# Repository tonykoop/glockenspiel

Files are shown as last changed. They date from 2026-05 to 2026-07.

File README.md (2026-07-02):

# Glockenspiel

**Status:** L2 V5 build-packet candidate; not a build-ready L3 packet (no bar
has been cut, struck, mounted, or measured yet).

V5 build-packet candidate over the root-mode v4.3 public-review packet for a 25-bar chromatic
glockenspiel / metallophone, C5 to C7, with a smaller C-major pentatonic
art-fair variant. The design uses 6061-T6 aluminum flat bars on a CNC-routed
walnut frame with cord-and-grommet free-free suspension.

Part of the [tonykoop/instrument-maker](https://github.com/tonykoop/instrument-maker)
catalogue. Sister repos: [xylophone](https://github.com/tonykoop/xylophone),
[tubular-bells](https://github.com/tonykoop/tubular-bells),
[cajon](https://github.com/tonykoop/cajon), and
[rainstick](https://github.com/tonykoop/rainstick).

## Status

This repo is a V5 build-packet candidate and L2 design/sourcing handoff, not a
build-ready L3 packet.
The bar schedule, frame plan, CAD/CNC handoffs, sourcing tables, validation
workflow, capstone deck, print packet, and static site are present for human
review. No bar has been cut, struck, mounted, or measured yet; all pitch values
are predictions until `validation.csv` contains pilot data.

The first physical pass should cut only three pilot bars: C5, A5, and C7. Cut
them long, measure them on soft node supports, compute effective K for the
actual stock lot, then update the family table before cutting the full set.

## Design Overview

- **Family:** 25 chromatic bars from C5 to C7 plus a 10-bar C-major pentatonic
  variant for short workshop or art-fair builds.
- **Governing model:** free-free metal beam in the first flexural mode,
  `f ~= K * t / L^2`, with node holes at 22.4 percent and 77.6 percent of bar
  length.
- **Primary material:** 6061-T6 aluminum, 0.250 in thick by 1.000 in wide.
  Brass, steel, stainless, and phosphor bronze alternatives are documented in
  `design.md`.
- **Frame:** black-walnut piano-keyboard layout with naturals forward, sharps
  raised behind, and stainless support rods as travel restraints.
- **Mounting:** paracord or low-stretch nylon through drilled node holes,
  supported on rubber grommets. Grommet durometer remains a pilot-build test.
- **Tuning:** cut long, measure, recalibrate K if needed, then trim ends
  symmetrically to pitch. Do not apply flute, Helmholtz, or cantilever
  empirical corrections to this free-free metal-beam model.

## Packet Map

| File / folder | What it is |
|---|---|
| `glockenspiel-design-table.xlsx` | Parametric workbook source for the active family. |
| `design.md` | Governing model, material matrix, bar schedule, frame layout, validation plan, and assumptions. |
| `family-spec.csv` | 25-bar chromatic schedule plus 10-bar pentatonic variant. |
| `bom.csv`, `sourcing.csv`, `cut-list.csv` | Build bill of materials, supplier-ready specs, and cut operations. |
| `validation.csv` | Pilot and full-family measurement workflow for flat, drilled, mounted, and framed phases. |
| `validation-loop.csv`, `authority-ledger.csv` | Claim-to-evidence gates for bar dimensions, node support, metallurgy, tuning, and frame release. |
| `visual-output-register.csv` | Validator-facing record that keeps SVG/PDF/site outputs downstream of design-table/CAD authority. |
| `assembly-manual.md` | Step-by-step fabrication and assembly notes. |
| `supplier-rfq.md` | RFQ draft for bar stock, frame stock, grommets, cord, rods, and mallets. |
| `drawing-brief.md`, `visual-bom-brief.md` | Drawing and visual BOM requirements. |
| `wolfram-starter.wl` | Parametric notebook starter for bar length, node, and validation plots. |
| `risks.md` | Red-team review of tuning, mounting, sourcing, safety, and release risks. |
| `jig-decision.md`, `resources.md` | v4.3 manufacturing-decision adjuncts and public-safe references. |
| `cad/mcp-session-log.md` | V5 provenance log for fabrication-authority artifacts (design table, family-spec, CAD masters). |
| `evolution/` | Evolution-pipeline Stage 0 intake: master manifest, design-intent, and revision register (Gate A not yet run). |
| `cad/` | OpenSCAD starter, SolidWorks master-layout plan, and design-table inputs. |
| `cnc/` | CNC operation graph and setup sheet for the walnut frame and fixtures. |
| `drawings/` | First-cut SVG sheets for bars, frame, mounting, family overview, and visual BOM. |
| `capstone-deck.md` / `.pptx` | Recruiter-facing slide deck. |
| `print-packet.md` / `.html` / `.pdf` | Shop-printable packet. |
| `site/` | Static build-log site draft. |
| `explorer.html` | Root V5 packet explorer for review status and authority boundaries. |

## V5 Candidate Review Evidence

- `jq . capstone-manifest.json` checks the repo-relative manifest.
- `test -f explorer.html` checks the Round 31 explorer deliverable.
- `python3 ${CODEX_HOME:-$HOME/.codex}/skills/instrument-maker/scripts/validate_visual_authority.py visual-output-register.csv`
  checks visual/CAD/design-table authority boundaries.
- `python3 ${CODEX_HOME:-$HOME/.codex}/skills/instrument-maker/scripts/validate_acoustic_law.py family-spec.csv`
  is expected to skip acoustic-law enforcement because this is an idiophone,
  not a wind or free-reed family.
- `git diff --check` should pass before PR.
- Existing generated binaries (`capstone-deck.pptx` and `print-packet.pdf`)
  are included as review artifacts, but they are not evidence of measured
  tuning or build readiness.

Deferred gates:

- empirical bar K calibration from C5/A5/C7 pilot cuts
- grommet-durometer sustain comparison
- final framed tuning within the cents band in `validation.csv`
- SolidWorks-native release drawing review
- live supplier price, stock, and lead-time verification
- generated SVG/PDF/site/explorer artifacts staying downstream of design-table,
  CAD, or measured authority

## License

[CC BY 4.0](LICENSE) - see LICENSE for details.

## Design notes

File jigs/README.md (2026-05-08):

# Jigs

This folder collects the build outputs of the pilot fixtures decided in `../jig-decision.md`. The decisions live there; physical jig artifacts (drawings, CNC files, photos) land here as they are built.

## Pilot Jig Set

| Jig ID | Purpose | Decision in jig-decision.md | Output here once built |
| --- | --- | --- | --- |
| JD-010 | Stock receiving / verification station | Marking and inspection only | inspection-checklist.pdf (TBD) |
| JD-020 | Stop-block sled for length and node marking | Repeatable bar marking | sled.svg, sled-build-notes.md (TBD) |
| JD-030 | Chop-saw stop block | Square cuts to length | (built and adjusted in shop; no committed file) |
| JD-040 | Drill-press V-block jig for node holes | Aligned, perpendicular drilling | vblock-jig.svg, vblock-jig-build-notes.md (TBD) |
| JD-050 | Foam node-support cradle for strike test | Acoustic measurement datum | foam-cradle-photo.jpg (TBD) |
| JD-060 | Mounting prototype rig (three walnut blocks) | Durometer pilot | mounting-rig.svg, durometer-pilot-results.csv (TBD) |
| JD-070 | Full-size frame layout template | Ergonomic reach validation | frame-template.pdf (TBD) |

## Pilot Gate

Build only JD-010 through JD-050 for the C5/A5/C7 pilot. JD-060 follows after pilot bars are trimmed. JD-070 follows after the durometer is selected. JD-070 must be ergonomically verified before any walnut is cut.

See `../jig-decision.md` for full pass/fail criteria and the rejected fixture options.

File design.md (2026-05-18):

# Glockenspiel Design Packet

## Project Intent

Build a 25-bar chromatic C5-C7 glockenspiel from the existing workbook design table, with a parallel 10-bar C-major-pentatonic art-fair variant that shares the same aluminum stock, frame jig, and validation discipline. The first build target is a CNC-routed walnut frame carrying 6061-T6 aluminum bars, suspended at the free-free nodes by rubber-grommeted cord through drilled node holes, with stainless support pins and no resonators.

The useful boundary for this packet is "build-ready documentation, not finished CAD or measured tuning data." Native SolidWorks files do not exist yet; the `cad/` folder defines the global-variable and design-table contract Tony can use to build the real model. All published bar lengths are first-pass cut-long targets — actual K varies with heat-treat and stock lot, so every bar should be cut at predicted length plus 0.25 in trim allowance and tuned down to pitch.

Round 31 adds an explicit V5 authority layer: `authority-ledger.csv`,
`validation-loop.csv`, and `visual-output-register.csv`. Those files do not
promote the packet to build-ready status; they make clear which claims are
design-table-derived, which are supplier/material assumptions, and which are
blocked on measured pilot evidence.

## Design Intake

| Field | Value |
| --- | --- |
| Instrument | Glockenspiel / Metallophone |
| Instrument family | Free-free beam idiophone (metal), no arch, no resonator |
| Active build range | C5-C7 chromatic, 25 bars (primary); C-major pentatonic, 10 bars (art-fair variant) |
| Source workbook | `glockenspiel-design-table.xlsx`, sheet `Glockenspiel`, range `A1:L174` |
| Primary material | 6061-T6 Aluminum, workbook K constant `204431` |
| Bar stock | `0.25 in` thick x `1.00 in` wide flat bar |
| Frame | CNC-routed Black Walnut, piano-keyboard layout (naturals front, sharps back) |
| Mounting | Cord through node holes at 22.4% and 77.6% of bar length, rubber grommets, 1/8 in stainless support rod |
| Done-bar reference | `tonykoop/marimba` for free-free node math and validation discipline; tongue-drum README for documentation shape |

## Governing Model

### Bar Pitch (Free-Free Beam, Metal)

Glockenspiel bars are treated as free-free beams in their first flexural mode:

```text
lambda_1 = 4.730
f_1 = (lambda_1^2 / (2*pi*L^2)) * sqrt(E*I/(rho*A))
```

The workbook uses the practical shop form:

```text
f ~= K * t / L^2
L ~= sqrt(K * t / f)
```

where:

- `f` is target frequency in Hz.
- `K` is the metal-specific free-free bar constant in imperial units.
- `t` is bar thickness in inches.
- `L` is bar length in inches.

For the active packet:

```text
material = 6061-T6 Aluminum
K = 204431
t = 0.250 in
w = 1.000 in
```

The K formula derived from the lambda_1 = 4.730 mode shape is:

```text
K_metal = (lambda_1^2 / (2 * pi)) * sqrt(E / (12 * rho)) / 0.0254
```

with `E` in Pa and `rho` in kg/m^3. This is the same formula family used by the marimba for wooden bars; only the material constants change.

Width does NOT affect frequency for a free-free beam in this mode. Width controls volume, sustain envelope, stiffness distribution, and the visual dimension of the bar — not pitch. The workbook's bar-width column is a sourcing convenience, not a tuning lever.

### No Arch, No Resonator

Per workbook row 140 and `references/acoustic-models.md`:

- **No arch undercut.** Glockenspiel bars are short and high-pitched; the dry, bright tone is desired. Arching would lower fundamentals and add manufacturing complexity without improving the instrument's musical role. Marimba/xylophone arch logic does not transfer.
- **No resonator tubes.** Small bars produce an immediate, bell-like attack. Resonator coupling at C5-C7 frequencies would require very short tubes (a few inches at C5, less than 1.5 in at C7) that are mechanically awkward and acoustically marginal.

### Empirical-Correction Discipline

NAF K2 corrections, vessel-flute Helmholtz corrections, and cantilever wood K-constant tables do **not** apply to free-free metal beams. See the "Empirical-correction guard rules" section of `references/acoustic-models.md`. The only honest correction loop here is:

1. Cut each pilot bar (C5, A5, C7) cut-long by 0.25 in.
2. Mount on soft node supports and measure flat-bar Hz.
3. Compute effective K from `K_eff = f * L^2 / t`.
4. If pilot K_eff differs from workbook K by more than 5%, update the K constant in `family-spec.csv` (and the workbook B21 cell) before cutting the remaining bars.
5. Trim to pitch in 0.05 in increments.

This is what makes the workflow honest: predicted lengths are the starting point, measured Hz is the ground truth, and each shop-purchased lot of aluminum re-calibrates K.

### Nodes And Mounting

Free-free node positions are fixed by the mode shape:

```text
node_1 = 0.2242 * L
node_2 = 0.7758 * L
```

Mounting strategy:

- Drill 0.1875 in (3/16 in) holes through the bar at the node positions, perpendicular to the long face.
- Thread 550 paracord (or low-stretch nylon) through the four node holes (two per bar, one cord per row).
- Rest each bar on rubber grommets seated in the walnut frame; the cord captures the bar without compressing the grommets.
- 1/8 in stainless steel rod runs the length of each row through the frame as a backup and travel restraint.

Critical: the rubber grommet durometer dominates sustain. Soft (~Shore 30A) grommets give long sustain; hard (~Shore 70A) grommets damp quickly. Pilot the C5/A5/C7 bars on three durometers before standardizing.

## Material Decision Matrix

The workbook's K library carries five candidate metals. Aluminum is the workbook default and packet primary. Surface the alternatives explicitly so the user can rerun the family-spec for any of them.

| Material | E (GPa) | rho (kg/m^3) | K | Tone Character | Cut Method | Notes |
| --- | ---: | ---: | ---: | --- | --- | --- |
| 6061-T6 Aluminum | 68.9 | 2700 | 204431 | Bright, bell-like, long sustain | Band saw, chop saw | Lightest, easiest to cut, lowest cost. Packet default. |
| Brass C260 | 110 | 8530 | 145325 | Warm, mellow, classic glock tone | Band saw, hacksaw | Heavier, traditional orchestra-bell tone, higher material cost. |
| Steel 1018 | 200 | 7850 | 204267 | Harsh, metallic, very loud | Chop saw, angle grinder | Loud and bright; can be perceived as harsh. K is similar to aluminum because E/rho ratio is similar. |
| 304 Stainless Steel | 193 | 8000 | 198770 | Clean, modern, corrosion-resistant | Chop saw, angle grinder | Outdoor / weather-resistant variant. |
| Phosphor Bronze | 110 | 8860 | 142593 | Rich, warm, excellent sustain | Band saw | Premium tone, highest material cost. |

To rebuild the family-spec for a different metal: replace the K column in `family-spec.csv` and recompute `predicted_length_in = sqrt(K * t / f)`. Width and node positions stay the same.

## Bar Schedule

The full 25-bar chromatic schedule is in `family-spec.csv`. Representative rows for 6061-T6 aluminum at t=0.250, w=1.000:

| Note | MIDI | Target Hz | Length in | Node 1 in | Node 2 in |
| --- | ---: | ---: | ---: | ---: | ---: |
| C5 | 72 | 523.251 | 9.883 | 2.216 | 7.667 |
| A5 | 81 | 880.000 | 7.621 | 1.709 | 5.912 |
| C6 | 84 | 1046.502 | 6.988 | 1.567 | 5.422 |
| A6 | 93 | 1760.000 | 5.389 | 1.208 | 4.181 |
| C7 | 96 | 2093.005 | 4.941 | 1.108 | 3.834 |

The 10-bar pentatonic art-fair variant (C5, D5, E5, G5, A5, C6, D6, E6, G6, A6) is also in `family-spec.csv` under `scale_label = C major pentatonic art-fair`. It shares the same K, t, w defaults and reuses the same frame jig with different drill positions.

## Frame Layout

Piano-keyboard layout. Naturals (C, D, E, F, G, A, B) live in the front row; sharps/flats live in the back row, raised about 0.5 in. From the workbook (cells B107-B110):

```text
total_bar_stock_chromatic = 191.02 in (~16 ft) for 25 bars cut long by 0.5 in each
longest_bar = 9.883 in (C5)
shortest_bar = 4.941 in (C7)
chromatic_frame_length = 25 * (w + 0.25) + 2 = 33.25 in
pentatonic_frame_length = 10 * (w + 0.25) + 2 = 14.50 in
```

Frame depth follows the longest bar plus 1 in margin on each end (about 12 in). Final frame ergonomics (height, mallet reach, accidental row offset, transport handles) are TBD until a full-size mock-up is taped on a bench.

## Striker Hardness

Striker hardness controls the timbre as much as the bar material does. Workbook row 145 lists three options:

| Striker Head | Tone | Use |
| --- | --- | --- |
| Brass | Sharpest attack, bright, percussive | Orchestral / soloist; loud rooms |
| Hard rubber | Balanced bright/warm | Studio / classroom; default for art-fair pentatonic |
| Lexan / Delrin | Bright but less metallic than brass | Solo work; chimes |

Include at least two pairs in the BOM; let the player choose by context.

## Hardware Alignment

| Operation | Tool / Fixture | Datum | Release Check |
| --- | --- | --- | --- |
| Bar receiving | Calipers, scale, scratch awl | Edge of stock | Verify thickness 0.25 +/- 0.005 in, width 1.00 +/- 0.010 in, no surface damage |
| Mark length and nodes | Stop-block sled, square, fine marker | Left end B, centerline C | Length within +/- 0.020 in of `predicted_length_in + 0.25` (cut long); nodes within +/- 0.020 in |
| Cut to length | Band saw or chop saw with stop block | Left end B | Squareness within 0.5 deg; deburr both ends |
| Drill node holes | Drill press with V-block fence and backer | Centerline C, node line | Hole diameter 0.1875 +/- 0.005 in; perpendicular within 1 deg; no edge tear-out |
| Deburr / file | Bench file, deburring tool, sandpaper | Top face A | Edges chamfered 0.005-0.010 in; node holes deburred |
| Strike test (flat) | Soft foam supports at nodes, tuner, mic | Acoustic node | Record measured Hz, cents error, sustain s in `validation.csv` |
| Trim to pitch | Belt sander or fine file at the ends | Acoustic-tuning datum | Remove material symmetrically from both ends; sneak up slowly (raising pitch is hard to reverse) |
| Mount | Walnut frame jig, paracord, grommets, 1/8 in stainless rod | Frame centerline | All bars seated; cord captures every bar; no metal-on-metal contact |
| Final tune (framed) | Frame on bench, tuner, mallets | Frame centerline | Every bar within +/- 5 cents at soft/medium dynamics |

`jig-decision.md` is the controlling fixture decision record. Pilot fixtures (cut sled, node-drill V-block jig, mounting test rig) are built only for C5/A5/C7 before the full 25-bar run.

## Open Assumptions

- Active packet uses C5-C7 (workbook default). Lower-pitched bass-glock variants (C4-C6) are out of scope for this build.
- 6061-T6 aluminum is the workbook-selected material. Actual stock lot K may differ by 5-10%. The validation pilot is the K-recalibration step, not a confirmation.
- Mounting cord material, grommet durometer, and stainless rod diameter are first-pass picks — pilot at three durometers before freezing.
- Walnut frame geometry, mallet selection, and accidental row offset are TBD until a full-size taped layout passes ergonomic review.
- Final finish on bars: leave raw or clear-coat. Clear coats add mass; expect a small flat-pitch shift (typically <5 cents). Tune after finish if a finish is applied.
- No measured bar data exists yet, so all frequencies are target predictions.

## Validation Plan

1. Cut three pilot bars first: C5, A5, C7. Cut each to `predicted_length_in + 0.25`.
2. Mass-and-strike test on foam supports before drilling node holes (`flat_bar` row in `validation.csv`). Compute K_eff = f * L^2 / t.
3. If pilot K_eff differs from workbook K = 204431 by more than 5%, update the K column in `family-spec.csv` and the workbook B21 cell before cutting the remaining bars.
4. Drill node holes; mount on cord+grommet rig (`mounted` row). Record measured Hz, cents error, and sustain (time to first 6 dB drop after a moderate strike).
5. Trim each pilot to within +/- 10 cents by removing material symmetrically from both ends. Cents error formula:

```text
cents = 1200 * log2(measured_hz / target_hz)
```

6. Mount in the walnut frame (`framed` row). Strike at soft, medium, and loud dynamics; check for buzz, rubber-on-stainless-rod rattle, and frame resonance.
7. Cut the remaining 22 chromatic bars (and 7 additional pentatonic bars if building both) using the calibrated K and the pilot trim discipline.
8. Final assembly check: every bar within +/- 5 cents at soft dynamics, no buzz, sustain consistent across the row to within 30%.

## Provenance

- Source workbook: `glockenspiel-design-table.xlsx`, generated before this v4.3 packet run. 94 formulas, 16 blue inputs, single sheet `Glockenspiel`.
- Skill workflow: `instrument-maker-v4` v4.3 root-mode.
- Reference family: `cantilever-idiophone` / `free-free-bar-idiophone`. Done-bar sibling: `tonykoop/marimba`.
- Cultural context: glockenspiel is a modern Western orchestral idiophone (German "bells play") derived from 18th-19th century military-band bell sets and Berlioz-era orchestral bells. No cultural-appropriation review required for the instrument category.

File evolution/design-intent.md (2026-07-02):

# Design Intent — glockenspiel rev A

- Master CAD: `cad/glockenspiel-master.scad` (sha256: 6bb210bba8452f248684d01d71052a385e7ed5c14e3fd130ca833ccd071a694d), driven by `glockenspiel-design-table.xlsx` (sha256: 0a42e519640701522017ba7fabde0a9fcf048d87f90b3904651a0452c12441e3)
- Function: 25-bar chromatic (C5-C7) free-free metal-beam idiophone with a 10-bar C-major pentatonic art-fair variant. 6061-T6 aluminum flat bars (0.25 in x 1.00 in) mounted node-to-node with cord/grommet suspension on a CNC-routed walnut piano-keyboard frame; struck bars, no arch undercut, no resonator (design.md Project Intent).
- Environment: struck idiophone, indoor use; bar pitch depends on stock lot's effective K constant, which is not yet pilot-calibrated (risks.md Bar pitch misses workbook prediction).
- Target qty: 1 (prototype, pilot-first: cut only C5/A5/C7 before the full 25-bar set). Deadline: TBD. Budget/unit ceiling: TBD.

## Critical dimensions (carry tolerances)

| Feature | Nominal | Tolerance | Why critical | Source |
| --- | --- | --- | --- | --- |
| Bar length (per note) | e.g. GLK-C5 9.883 in | cut long +0.25 in, trim to pitch | pitch accuracy | family-spec.csv predicted_length_in (design_table_backed, K not yet pilot-calibrated) |
| K constant (6061-T6 Aluminum) | 204431 | +/-5% pilot calibration gate | pitch model accuracy | design.md Governing Model; risks.md Bar pitch risk |
| Bar thickness / width | 0.250 in / 1.000 in | stock tolerance | pitch model input (`f ~= K*t/L^2`) | design.md Design Intake, family-spec.csv |
| Node hole positions | 22.4% / 77.6% of L | sustain/pitch-shift gate (<=5 cents) | mount without damping fundamental | design.md Mounting; risks.md Mounting damps fundamental |
| Grommet durometer | TBD (Shore 30A/50A/70A pilot candidates) | sustain >=3s (C5), >=1.5s (A5), >=0.8s (C7) | sustain, pitch stability | risks.md Mounting damps fundamental or kills sustain |

## Incidental (free for DFM)

- Frame cosmetic styling (walnut grain selection, finish); striker material choice (documented trade-off, not a structural gate per risks.md Striker hardness).

## Must-nots (DFM may never violate)

- Do not cut the full 25-bar set before the C5/A5/C7 pilot bars produce a measured K_eff within 5% of the workbook K (design.md, risks.md Bar pitch risk).
- Node holes must stay at the free-free model's 22.4%/77.6% positions — any support contact away from the node line is a sustain-killing defect (risks.md Mounting damps fundamental).
- Do not apply flute, Helmholtz, or cantilever empirical corrections to this free-free metal-beam model (README Design Overview).
- Drilling must use a backer board and deburr both faces to avoid cracked bars (risks.md Drilling node holes splits or burrs the aluminum).

## Material intent

- Preferred: 6061-T6 aluminum bar stock; black walnut frame; stainless support rod; rubber grommets (durometer TBD pending pilot test) — see bom.csv/sourcing.csv.
- Acceptable subs: brass, steel, stainless, phosphor bronze bar alternatives documented in design.md material matrix.
- Forbidden: none recorded.

## Stage status

Stage 0 intake complete 2026-07-01. Gate A (Alpha shop compile) NOT yet run — no concessions logged, nothing presented as shippable.

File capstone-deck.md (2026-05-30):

# Glockenspiel — Tuned Metal-Bar Idiophone Build Packet
- Musical instrument documentation capstone
- Build packet: glockenspiel
- Generated: 2026-05-08

---

# Project Intent
- Build a 25-bar chromatic C5-C7 glockenspiel from the existing workbook design table, with a parallel 10-bar C-major-pentatonic art-fair variant sharing the same aluminum stock and frame jig.
- 6061-T6 aluminum bars (0.25 in × 1.00 in flat stock) on a CNC-routed Black Walnut frame.
- Free-free beam acoustics, no arch undercut, no resonator tubes.
- Cord-through-node-holes mounting with rubber grommets and 1/8 in stainless support rods.
- All published lengths are first-pass cut-long targets; effective K is recalibrated from a C5/A5/C7 pilot.

_Speaker notes:_ Read design.md before committing to dimensions or sourcing decisions. The K-calibration pilot is non-optional.

---

# Physics Model
- ### Free-Free Beam (Metal)

```
lambda_1 = 4.730
f_1 = (lambda_1^2 / (2*pi*L^2)) * sqrt(E*I/(rho*A))
```

```
f ~= K * t / L^2
L ~= sqrt(K * t / f)
```

```
material = 6061-T6 Aluminum
K = 204431 (imperial: t and L in inches, f in Hz)
t = 0.250 in
w = 1.000 in
```

```
K_metal = (4.730^2 / (2*pi)) * sqrt(E / (12*rho)) / 0.0254
node_1 = 0.2242 * L
node_2 = 0.7758 * L
```

_Speaker notes:_ Width does NOT affect frequency. Per `references/acoustic-models.md`, NAF K2 corrections, vessel Helmholtz corrections, and cantilever wood K-tables do NOT apply. The honest correction loop is per-lot K calibration from pilot measurements.

---

# Material Decision Matrix
- 6061-T6 Aluminum (default): K=204431, bright bell-like, long sustain, lowest cost.
- Brass C260: K=145325, warm classic glock tone, premium cost.
- Steel 1018: K=204267 (similar to Al), harsh and very loud.
- 304 Stainless: K=198770, clean modern tone, weather-resistant.
- Phosphor Bronze: K=142593, richest sustain, highest cost.
- To switch metals: replace K in `family-spec.csv` and recompute `predicted_length_in = sqrt(K*t/f)`.

_Speaker notes:_ Aluminum and Steel have nearly identical K because the E/rho ratio is similar; the practical difference is mass and timbre, not length.

---

# Bar Schedule (chromatic + pentatonic)
- 25 chromatic bars C5-C7 (full schedule in `family-spec.csv`).
- 10 pentatonic bars (C5,D5,E5,G5,A5,C6,D6,E6,G6,A6) — art-fair "no wrong notes" variant.

| Note | MIDI | Target Hz | Length in | Node 1 in | Node 2 in |
| --- | ---: | ---: | ---: | ---: | ---: |
| C5 | 72 | 523.251 | 9.883 | 2.216 | 7.667 |
| A5 | 81 | 880.000 | 7.621 | 1.709 | 5.912 |
| C6 | 84 | 1046.502 | 6.988 | 1.567 | 5.422 |
| A6 | 93 | 1760.000 | 5.389 | 1.208 | 4.181 |
| C7 | 96 | 2093.005 | 4.941 | 1.108 | 3.834 |

_Speaker notes:_ Lengths assume K = 204431. Always cut at predicted + 0.25 in trim allowance. K_eff is calibrated from pilot bars before the full run.

---

# Mounting And Frame
- Piano-keyboard layout: naturals (15) front row, sharps/flats (10) back row raised 0.5 in.
- Each bar drilled with 3/16 in node holes; cord captures the bar at both nodes.
- Rubber grommets seat in CNC-routed walnut pockets; durometer (Shore 30A/50A/70A) chosen via pilot.
- 1/8 in stainless rod runs full row length as backup restraint (must NOT contact bar).
- Frame envelope: 33.25 in (chromatic) or 14.50 in (pentatonic) wide × ~12 in deep.

_Speaker notes:_ Mounting damping is the structural risk that dominates sustain. See `risks.md`.

---

# Hardware Alignment
- Bar marking & cutting: bench-top (chop saw + stop-block sled).
- Node hole drilling: drill press + V-block jig + hardwood backer.
- Bar tuning: belt sander or fine bench file, symmetric trim.
- Frame routing: CNC router (the only true CNC operation in this build).
- Mounting: cord + grommet + stainless rod, all bench-top.
- Validation: chromatic tuner (>= 2 kHz), microphone for sustain logging.

_Speaker notes:_ The frame is the only CNC step. Everything else is bench-top with simple jigs from `jig-decision.md`.

---

# How To Use This Packet
- Start with design.md for intent and assumptions.
- Use bom.csv, sourcing.csv, and cut-list.csv before buying or cutting.
- Use drawing-brief.md, drawings/, cad/, and cnc/ before machining.
- Use jig-decision.md as the shop stop/go sheet.
- Use validation.csv as the K-calibration and tuning log.
- Print the packet for shopping, shop work, and validation.

---

# File Map
- design.md: Project intent, governing model, material decision matrix, mounting strategy, validation plan.
- family-spec.csv: 25 chromatic + 10 pentatonic bar dimensions.
- bom.csv: Bar set + frame + hardware + mallets + tooling + measurement gear.
- sourcing.csv: Supplier candidates with all prices marked "not verified".
- cut-list.csv: Bar stock, walnut frame stock, jig material.
- validation.csv: prebuild rows for all 35 bars + per-stage rows (flat_bar/post_trim/mounted/framed) for C5/A5/C7 pilots.
- assembly-manual.md: Pilot-first build philosophy and full bench workflow.
- supplier-rfq.md: RFQ template covering aluminum + alternates + walnut + hardware + tooling.
- drawing-brief.md: Five drawing classes with tolerances.
- visual-bom-brief.md: Image-forward BOM plate spec.
- risks.md: Acoustic / structural / ergonomic / supply / fit-finish risk register.
- photo-shotlist.md: Build-log photo plan.
- resources.md: Provenance, family context, public-safety inventory.
- jig-decision.md: Pilot fixture decisions and release gates.
- drawings/: Per-pilot bar SVGs, family-overview, frame-layout, mounting-detail, visual-bom-plate.
- cad/: OpenSCAD master + SolidWorks contract (CSV + plan).
- cnc/: cnc-plan.json, operations.csv, setup-sheet.md (frame-routing focus).
- jigs/: Pilot fixture artifacts as built.
- wolfram/: glockenspiel-wolfram-model.wl with kMetal/lBar/Manipulate/validation plot.
- site/: Build-log static site.

---

# Family Spec

| Note | MIDI | Hz | L in | Node 1 | Node 2 |
| --- | ---: | ---: | ---: | ---: | ---: |
| C5 | 72 | 523.251 | 9.883 | 2.216 | 7.667 |
| C#5 | 73 | 554.365 | 9.602 | 2.153 | 7.449 |
| D5 | 74 | 587.330 | 9.328 | 2.091 | 7.237 |
| E5 | 76 | 659.255 | 8.805 | 1.974 | 6.831 |
| G5 | 79 | 783.991 | 8.074 | 1.810 | 6.264 |
| A5 | 81 | 880.000 | 7.621 | 1.709 | 5.912 |
| C6 | 84 | 1046.502 | 6.988 | 1.567 | 5.422 |
| E6 | 88 | 1318.510 | 6.226 | 1.396 | 4.830 |
| A6 | 93 | 1760.000 | 5.389 | 1.208 | 4.181 |
| C7 | 96 | 2093.005 | 4.941 | 1.108 | 3.834 |

_Speaker notes:_ Full 25-bar schedule plus 10-bar pentatonic block in family-spec.csv. All values first-pass; pilot K calibration corrects them.

---

# Build Workflow
- Receive aluminum stock and verify dimensions.
- Mark bar lengths and node positions per family-spec.csv.
- Cut bars to length (cut long by 0.25 in).
- Drill node holes on drill press with V-block jig.
- Strike-test pilot bars (C5/A5/C7) on foam supports; calibrate K_eff.
- Trim to pitch with symmetric end removal.
- CNC-route walnut frame rails and grommet pockets.
- Run mounting prototype rig with three durometer grommets.
- Assemble frame and mount all bars.
- Final validation: every bar within +/- 5 cents at soft dynamic.

---

# Sourcing And BOM
- Primary metal: 6061-T6 Aluminum 1/4" × 1" flat bar (~18 ft for chromatic + pentatonic + scrap).
- Frame: Black Walnut 4/4 dressed to 3/4" thick (about 6 board feet).
- Hardware: paracord, three durometer grommets, 1/8" stainless rod, rubber feet, fasteners.
- Mallets: hard rubber (default) + brass (orchestral upgrade) + optional lexan/Delrin.
- Tooling: 1/4" downcut + 1/8" upcut router bits, 3/16" drill bit, 80T non-ferrous chop-saw blade.
- Measurement: chromatic tuner with 2 kHz+ range (Peterson StroboClip HD).
- All sourcing.csv prices marked "not verified" — verify before purchase.

---

# Shop Packet
- cut-list.csv for stock planning.
- assembly-manual.md for away-from-keyboard work.
- validation.csv for measured Hz, cents error, sustain, timbre.
- Pilot gate: don't cut all 25 bars until C5/A5/C7 pass `flat_bar`, `post_trim`, `mounted`, `framed`.

---

# Drawings, CAD, CNC
- drawing-brief.md defines required views and tolerances.
- drawings/ has three pilot bar SVGs + family-overview + frame-layout + mounting-detail + visual-bom-plate.
- cad/ has OpenSCAD master + SolidWorks contract (CSV + plan).
- cnc/ has the frame-routing operation graph (no bar CNC).
- jigs/ collects pilot fixture artifacts.









---

# Validation Plan
- Pilot: cut C5, A5, C7 cut-long; mass-and-strike test; compute K_eff = f * L^2 / t.
- If pilot K_eff differs from workbook K by more than 5%, update family-spec.csv and workbook B21 before cutting remaining bars.
- Trim each bar to within +/- 10 cents (pilots) or +/- 5 cents (production) by symmetric end removal.
- Mount on prototype rig with three durometer grommets; pick the one that preserves >= 75% of flat-bar sustain.
- Mount all bars on walnut frame; run final framed validation row.
- Cents error: cents = 1200 * log2(measured_hz / target_hz).

---

# Open Risks / Decisions
- Aluminum mill-lot K variance can shift pitch 5-10%; pilot calibrates per lot.
- Grommet durometer dominates sustain; pilot Shore 30A/50A/70A before standardizing.
- Striker hardness (brass / hard rubber / lexan) shifts timbre dramatically; ship at least two pairs.
- Frame ergonomics (bar reach, accidental row offset, transport) need full-size taped layout.
- Clear-coat finish on aluminum can shift pitch 3-10 cents flat; tune after finish or leave raw.
- Workbook K constants (B16-B20) are first-pass; recalibrate per lot from pilot data.

---

# Next Actions
- Cut C5/A5/C7 pilot bars and measure K_eff.
- Pilot the three durometer grommets; pick one and record decision.
- CNC-route the walnut frame after K and durometer are confirmed.
- Cut the remaining 22 chromatic bars (or 7 pentatonic) using calibrated K.
- Assemble, validate, photograph, and update validation.csv.
- Replace TBDs with measured/source-backed values.
- Verify live supplier prices and availability before buying.

---

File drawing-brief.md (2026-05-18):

# Drawing Brief

## Drawing Set

The current packet requires five build-critical drawing classes:

1. **Per-bar dimensioned SVGs** for the three pilot bars (`drawings/GLK-C5-body.svg`, `drawings/GLK-A5-body.svg`, `drawings/GLK-C7-body.svg`). These show the long flat bar, node-hole positions, length dimension, thickness, and a title block. Additional per-bar SVGs can be generated from `family-spec.csv` if the full chromatic set is required.
2. **Family overview** (`drawings/family-overview.svg`) — scaled side-by-side outline of all 25 chromatic bars from C5 (longest) to C7 (shortest), labeled with note + Hz + length, to show the visual tuning gradient.
3. **Frame layout** (`drawings/frame-layout.svg`) — top-down piano-keyboard layout with naturals in the front row, sharps/flats in the back row raised 0.5 in. Shows bar spacing, accidental row offset, frame envelope, and player-side datum.
4. **Mounting detail** (`drawings/mounting-detail.svg`) — section view through one bar at a node showing: bar profile, 3/16 in node hole, paracord, rubber grommet, walnut frame pocket, and 1/8 in stainless support rod position. Critical for explaining why the bar is acoustically isolated from the frame.
5. **Visual BOM plate** (`drawings/visual-bom-plate.svg`) — exploded callout of bar set, frame rails, hardware, and tooling with numbered references to `bom.csv`.

## Drawing Standards

- Units: inches.
- Primary datum for each bar: left end (B) and centerline (C). Top face (A) is implicit.
- Node holes shown at `0.2242 * L` and `0.7758 * L` from the left end.
- Bar dimensions to call out: length, width, thickness, node positions, hole diameter (3/16 in).
- Frame dimensions: rail length, rail thickness, accidental row offset, grommet pocket diameter and depth, support rod hole diameter.
- Tolerances:
  - Bar length cut: `+0.250 in / -0.000 in` before tuning (cut long).
  - Final length: tune-to-pitch, not dimension-only.
  - Thickness: `+/- 0.005 in` (verified at receiving).
  - Node hole placement: `+/- 0.020 in`.
  - Frame pocket: `+/- 0.010 in`.
- CNC notes: bit diameter, stepover, Z-zero surface, tabs, workholding, and release checks per `cnc/setup-sheet.md`.
- Jig notes: which fixture carries datum A/B/C and which validation row releases the operation.

## Open Drawing Questions

- Whether to generate per-bar SVGs for all 25 chromatic notes or only the three pilots.
- Final accidental row offset (currently 0.5 in raised; ergonomic test may reduce).
- Final grommet pocket depth (depends on selected grommet supplier).
- Whether the optional Broinwood-style inlay on rail sides gets a dedicated detail drawing.
- Whether to draw the brass/steel/stainless/phosphor-bronze alternate-metal variants.

## Source Files

- `family-spec.csv` (canonical bar dimensions)
- `design.md` (governing model, mounting strategy)
- `glockenspiel-design-table.xlsx` (parametric workbook)
- `cad/glockenspiel-master.scad` (3D starter)
- `cad/SolidWorks-MasterLayout-Plan.md` (SolidWorks contract)
- `cnc/setup-sheet.md` (operation order, datums)
- `jig-decision.md` (fixture release gates)
- `visual-output-register.csv` (visual authority chain)
- `authority-ledger.csv` (bar/node/metallurgy/tuning evidence gates)

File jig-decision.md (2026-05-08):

# Glockenspiel Jig Decision Record

Generated: 2026-05-08

## Purpose

This file is the manufacturing decision layer for the glockenspiel packet. The design table gives bar dimensions; the CNC setup sheet gives operations on the walnut frame. This record decides which jigs earn their way into the first build, what each jig controls, and which validation row proves the decision worked.

The active recommendation is a staged jig system, not one universal fixture. The pilot build should make only the jigs needed to cut, drill, and mount C5, A5, and C7. The remaining 22 chromatic bars wait until those three pilot bars validate K-constant, node-hole geometry, and mounting damping.

## Source Inputs

| Source | Used for |
| --- | --- |
| `family-spec.csv` | Bar length, width, thickness, node positions per note. |
| `design.md` | Free-free metal beam model, mounting strategy, K-calibration discipline. |
| `cnc/setup-sheet.md` | Operation sequence, datum scheme, tool list, pilot gate. |
| `drawings/GLK-C5-body.svg`, `GLK-A5-body.svg`, `GLK-C7-body.svg` | Per-pilot dimensioned drawings. |
| `drawings/mounting-detail.svg` | Node-hole + grommet + cord + stainless-rod section. |
| `drawings/frame-layout.svg` | Piano-keyboard layout, naturals-front / sharps-back rows. |
| `validation.csv` | Measurement rows that decide whether to scale from pilot to full set. |

## Datum Rules

| Datum | Meaning | Must survive |
| --- | --- | --- |
| A | Top face of the bar | Cut to length, drill, deburr, strike test, mounting. |
| B | Left end of the bar | Length mark, node mark 1, drill hole 1. |
| C | Bar centerline | Node hole drilling, mounting, frame layout. |

If a jig loses A/B/C, the bar is no longer traceable to `family-spec.csv`; stop and remark before cutting.

## Pilot Decision

| Pilot bar | Why it is in the pilot | Pass gate before full set |
| --- | --- | --- |
| C5 | Longest bar (9.883 in), lowest pitch (523 Hz). Validates the workbook K constant against the actual stock. | Cut-long blank Hz produces K_eff within 5% of workbook K. Measured Hz after trim within +/- 10 cents of target. Sustain >= 3 s. |
| A5 | A5 = 880 Hz reference (one octave above orchestral A4). Mid-scale K check. | Measured Hz within +/- 5 cents of 880 Hz after trim. Mounting does not damp below 1.5 s sustain. |
| C7 | Shortest bar (4.941 in), highest pitch (2093 Hz). Validates dimensional sensitivity (a 0.025 in length change shifts pitch ~1%). | Trim discipline can land C7 within +/- 10 cents in 0.05 in length increments. Striker hardness is musical, not harsh. |

Full production is blocked until these rows in `validation.csv` have measured values: `flat_bar`, `post_trim`, `mounted`, `framed` for C5, A5, and C7.

## Decision Matrix

| Decision ID | Operation | Chosen jig | Why this choice | Go/no-go test |
| --- | --- | --- | --- | --- |
| JD-010 | Receive and verify aluminum stock | Calipers, scratch-awl marking station | Stock dimension and surface quality must be confirmed before cut planning. | Thickness 0.250 +/- 0.005 in, width 1.000 +/- 0.010 in, no deep scratches in playing area. |
| JD-020 | Mark bar length and node positions | Stop-block sled with scribe and centerline gauge | Repeatability matters more than speed; a misplaced node hole damps the bar. | Length within +/- 0.020 in of `predicted_length_in + 0.25`; node 1/2 within +/- 0.020 in of `0.2242·L` and `0.7758·L`. |
| JD-030 | Cut to length | Chop saw with carbide non-ferrous blade and stop block, OR band saw with miter gauge | Chop saw is faster and squarer; band saw is safer for short pilot bars. Pick one and document. | Cut squareness <= 0.5 deg from perpendicular; deburred to no-snag. |
| JD-040 | Drill node holes | Drill press with V-block jig referenced to centerline, hardwood backer, depth stop | Holes off-axis or off-node will damp the bar; the V-block + backer is the standard pattern. | Holes 0.1875 +/- 0.005 in, perpendicular within 1 deg, no edge tear-out, deburred both faces. |
| JD-050 | Strike-test on pilot supports | Foam-block node-support cradle, dynamic mic, tuner | A consistent acoustic datum is required to compare flat vs mounted vs framed. | Same support spacing every test; measured Hz repeatable within 2 cents across three strikes. |
| JD-060 | Mounting prototype rig | Three short walnut blocks (drilled for grommets, slotted for cord, drilled for stainless rod), test cord | Sustain depends on grommet durometer and cord tension; need to test before frame routing. | Pilot bars retain >= 75% of flat-bar sustain when mounted. |
| JD-070 | Walnut frame layout template | Full-size paper or MDF template marked with chromatic bar positions, sharps/naturals rows, hand zones | Player reach must be validated before cutting walnut. | Player reaches all bars without shoulder strain; mallet trajectory clear of frame. |

## Rejected Fixture Options

| Rejected option | Reason |
| --- | --- |
| Single 25-bar CNC nest for all node-hole drilling | Too much aluminum in one fixture before pilot K is confirmed; one wrong K kills the lot. |
| Permanent press-fit grommets in finished walnut frame | Locks in durometer choice before pilot sustain test; rework requires destroying the frame. |
| Final furniture-grade walnut frame on first build | The frame should validate ergonomics, mallet reach, and grommet durometer before final joinery. |
| Resonator tubes under each bar | Out of scope per workbook §3 row 140; small bars at C5-C7 do not benefit from quarter-wave coupling at usable tube lengths. |
| Arch undercut (marimba-style) | Out of scope per workbook §3; metal bars want a dry, bright tone, not lowered fundamental. |

## Jig Build Order

1. Build only JD-010 through JD-050 for the pilot set.
2. Cut and measure C5, A5, C7 through `flat_bar` and `post_trim` validation rows.
3. Confirm K_eff and trim discipline before drilling node holes on remaining bars.
4. Build JD-060 (mounting prototype) with three durometer candidates; measure sustain.
5. Build JD-070 (frame template) and validate reach.
6. Cut the remaining 22 chromatic bars (and 7 additional pentatonic bars if both scales are being built) using the calibrated K and trim discipline.
7. Route the walnut frame; mount all bars; run final `framed` validation row.

## Validation Rows To Preserve

| Row pattern | Purpose | Release threshold |
| --- | --- | --- |
| `flat_bar` | Cut-long blank Hz; K-calibration. | K_eff within 5% of workbook K, or workbook K updated. |
| `post_trim` | After trim-to-length and deburr; supports at nodes. | Within +/- 10 cents of target Hz for pilot bars. |
| `mounted` | After cord + grommet + stainless rod mounting on test rig. | Sustain >= 75% of flat-bar sustain; pitch shift <= 5 cents. |
| `framed` | After installation in final walnut frame. | Within +/- 5 cents at soft dynamics; no buzz at any dynamic. |

## Open Decisions

- Final grommet durometer (Shore 30A vs 50A vs 70A) remains TBD until pilot sustain measurements.
- Striker hardness selection (brass vs hard rubber vs lexan/Delrin) — at minimum two pairs ship with the instrument; let the player pick.
- Whether the first build uses a temporary MDF validation frame or jumps directly to walnut.
- Whether the chromatic and pentatonic builds share one frame jig with two drilling templates, or use independent jigs.
- Whether to run a parallel brass / phosphor-bronze pilot (one C5 bar in each metal) to validate the K library beyond aluminum.

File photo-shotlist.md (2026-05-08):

# Photo Shotlist

This shotlist follows the repo-level photo pipeline expectations from `instrument-maker/docs/photo-pipeline.md`: capture real process images first, use generated or supplier images only as labeled placeholders, and keep build-log image names stable enough for `site/index.html`.

## Intake And Materials

- `images/01-workbook-table.png`: screenshot of `glockenspiel-design-table.xlsx` showing the Glockenspiel sheet with K library and bar calculator.
- `images/02-aluminum-stock.jpg`: rough 6061-T6 flat bar with ruler and mill-cert label visible.
- `images/03-walnut-frame-stock.jpg`: walnut boards selected for the frame, with a grain-direction arrow.
- `images/04-hardware-options.jpg`: three durometer rubber grommets, paracord, 1/8 in stainless rod laid out for the durometer pilot.
- `images/05-mallets-options.jpg`: hard rubber, brass, and lexan/Delrin mallet pairs side-by-side.

## Bar Fabrication

- `images/10-bar-marking.jpg`: stop-block sled with C5 blank marked for length and node positions.
- `images/11-bar-cutting.jpg`: chop saw or band saw cutting C5 to length.
- `images/12-bar-deburr.jpg`: deburred bar end close-up.
- `images/13-node-drilling.jpg`: drill press with V-block jig and hardwood backer drilling node hole.
- `images/14-node-hole-detail.jpg`: clean 3/16 in hole through the bar.

## Tuning And Mounting

- `images/20-flat-bar-strike.jpg`: pilot bar on foam supports at nodes with tuner reading Hz.
- `images/21-trim-to-pitch.jpg`: belt sander or fine file removing material symmetrically from both ends.
- `images/22-mounting-rig.jpg`: three-block prototype rig with three durometer grommets ready for sustain comparison.
- `images/23-cord-thread.jpg`: paracord threaded through node holes of one row.

## Frame And Final Assembly

- `images/30-frame-routing.jpg`: walnut rail on CNC router with grommet pockets cut.
- `images/31-frame-layout-test.jpg`: full-size paper template on bench for ergonomic check.
- `images/32-mounted-row.jpg`: full natural row mounted in walnut rail.
- `images/33-finished-front.jpg`: full instrument front view.
- `images/34-finished-side.jpg`: side view showing accidental row offset.
- `images/35-detail-grommet.jpg`: close-up of one bar in its grommet, showing isolation from frame.

## Validation

- `images/40-pilot-c5-tuning.jpg`: C5 framed and measured.
- `images/41-pilot-a5-tuning.jpg`: A5 framed and measured.
- `images/42-pilot-c7-tuning.jpg`: C7 framed and measured.
- `images/43-validation-log.jpg`: tuner, mic, and `validation.csv` workflow on bench.
- `images/44-buzz-test.jpg`: buzz check at three dynamics on the assembled instrument.

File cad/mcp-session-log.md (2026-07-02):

<!-- SPDX-License-Identifier: CC-BY-4.0 -->
# MCP / External-Tool Session Log

V5 provenance record for artifacts generated or modified by external tools.
Required before claiming any artifact came from OpenSCAD, Blender,
Illustrator, Photoshop, Fusion, SketchUp, or similar tooling.

This file did not exist prior to the 2026-07-01 V5 refresh, even though
fabrication-authority artifacts (`glockenspiel-design-table.xlsx`,
`family-spec.csv`, `cad/glockenspiel-master.scad`,
`cad/SolidWorks-MasterLayout-Plan.md`) already existed in the repo from
earlier rounds. This log backfills provenance for those pre-existing
artifacts and records the 2026-07-01 refresh pass.

| session_id | tool | input_authority | outputs | role | authority_result | review_status | notes |
|---|---|---|---|---|---|---|---|
| pre-2026-07-01-backfill | unknown (pre-V5-refresh round) | design.md governing model (free-free beam, `f ~= K*t/L^2`) | glockenspiel-design-table.xlsx, family-spec.csv, cad/glockenspiel-master.scad, cad/SolidWorks-MasterLayout-Plan.md | cad_authoring | pending_measurement | self_checked | Backfilled provenance row for artifacts authored before this log existed. Bar schedule and OpenSCAD starter reviewed against design.md; no bar has been cut or measured. |
| fable-v5-refresh-2026-07-01 | claude-code (Fable 5) + OpenSCAD CLI | glockenspiel-design-table.xlsx, family-spec.csv, design.md | cad/glockenspiel-master.scad | cad_authoring | pending_measurement | self_checked | Kept existing parametric master unchanged (no rewrite per V5 idiophones addendum — existing `cad/*-master.scad` satisfies the parametric CAD source requirement). OpenSCAD render check: pass (openscad -o STL, exit 0). |
| fable-v5-refresh-2026-07-01 | claude-code (Fable 5) | glockenspiel-design-table.xlsx | glockenspiel-design-table.xlsx, family-spec.csv, bom.csv, sourcing.csv, cut-list.csv, validation.csv | packet_refresh | fabrication | self_checked | V5 refresh pass: added this provenance log; reviewed tabular packet data against design-table baseline; no dimension changes made. Row added to satisfy V5 fabrication-artifact logging requirement. |
| fable-v5-refresh-2026-07-01 | claude-code (Fable 5) | design.md | wolfram/glockenspiel-wolfram-model.wl, glockenspiel-starter.wl | analysis_source | derived_preview | unreviewed | Pre-existing Wolfram source verified present and registered; not executed; source-only evidence at L2. |

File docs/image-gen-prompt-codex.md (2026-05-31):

# Image-Gen Prompts

Concept image only; not fabrication authority. Do not include cut-ready dimensions, bar lengths, node-hole positions, frame CNC geometry, tuning tables, or toolpaths.

## Hero Prompt

Photorealistic 3/4 product photograph of a finished 25-bar chromatic glockenspiel: bright 6061-style aluminum flat bars arranged C5-C7 in a piano-keyboard layout, naturals in the front row and raised sharps behind, each bar suspended by cord through node holes over rubber grommets on a CNC-routed black walnut frame, stainless support rods tucked neatly along the rows, two pairs of mallets beside the instrument, satin walnut and brushed aluminum textures, clean studio background, soft directional lighting, ~50mm lens, high detail.

## In-Context Prompt

Photorealistic workshop test scene of the glockenspiel on a bench, natural light over the walnut frame, a player striking a pilot bar with a hard rubber mallet while C5, A5, and C7 pilot bars and a small tuner sit nearby, paracord and grommet mounting visible, spare mallets and deburring tools blurred in the background, careful prototype-validation mood, realistic hands, shallow depth of field, concept visualization only.

## Detail Prompt

Photorealistic macro close-up of the signature free-free bar mounting: a brushed aluminum bar with clean deburred node holes, low-stretch cord passing through, rubber grommets isolating the bar from the black walnut frame, stainless restraint rod visible below but not touching the bar, soft raking light across aluminum grain and walnut pores, high detail, no measurement marks.

## Negative / Avoid

No text, logos, watermarks, toy rainbow bars, xylophone wooden bars, resonator tubes, dimension callouts, unreadable fake note labels, impossible cord routing, extra fingers, or metal-on-metal contact at the supports.

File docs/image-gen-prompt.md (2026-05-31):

# Image-Gen Prompts

Concept image only; not fabrication authority. Do not include cut-ready dimensions, hole locations, or toolpaths.

## Hero Prompt

A finished concert glockenspiel photographed as a real physical object on a clean neutral light-gray studio sweep, 3/4 product-photography angle, soft directional studio key light with a gentle fill, ~50mm lens, photorealistic, high detail. The instrument is a two-row piano-keyboard layout built on a warm CNC-routed black-walnut frame with a satin oil finish and visible straight grain: a front row of natural bars and a slightly raised back row of accidental bars, like the white and black keys of a piano. The sound bars are bright, mill-finished 6061-T6 aluminum flat bars, one inch wide and a quarter inch thick, with a subtle metallic sheen and clean deburred ends — graduating smoothly in length from the longest low bar at the left to the shortest high bar at the right, giving a clear visual tuning gradient. Each flat bar is plain and un-arched (no undercut, no resonator tubes beneath), suspended by paracord threaded through small holes near each end and resting on small rubber grommets seated in the walnut rails, so the metal never touches the wood; a thin stainless-steel support rod runs the length of each row as a travel restraint. A pair of mallets with hard-rubber and brass heads rests to one side for scale. Realistic tabletop scale cues, no text, no labels.

## In-Context Prompt

The same walnut-and-aluminum glockenspiel staged on a maker's workbench in a bright woodworking shop, lit by soft natural window light from the side, shallow depth of field with the longest low bars in crisp focus and the shop fading to a warm blur behind. A hand holds one mallet just above the natural row mid-strike, the bright aluminum bars catching the light against the dark walnut frame. Environmental storytelling: a chromatic tuner and a coil of paracord rest on the bench nearby, walnut offcuts and a few loose rubber grommets scattered to one side. Concept visualization only, photorealistic, warm and inviting, no text.

## Detail Prompt

Macro close-up of a single bright aluminum bar suspended at one of its end holes, raking low-angle light skimming across the mill-finished metal to reveal fine brushed texture and the clean chamfered edge. The frame shows: the small drilled hole through the flat aluminum bar, the paracord passing through it, the soft rubber grommet cradling the bar, and the dark walnut frame pocket below with the thin stainless support rod alongside — clearly showing how the bar floats free of the wood for sustain. High detail, shallow depth of field, no measurements, no callout lines.

## Negative / Avoid

No text, logos, watermarks, or fake maker marks; no dimension callouts or measurement lines; no arched/undercut bars or resonator tubes under the bars; no impossible mounting; anatomically plausible hands if a player is shown.

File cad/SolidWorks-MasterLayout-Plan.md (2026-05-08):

# SolidWorks MasterLayout Plan — Glockenspiel

## Goal

Capture the build-table-and-equation contract for a future native SolidWorks model of the C5-C7 chromatic glockenspiel. No native SW files are committed yet; this document plus `cad/sw-global-variables.csv` and `cad/design-table-inputs.csv` are the contract Tony uses to build the SW model.

## Pillars

Per `references/solidworks-integration.md`, the SW model rests on three pillars:

1. **Global equations** — driven from `cad/sw-global-variables.csv`. Variables that are constant across all bars (K constant, thickness, node ratios, hole diameter) live as global equations.
2. **Design table** — driven from `cad/design-table-inputs.csv`. One row per configuration (one configuration per chromatic note), with member_id, length, width, node positions, and target Hz.
3. **Master sketch** — `Master_Bar` part with a top-down sketch driven by the design-table dimensions, plus a `Frame_MasterLayout` sketch defining rail centerlines, bar spacing, and player-side datum.

## Parts

| Part | Purpose | Driven by |
| --- | --- | --- |
| `Master_Bar.SLDPRT` | One configuration per chromatic note (25 configs); generates per-bar STEP/SVG via design-table iteration. | `design-table-inputs.csv` |
| `Master_Frame_Rail.SLDPRT` | Front and back rails as configurations; differs in depth and grommet-pocket count. | Global variables + bar count parameter |
| `Master_Frame_Endcap.SLDPRT` | End cap with stainless-rod hole and rail joinery. | Global variables |
| `Glockenspiel_Assembly.SLDASM` | Top-level assembly referencing 25 bars + 2 rails + 2 end caps + cord/grommet/rod hardware. | Master parts and design table |

## Mate / Reference Discipline

- Every bar configuration is mated to its node positions on the front or back rail's centerline sketch.
- Naturals (15 configs) → front rail; sharps/flats (10 configs) → back rail offset 0.5 in.
- Cord, grommets, and stainless rod are simplified geometry (single `cord_path` sketch) — not modeled per-bar to keep the assembly light.

## Equations

```text
"D@thickness"@Master_Bar = 0.25
"D@width"@Master_Bar = 1.0
"D@K_constant"@Master_Bar = 204431
"D@bar_spacing"@Frame_MasterLayout = 1.25
"D@accidental_offset"@Frame_MasterLayout = 0.5
```

The bar `length_in` and `node_1_in`/`node_2_in` are NOT global equations; they are design-table-driven per configuration.

## Macro Hooks

- `Extract_Dimensions.swp` (per `references/solidworks-integration.md`) can dump dimension values to `cad/sw-extracted-dimensions.csv` for round-trip validation against `family-spec.csv` via `scripts/ingest_dimension_csv.py`.
- `scripts/generate_sw_design_table.py` can emit a fresh `cad/sw-design-table.xlsx` from `family-spec.csv` whenever the K constant or scale changes.

## Open Questions

- Whether to model the cord and grommets as simplified geometry or skip them entirely in the SW assembly.
- Whether to commit STEP exports from the design-table iteration (one STEP per configuration) or produce them on demand.
- Whether the alternate-metal variants (Brass, Steel, SS, Phosphor Bronze) get distinct top-level assemblies or share the chromatic master with a different K global value.

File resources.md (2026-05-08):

# Resources & Provenance

## Workbook Lineage

- Source workbook: `glockenspiel-design-table.xlsx` (committed to this repo).
  - Single sheet `Glockenspiel`, range `A1:L174`.
  - 94 formula cells, 16 blue input cells.
  - Five-metal K library (rows 14-20): 6061-T6 Aluminum, Brass C260, Steel 1018, 304 Stainless, Phosphor Bronze.
  - Two scale blocks: 25-bar chromatic C5-C7 (rows 23-49) and 10-bar C-major pentatonic (rows 92-110).
  - Wolfram notebook spec (rows 129-159) and Wolfram exploration ideas (rows 161-174).

## Instrument Family Context

- Cultural origin: glockenspiel is a modern Western orchestral and military-band idiophone. The German name means "bells play"; the form derives from sets of small bells used in 18th-19th century military bands and was standardized as a bar instrument by Berlioz-era orchestras (1819+).
- Synonyms: orchestra bells, bell lyre (marching), orchestral bells (some scores).
- Distinguished from xylophone (wood bars, no arch) and marimba (wood bars, arch + resonators) by being metal bars without arch or resonator.

## Reference Repos

- `tonykoop/marimba` — closest sibling: free-free beam idiophone, same node math, same imperial K formulation, same validation discipline. The glockenspiel diverges by using metal instead of wood, omitting arch and resonator, and replacing wood K-table with metal K-table.
- `tonykoop/tongue-drum` — README convention and documentation standard reference.
- `tonykoop/instrument-maker` — catalog this repo is part of.

## Skill / Documentation Lineage

- Skill: `instrument-maker-v4` v4.3 root-mode.
- Reference docs consulted: `references/acoustic-models.md` (Free-Free Beams + empirical-correction guard rules), `references/new-instruments-v4.md` (Glockenspiel section), `references/repo-relationships.yaml` (cantilever-idiophone family).

## Empirical-Correction Guard Rules (Honest Inventory)

The following corrections do NOT apply to this packet:

- **NAF K2 corrections** (open-pipe flute bore-diameter table) — open-pipe flute model only.
- **Vessel Helmholtz corrections** — applies to ocarina/udu/gemshorn, not free-free beams.
- **Cantilever wood K-table** — applies to fixed-free wood beams (tongue drums), not free-free metal bars.
- **Marimba arch undercut math** — out of scope for metal bars (no arch).
- **Quarter-wave resonator math** — out of scope for this packet (no resonators).

The only correction loop that DOES apply: per-lot K calibration from pilot measurements, recorded in `validation.csv` and propagated to `family-spec.csv` and the workbook B21 cell.

## Public-Safety Inventory

- No private repo links.
- No local absolute paths in user-facing artifacts.
- No supplier prices frozen as facts (`current_price_status = not verified` throughout).
- No unlicensed images (no images currently committed; placeholders documented in `photo-shotlist.md`).
- No cultural-appropriation flags for the instrument category (modern Western orchestral instrument).
- License: CC BY 4.0 per existing `LICENSE` file.

## Open Provenance Questions

- Whether the K constants in the workbook material library should be regenerated from a single E/rho source (e.g., MatWeb) for traceability vs the current literature-pulled values.
- Whether to commit a small `data/k-library-source.csv` documenting where each K came from.
- Whether to add a "what would change for an outdoor sound-garden glockenspiel" appendix once the indoor build is validated.

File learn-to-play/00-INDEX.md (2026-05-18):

# Glockenspiel — Starter Songbook

The glockenspiel is a soprano metallophone with steel bars struck with hard mallets.
Its bright, bell-like tone projects easily and decays quickly — ideal for clear, stepwise melodies.

## Instrument range
- Beginner range used here: **C5–C7** (c' to c'' in ABC notation)
- Full instrument range: typically C5–C8 depending on model

## ABC notation note
All tunes are written at concert (sounding) pitch. Notes in the `c'` octave sound at C5.
A glockenspiel pitched "two octaves above written" in orchestral parts would require
transposing notation — this songbook writes what you **actually hear**.

## Difficulty key
- ★☆☆ — Beginner: conjunct motion, one octave range
- ★★☆ — Intermediate: skips of a third or fifth, two octaves
- ★★★ — Advanced: leaps, ornaments, fast passage work

## Tunes in this songbook
1. `tunes/twinkle/` ★☆☆ — Twinkle Twinkle Little Star (C major)
2. `tunes/ode-to-joy/` ★☆☆ — Ode to Joy theme (D major)
3. `tunes/frere-jacques/` ★★☆ — Frère Jacques / Brother John (C major)
4. `tunes/amazing-grace/` ★★☆ — Amazing Grace (G major, 3/4)
5. `tunes/scarborough-fair/` ★★★ — Scarborough Fair (D dorian)

## Mallet guidance
- Use hard rubber or plastic mallets for bright tone.
- Strike each bar at its center, not the node holes at the ends.
- Let the mallet rebound — don't press down after striking.

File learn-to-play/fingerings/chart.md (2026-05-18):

# Glockenspiel Bar Layout Reference

Standard C-major layout (chromatic bars in upper row, diatonic in lower row):

```
   ┌───┐ ┌───┐   ┌───┐ ┌───┐ ┌───┐
   │C# │ │D# │   │F# │ │G# │ │A# │   ← Upper row (sharps/flats)
   └───┘ └───┘   └───┘ └───┘ └───┘
 ┌───┐ ┌───┐ ┌───┐ ┌───┐ ┌───┐ ┌───┐ ┌───┐
 │ C │ │ D │ │ E │ │ F │ │ G │ │ A │ │ B │   ← Lower row (naturals)
 └───┘ └───┘ └───┘ └───┘ └───┘ └───┘ └───┘
   C5   D5   E5   F5   G5   A5   B5

Tunes in this songbook use:  C5  D5  E5  F5  G5  A5  (+ C#5, F#5 for some tunes)
```

## Mallet technique
- Strike the center of each bar for maximum resonance.
- Use a slight wrist flick — don't press down after impact.
- Alternate mallets: R for odd beats, L for even beats (adjust as needed).
- Dampen with a finger on the bar edge only when a short note is needed.

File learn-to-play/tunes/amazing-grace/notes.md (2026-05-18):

# Notes: Amazing Grace

**Provenance:** Lyrics by John Newton, published in "Olney Hymns" (1779), PD.
Tune "New Britain" is a traditional American folk melody, origin unknown, PD.
This arrangement is freshly written from the lead-sheet melody — no modern arranger rights.

**Range check:** G5–D6. Upper note (D6) requires confident mallet control.

**Practice tips:**
1. The pickup note (g') starts just before bar 1. Think of it as the "upbeat."
2. The signature dotted rhythm (g'3/2 b'/) = dotted quarter + eighth. Practice: long-short, long-short.
3. At ♩= 80, the 3/4 feel is slow and stately — don't rush.

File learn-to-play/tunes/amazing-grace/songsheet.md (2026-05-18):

# Amazing Grace — Songsheet

**Key:** G major  **Tempo:** ♩= 80  **Meter:** 3/4  **Difficulty:** ★★☆
**Range:** D5–D6  **Source:** John Newton, "Olney Hymns" 1779; tune trad. PD

## Music
```
X:4 T:Amazing Grace M:3/4 L:1/4 Q:1/4=80 K:G
g'2 | g'3/2 b'/ g' e' | e'2 d' | d'3/2 g'/ b'2 | g'3 |
b'3/2 d''/ b' g' | a'2 b' | g'3/2 e'/ g' d' | g'3 |
(verse 2 same as verse 1)
```

## Notes
- 3/4 waltz feel — count "1-2-3" steadily, placing the pickup note just before "1".
- The melody stays in the G5–D6 range — very comfortable on glockenspiel.
- The grace note pairs (3/2 + /) can be simplified to plain quarter notes for beginners.

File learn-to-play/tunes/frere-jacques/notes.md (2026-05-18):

# Notes: Frère Jacques

**Provenance:** Traditional French children's song / round, 17th century. Public domain worldwide.
Sometimes attributed to Guillaume-Gabriel Nivers or Jean-Philippe Rameau, but origin is uncertain.

**Range check:** G5–A5. Comfortably within glockenspiel range.

**Practice tips:**
1. The first phrase (C D E C) is the seed of the whole piece — all other bars derive from it.
2. For the eighth-note run, practice: G A G F E C slowly (♩= 60) until smooth.
3. As a round, the glockenspiel's sustain helps create the overlapping harmonic texture.

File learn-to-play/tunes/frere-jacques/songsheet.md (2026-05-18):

# Frère Jacques — Songsheet

**Key:** C major  **Tempo:** ♩= 108  **Meter:** 4/4  **Difficulty:** ★★☆
**Range:** G5–A5  **Source:** Traditional French (17th c.), public domain

## Music
```
X:3 T:Frère Jacques M:4/4 L:1/4 Q:1/4=108 K:C
|: c' d' e' c' | c' d' e' c' | e' f' g'2 | e' f' g'2 :|
|: g'/ a'/ g'/ f'/ e' c' | g'/ a'/ g'/ f'/ e' c' | c' G' c'2 | c' G' c'2 :|
```

## Round form
This is a 4-voice round. After player 1 completes bar 1, player 2 starts from the beginning.
On glockenspiel, play alone or in a round with other instruments.

## Notes
- Bars 1–2 repeat exactly — once you learn bar 1, bar 2 is free.
- The eighth-note run (g'/ a'/ g'/ f'/) requires quick mallet work. Practice slowly.
- The drop to G' (G5) at the end gives the tune its rounding resolution.

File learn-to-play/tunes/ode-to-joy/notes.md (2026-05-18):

# Notes: Ode to Joy

**Provenance:** 4th movement theme from Beethoven's Symphony No. 9 in D minor, Op. 125 (1824).
Beethoven died 1827; work entered public domain long ago. This is the unaccompanied melody only.

**Range check (glockenspiel):** C#5–G5. Fits comfortably on any glockenspiel.

**Practice tips:**
1. The melody repeats almost exactly — learn bars 1–4 and you know 75% of the piece.
2. The "bridge" section (bars 9–12) has the most movement — practice it slowly first.
3. The dotted quarter + eighth rhythm (e'3 d') feels natural if you count "1-and-2-AND-3".

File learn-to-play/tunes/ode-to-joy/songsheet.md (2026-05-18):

# Ode to Joy — Songsheet

**Key:** D major  **Tempo:** ♩= 96  **Meter:** 4/4  **Difficulty:** ★☆☆
**Range:** C#5–G5  **Source:** Beethoven, Symphony No. 9 (1824), public domain

## Music
```
X:2 T:Ode to Joy M:4/4 L:1/8 Q:1/4=96 K:D
|: e'2 e'2 f'2 g'2 | g'2 f'2 e'2 d'2 | c'2 c'2 d'2 e'2 | e'3 d' d'4 :|
|: e'2 e'2 f'2 g'2 | g'2 f'2 e'2 d'2 | c'2 c'2 d'2 e'2 | d'3 c' c'4 :|
|: d'2 d'2 e'2 c'2 | d'2 e'2 f'2 e'2 | c'2 d'2 e'2 f'2 | e'2 d'2 c'2 g'2 :|
|: e'2 e'2 f'2 g'2 | g'2 f'2 e'2 d'2 | c'2 c'2 d'2 e'2 | d'3 c' c'4 :|
```
*In K:D, f=F# and c=C# automatically.*

## Notes
- This is the melody exactly as Beethoven wrote it in D major.
- The glockenspiel's bright timbre pairs naturally with this triumphant theme.
- Practice the first 4-bar phrase alone until it's confident, then add the rest.

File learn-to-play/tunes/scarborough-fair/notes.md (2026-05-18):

# Notes: Scarborough Fair

**Provenance:** Traditional English ballad, origin unclear but documented from at least the 17th century.
Multiple versions in Cecil Sharp's English Folk Songs (1907, PD). This arrangement is freshly written
from the traditional lead-sheet melody — no Simon & Garfunkel arrangement rights (their arrangement
from 1966 is copyrighted, but the underlying traditional melody is PD).

**Range check:** C5–D6. The D6 is the highest note — it occurs early in each verse.

**Practice tips:**
1. The D dorian mode means no key signature — play all notes natural.
2. The octave leap (a' to d'') at the start is characteristic — don't rush it.
3. At ♩= 76, count a gentle 1-2-3 waltz pulse; never speed up.

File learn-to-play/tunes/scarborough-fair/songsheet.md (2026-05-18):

# Scarborough Fair — Songsheet

**Key:** D dorian (D natural minor with raised 6th)  **Tempo:** ♩= 76
**Meter:** 3/4  **Difficulty:** ★★★  **Range:** C5–D6
**Source:** Traditional English ballad, public domain

## Music
```
X:5 T:Scarborough Fair M:3/4 L:1/4 Q:1/4=76 K:Dmin
a' | d'' a' f' | d'3/2 e'/ f' | e'2 c' | d'3 |
f' g' a' | c''2 a' | g'2 f' | a'3 |
(repeat for each verse)
```

## Modal note
Scarborough Fair is in **D dorian** — similar to D natural minor, but with B-natural
instead of B-flat. This gives it the distinctively "ancient" folk sound.
On glockenspiel, play all B notes natural (not flat).

## Notes
- Slower than the other tunes — the modal color needs space to breathe.
- The pickup note (a') begins just before bar 1, leading into the leap up to d''.
- Practice the leap d'–d'' (an octave) carefully — it's the signature gesture.

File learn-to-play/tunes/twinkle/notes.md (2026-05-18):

# Notes: Twinkle Twinkle Little Star

**Provenance:** Melody is the traditional French tune "Ah vous dirai-je, maman" (18th century, PD).
The "Twinkle" lyrics were written by Jane Taylor, published 1806, PD in the US.
Mozart's Variations K.265/300e (1781) popularized the tune — also PD.

**Range check (glockenspiel):** C5–A5. Well within any glockenspiel's range.

**Practice tips:**
1. Master the first 4 bars alone — that's the full "Twinkle" verse.
2. The middle section (bars 5–8) is the "bridge" — same notes, different order.
3. Bars 9–12 repeat bars 1–4. The whole song is just two ideas.

**Mallet technique:** Use alternating strokes (R-L-R-L). Don't play two consecutive
notes with the same hand unless the notes are far apart.

**Audio rendering:** WAV skipped — install fluidsynth and rerun `scripts/render_audio.py`.
**LilyPond:** See `lilypond.ly`. Render with `lilypond lilypond.ly`.

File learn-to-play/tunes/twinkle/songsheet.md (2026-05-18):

# Twinkle Twinkle Little Star — Songsheet

**Key:** C major  **Tempo:** ♩= 100  **Meter:** 4/4  **Difficulty:** ★☆☆
**Range:** C5–A5  **Source:** Traditional French melody, public domain

## Music (ABC notation — paste into abcjs.net to hear it)
```
X:1
T:Twinkle Twinkle Little Star
M:4/4 L:1/8 Q:1/4=100 K:C
|: c'2 c'2 g'2 g'2 | a'2 a'2 g'4 | f'2 f'2 e'2 e'2 | d'2 d'2 c'4 :|
|: g'2 g'2 f'2 f'2 | e'2 e'2 d'4 | g'2 g'2 f'2 f'2 | e'2 e'2 d'4 :|
```

## Bar-by-bar breakdown
| Bar | Notes | Lyric |
|-----|---|---|
| 1 | C C G G | "Twin-kle twin-kle" |
| 2 | A A G (half) | "lit-tle star" |
| 3 | F F E E | "how I won-der" |
| 4 | D D C (half) | "what you are" |
| 5–6 | G G F F / E E D (half) | "Up a-bove the / world so high" |
| 7–8 | G G F F / E E D (half) | "Like a dia-mond / in the sky" |
| 9–12 | (repeat bars 1–4) | "Twin-kle twin-kle..." |

## Notes
- All notes are in the C5–A5 range — no wide leaps.
- This melody teaches the relationship between C, D, E, F, G, A (no B needed).
- Practice at ♩= 80 first; increase to 100 once fluent.

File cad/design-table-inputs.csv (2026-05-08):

Configuration | member_id | note | midi | freq_hz | length_in | width_in | thickness_in | node_1_in | node_2_in | node_hole_dia_in | material | k_constant
GLK-C5 | GLK-C5 | C5 | 72 | 523.251 | 9.883 | 1.000 | 0.250 | 2.216 | 7.667 | 0.1875 | 6061-T6 Aluminum | 204431
GLK-Csharp5 | GLK-Csharp5 | C#5 | 73 | 554.365 | 9.602 | 1.000 | 0.250 | 2.153 | 7.449 | 0.1875 | 6061-T6 Aluminum | 204431
GLK-D5 | GLK-D5 | D5 | 74 | 587.330 | 9.328 | 1.000 | 0.250 | 2.091 | 7.237 | 0.1875 | 6061-T6 Aluminum | 204431
GLK-Dsharp5 | GLK-Dsharp5 | D#5 | 75 | 622.254 | 9.063 | 1.000 | 0.250 | 2.032 | 7.031 | 0.1875 | 6061-T6 Aluminum | 204431
GLK-E5 | GLK-E5 | E5 | 76 | 659.255 | 8.805 | 1.000 | 0.250 | 1.974 | 6.831 | 0.1875 | 6061-T6 Aluminum | 204431
GLK-F5 | GLK-F5 | F5 | 77 | 698.456 | 8.554 | 1.000 | 0.250 | 1.918 | 6.636 | 0.1875 | 6061-T6 Aluminum | 204431
GLK-Fsharp5 | GLK-Fsharp5 | F#5 | 78 | 739.989 | 8.311 | 1.000 | 0.250 | 1.863 | 6.447 | 0.1875 | 6061-T6 Aluminum | 204431
GLK-G5 | GLK-G5 | G5 | 79 | 783.991 | 8.074 | 1.000 | 0.250 | 1.810 | 6.264 | 0.1875 | 6061-T6 Aluminum | 204431
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

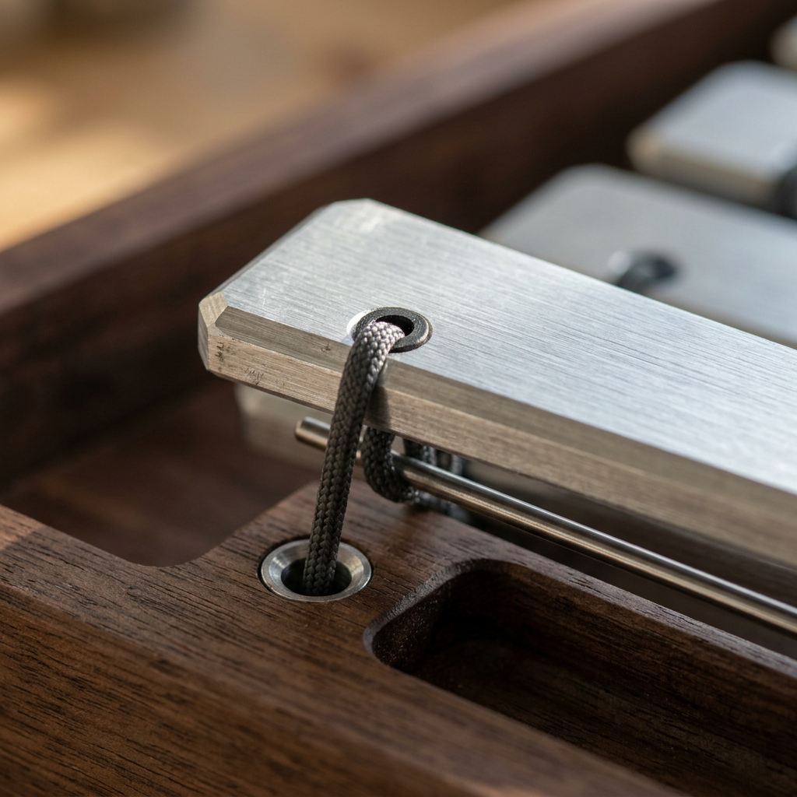
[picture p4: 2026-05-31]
images/macro/bar-grommet-mount.png

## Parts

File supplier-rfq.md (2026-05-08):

# Supplier RFQ - Glockenspiel C5-C7 Build

## Scope

Request quotes for one 25-bar C5-C7 chromatic glockenspiel prototype build, with optional materials for a 10-bar pentatonic art-fair variant. Prices, stock, and lead times are intentionally not assumed in this repo; verify current facts before purchasing.

## Bar Stock - Aluminum (Primary)

Please quote 6061-T6 aluminum flat bar suitable for tuned percussion bars.

Required:

- Dimensions: `0.250 in x 1.000 in` flat bar.
- Length: minimum 18 ft total per build (chromatic + pentatonic + pilot scrap).
- Temper: `T6` strongly preferred for consistent K constant.
- Surface: free of deep scratches in playing area.

Please return:

- Mill / mill lot identifier (so the K-calibration record stays traceable across rebuilds).
- Available temper variants and their K-constant impact, if known.
- Cutting service availability (longest single bar needed is 11 in cut from 12-ft stock).
- Mill cert availability for E and rho (used to recompute K_metal independently).

## Bar Stock - Alternate Metals (Optional)

Please quote alternate flat-bar options at the same `0.250 in x 1.000 in` cross-section, in lengths sufficient for one 25-bar build per metal:

| Metal | Spec | Use Case |
| --- | --- | --- |
| Brass C260 | Yellow brass C260 flat bar | Premium warm tone variant |
| Steel 1018 | Cold-rolled 1018 flat bar | Loud / sharp tone variant |
| 304 Stainless | 304 stainless steel flat bar | Outdoor / weather-resistant variant |
| Phosphor Bronze | C510 or C544 phosphor bronze flat bar | Best-sustain premium variant |

Each metal alters the K constant materially; the user will regenerate `family-spec.csv` from the workbook before cutting.

## Frame Hardwood

Please quote Black Walnut frame stock suitable for CNC-routed glockenspiel frames.

Required:

- Black Walnut, 4/4 dressed to `0.750 in` thick.
- Clear straight-grain stock; no checks in finished area.
- Minimum dimensions: enough for two rails (about `36 in x 3 in` finished) plus end caps and an optional accidental row.
- Quantity: enough for one frame plus 1 spare rail.

Acceptable substitutes (functionally equivalent for tuning purposes; aesthetics differ):

- Hard maple
- Cherry

## Hardware

Please quote:

- 550 paracord or low-stretch braided nylon cord, 4 mm diameter.
- Rubber grommets, `0.1875 in` ID, available in Shore 30A / 50A / 70A durometers (sample of three durometers required for pilot).
- 1/8 in 304 stainless steel rod in 36 in lengths (qty 2 minimum per build).
- Self-adhesive 1/2 in rubber feet (qty 4 per frame).
- Frame fastener kit: wood screws, threaded inserts, washers; prefer removable.

## Mallets

Please quote at least two pairs from the following:

- Hard rubber head (default), 1.0 in head dia, 8-10 in handle.
- Brass head (orchestral upgrade), 0.75 in head dia, 8-10 in handle.
- Lexan or Delrin head (alternate), 0.75-1.0 in head dia, 8-10 in handle.

## CNC and Bar Tooling

Please quote:

- 1/4 in carbide downcut spiral router bit, hardwood-capable.
- 1/8 in carbide upcut spiral router bit, hardwood-capable.
- 1/8 in V-bit (60 deg) for optional inlay.
- 3/16 in HSS or carbide drill bit for aluminum (brad-point or jobber).
- 80T or 100T carbide chop-saw blade for non-ferrous metals.

Include shank diameter, cut length, recommended feed/speed range, and replacement availability.

## Measurement

Please quote:

- Chromatic tuner or strobe with reliable readout up to 2.5 kHz (must read C7 = 2093 Hz). Peterson StroboClip HD or equivalent.

## Response Format

Please return:

```text
item
supplier part number
material/spec
actual dimensions / temper / lot id
quantity available
unit price
lead time
shipping estimate
notes/substitution risks
```

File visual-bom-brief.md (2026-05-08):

# Visual BOM Brief

## Goal

Create a visual BOM plate that lets another maker understand the glockenspiel build at a glance: bar set, walnut frame, mounting hardware, mallets, CNC and bar tooling, and measurement gear.

## Required Views

1. Hero view of the assembled C5-C7 chromatic glockenspiel on a finished walnut frame, mallets to one side.
2. Exploded view showing bars above the front and back walnut rails, with cord, grommets, and stainless support rods called out.
3. Detail inset for one bar: 3/16 in node holes, top/bottom faces, dimensional callouts (L, w, t).
4. Detail inset for the mounting cross-section: bar, grommet, cord, walnut pocket, stainless support rod.
5. Detail inset for one mallet pair (hard rubber default + brass upgrade).
6. Material swatches: 6061-T6 aluminum bar stock, Black Walnut frame stock, paracord, rubber grommets, stainless support rod, MDF/plywood jig stock.

## BOM Rows To Show

| Item | Visual Needed | Source |
| --- | --- | --- |
| Tuned aluminum bars | Actual shop photo once cut; concept placeholder acceptable before build | `family-spec.csv` |
| Alternate metals (Brass, Steel, SS, Phosphor Bronze) | Supplier image; small swatch row | `sourcing.csv` |
| Walnut frame stock | CAD render or shop photo | `cad/` |
| Paracord (mounting cord) | Supplier image or shop photo | `bom.csv` |
| Rubber grommets (3 durometers) | Supplier image with durometer label | `bom.csv` |
| 1/8 in stainless support rod | Supplier image or shop photo | `bom.csv` |
| Hard rubber + brass mallets | Shop photo | `bom.csv` |
| CNC bits (1/4 downcut, 1/8 upcut, 1/8 V-bit) | Supplier image | `bom.csv` |
| 3/16 in drill bit for aluminum | Supplier image | `bom.csv` |
| Chromatic tuner | Supplier image or shop photo | `validation.csv` workflow |

## Labeling Rules

- Label generated images as concept placeholders.
- Do not use generated images for exact dimensions.
- Every dimension callout must match `family-spec.csv` or be marked `TBD`.
- Keep supplier prices out of the visual until current quotes are verified.
- The five-metal K-comparison is a useful side panel (E vs rho scatter sized by K) — see workbook §6 row 165.

## First Plate Layout

Top: title (Glockenspiel C5-C7), date, range (C5-C7 chromatic + C-pentatonic art-fair), primary material (6061-T6 aluminum).

Middle left: exploded assembly with numbered callouts.

Middle right: BOM table grouped by bar set, frame, hardware, mallets, tooling, measurement.

Side panel: metal K-constant scatter (E vs rho axes, points sized by K). Shows aluminum/steel cluster vs brass/phosphor-bronze cluster.

Bottom: assumptions (workbook K is first-pass; pilot K-calibration required; durometer pilot required) and missing purchase-verification items.

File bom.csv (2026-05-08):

item | subassembly | part_name | qty | unit | material_or_spec | make_buy | status | estimated_cost | notes
1 | Bar set | C5-C7 chromatic tuned bars | 25 | ea | 6061-T6 Aluminum 0.25 x 1.00 in flat bar | make | workbook-derived | $25-40 | Individual dimensions in family-spec.csv. Cut long by 0.25 in and trim to pitch.
2 | Bar set (alt) | Pentatonic art-fair tuned bars | 10 | ea | 6061-T6 Aluminum 0.25 x 1.00 in flat bar | make | workbook-derived | included | Same stock as chromatic. C major pentatonic block in family-spec.csv.
3 | Bar material (alt) | Brass C260 0.25 x 1.00 flat bar | as needed | ft | Brass C260 K=145325 | buy | alternate | $$$ | Premium tone variant. Regenerate family-spec.csv with K=145325 if used.
4 | Bar material (alt) | Steel 1018 0.25 x 1.00 flat bar | as needed | ft | Steel 1018 K=204267 | buy | alternate | $ | K nearly identical to aluminum but heavier and brighter; same predicted lengths.
5 | Bar material (alt) | 304 Stainless flat bar | as needed | ft | 304 SS K=198770 | buy | alternate | $$ | Outdoor / weather-resistant variant.
6 | Bar material (alt) | Phosphor Bronze flat bar | as needed | ft | Phosphor Bronze K=142593 | buy | alternate | $$$$ | Best sustain; highest cost.
7 | Frame | Black Walnut frame stock | ~6 | bf | 3/4 in thick clear straight-grain walnut | make | workbook-derived | $30-60 | CNC-routed front + back rails plus end caps. Hard maple acceptable substitute.
8 | Frame | Frame fastener kit | 1 | set | Wood screws, threaded inserts, washers | buy | TBD | $5-10 | Prefer removable fasteners for tuning access.
9 | Hardware | 550 Paracord (mounting cord) | ~12 | ft | Low-stretch braided nylon cord 4 mm | buy | TBD | $5-10 | Sized to pass through 3/16 in node holes without buzz.
10 | Hardware | Rubber grommets | ~50 | ea | 3/16 in ID rubber grommets in two-three durometer candidates | buy | TBD | $5-15 | Pilot Shore 30A / 50A / 70A on C5/A5/C7 before standardizing.
11 | Hardware | Stainless steel support rod | 2 | ea | 1/8 in 304 stainless steel rod cut to frame length | buy | TBD | $5-10 | Front and back row backup restraints; not load-bearing.
12 | Hardware | Self-adhesive rubber feet | 4 | ea | 1/2 in rubber feet | buy | TBD | $3-5 | Prevent frame sliding on table.
13 | Mallets | Hard rubber mallets | 1 | pair | Hard rubber head 1 in dia / 8-10 in handle | buy | TBD | $10-20 | Default striker; balanced bright/warm tone.
14 | Mallets | Brass mallets | 1 | pair | Brass head 0.75 in dia / 8-10 in handle | buy | TBD | $15-25 | Bright orchestral attack; ship as upgrade option.
15 | Mallets (alt) | Lexan / Delrin mallets | 1 | pair | Lexan or Delrin head | buy | TBD | $15-20 | Less metallic than brass; alternative for solo work.
16 | CNC tooling | 1/4 in downcut spiral router bit | 1 | ea | Hardwood-capable carbide downcut | buy | TBD | $15-25 | Walnut frame profile and grommet pockets.
17 | CNC tooling | 1/8 in upcut spiral router bit | 1 | ea | Hardwood-capable carbide upcut | buy | TBD | $15-25 | Small reliefs and inlay grooves.
18 | CNC tooling | 1/8 in V-bit (60 deg) | 1 | ea | V-carving bit for inlay/engraving | buy | TBD | $15-25 | Optional: Broinwood-style frame inlay.
19 | Bar tooling | 3/16 in HSS or carbide drill bit | 1 | ea | Brad-point or jobber-length bit | buy | TBD | $5-10 | Node-hole drilling.
20 | Bar tooling | Non-ferrous carbide chop-saw blade | 1 | ea | 80T or 100T carbide blade for aluminum | buy | TBD | $30-60 | Cut bars to length without burr-up.
21 | Finish | Tung oil or shellac for frame | 1 | can | Frame finish only; bars left raw or clear-coated separately | buy | TBD | $10-20 | Avoid heavy finishes that load the playing surface.
22 | Finish | Optional clear coat for bars | 1 | can | Thin spray lacquer if desired | buy | TBD | $5-15 | Test pitch shift on offcut before committing.
23 | Measurement | Chromatic tuner / strobe | 1 | ea | Peterson StroboClip HD or app capable of 2 kHz+ | buy/owned | TBD | $30-100 | Must reliably read C7 = 2093 Hz.
24 | Measurement | Microphone for sustain logging | 1 | ea | Dynamic or condenser mic; phone app acceptable for first build | buy/owned | TBD | $0-100 | Capture sustain to first 6 dB drop.
25 | Measurement | Calipers + scale + strike support foam | 1 | set | Digital calipers, kitchen scale, foam blocks | buy/owned | TBD | $0-30 | For K_eff calibration and node-support strike tests.

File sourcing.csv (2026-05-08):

item | stable_spec | supplier_candidates | current_price_status | lead_time_status | verification_needed | notes
6061-T6 Aluminum flat bar | 0.25 x 1.00 in flat bar; T6 temper preferred for consistent K; minimum 18 ft per build with pilot scrap | Online Metals; McMaster-Carr; Metal Supermarkets; local metal supplier | not verified | not verified | Verify temper and mill lot; request mill cert for K-calibration record | Buy enough for 25 chromatic + 10 pentatonic + at least 3 pilot/scrap bars from one mill lot.
Brass C260 flat bar (alt) | 0.25 x 1.00 in C260 yellow brass flat bar | Online Metals; McMaster-Carr; Metal Supermarkets | not verified | not verified | Verify alloy and temper | Premium tone alt; regenerate family-spec.csv with K=145325 before cutting.
Steel 1018 flat bar (alt) | 0.25 x 1.00 in 1018 cold-rolled steel flat bar | Online Metals; McMaster-Carr; local metal supplier | not verified | not verified | Verify cold-rolled vs hot-rolled | Loud and bright; same family-spec lengths as aluminum (K nearly identical).
304 Stainless flat bar (alt) | 0.25 x 1.00 in 304 SS flat bar | Online Metals; McMaster-Carr | not verified | not verified | Verify finish (#4 vs polished) | Outdoor variant; regenerate family-spec.csv with K=198770.
Phosphor Bronze flat bar (alt) | 0.25 x 1.00 in phosphor bronze flat bar | Online Metals; specialty metal supplier | not verified | not verified | Verify alloy (510 vs 544) | Premium tone; highest cost; regenerate family-spec.csv with K=142593.
Walnut frame lumber | Clear straight-grain Black Walnut 4/4 dressed to 3/4 in thick; sufficient for two rails (~36 in long) plus end caps and accidental row | Local hardwood dealer; Woodcraft; Rockler | not verified | not verified | Verify board flatness and absence of checks | Hard maple or cherry acceptable substitutes; frame wood does not affect bar tuning.
Paracord (mounting) | 550 paracord or low-stretch braided nylon cord; 4 mm diameter to fit through 3/16 in node holes | Outdoor / climbing supplier; Amazon; local hardware | not verified | not verified | Verify diameter and stretch under tension | Must not buzz against bar holes.
Rubber grommets | 3/16 in ID rubber grommets in Shore 30A / 50A / 70A durometers | McMaster-Carr; marimba parts supplier; Amazon | not verified | not verified | Verify durometer accuracy and sample three options | Two grommets per bar minimum; durometer is the dominant sustain control.
Stainless steel support rod | 1/8 in 304 stainless steel rod in 36 in lengths | McMaster-Carr; OnlineMetals; local hardware | not verified | not verified | Verify diameter +/- 0.005 in | Two rods per instrument (front + back row).
Self-adhesive rubber feet | 1/2 in rubber feet with 3M adhesive backing | McMaster-Carr; hardware store | not verified | not verified | Verify adhesion strength | Four per frame.
Hard rubber mallets | Pair of hard-rubber-headed mallets with 8-10 in wood handles | Music supplier; Amazon; Steve Weiss Music | not verified | not verified | Verify head durometer | Default striker for the assembled instrument.
Brass mallets | Pair of brass-headed mallets with 8-10 in wood handles | Music supplier; Steve Weiss Music | not verified | not verified | Verify head finish (polished vs natural) | Optional bright-attack upgrade.
Lexan / Delrin mallets | Pair of synthetic-headed mallets | Music supplier; specialty supplier | not verified | not verified | Verify head material | Optional alternative striker; less metallic than brass.
CNC router bits | 1/4 in downcut + 1/8 in upcut + 1/8 in V-bit (carbide) | Amana; Whiteside; Onsrud; local CNC supplier | not verified | not verified | Verify shank diameter for collet | Walnut frame profile and inlay.
Aluminum drill bit | 3/16 in HSS or carbide bit; brad-point or jobber-length | McMaster-Carr; local hardware | not verified | not verified | Verify bit type | Node-hole drilling.
Non-ferrous saw blade | 80T or 100T carbide blade for aluminum chop saw | Local tooling supplier; Amazon | not verified | not verified | Verify arbor size | Avoid burr-up on bar ends.
Frame finish | Tung oil or shellac for walnut frame | Wood finishing supplier; hardware store | not verified | not verified | Verify finish compatibility with walnut | Avoid heavy lacquer on the playing surface.
Chromatic tuner | Strobe or chromatic tuner with 2 kHz+ range; Peterson StroboClip HD recommended | Music store; Sweetwater; Amazon | not verified | not verified | Verify upper frequency range | Must read C7 = 2093 Hz reliably.

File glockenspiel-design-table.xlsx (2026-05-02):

Glockenspiel / Metallophone — Free-Free Beam Bar Calculator
Rectangular metal bars on CNC-routed frame · f = K × t / L² · Nodes at 22.4% from each end · Same physics as Marimba (§1D)
DESIGN INPUTS
Bar Material | 6061-T6 Aluminum | Bright, bell-like, lightest, easiest to cut
Bar Thickness (in) | 0.250 | 1/4 inch standard; thicker = higher pitch for same length
Bar Width (in) | 1.000 | Width affects volume/sustain but NOT pitch
Range | C5 - C7 | 2 octaves chromatic (25 bars)
Concert Pitch (Hz) | 440
Frame Material | Black Walnut | CNC-routed, for display and acoustic isolation
Bar Mounting | Cord through node holes | Drill at 22.4% from each end; rubber grommets
Layout | Piano keyboard | Naturals front row, sharps/flats back row (raised)
MATERIAL LIBRARY — Metal Bar K Constants (Free-Free Beam)
Material | E (GPa) | ρ (kg/m³) | K (free-free) | Tone Character | Cut Method | Cost
6061-T6 Aluminum | 68.9 | 2700 | 204431 | Bright, bell-like, long sustain | Band saw, chop saw | $
Brass (C260) | 110 | 8530 | 145325 | Warm, mellow, classic glock tone | Band saw, hacksaw | $$$
Steel (1018) | 200 | 7850 | 204267 | Harsh, metallic, very loud | Chop saw, angle grinder | $
304 Stainless Steel | 193 | 8000 | 198770 | Clean, modern, corrosion-resistant | Chop saw, angle grinder | $$
Phosphor Bronze | 110 | 8860 | 142593 | Rich, warm, excellent sustain | Band saw | $$$$
Selected K →
BAR CALCULATOR — 25 Chromatic Bars (C5–C7)
# | Note | MIDI | Freq (Hz) | Bar Length (in) | Node Hole (in) | Row | Position | Bar Width (in)
1 | C5 | 72 |  |  |  | Front | Natural
2 | C#5 | 73 |  |  |  | Back | Sharp
3 | D5 | 74 | Freq (Hz) | Bar Length (in) | Node Hole (in) | Front | Natural | Bar Width (in)
4 | D#5 | 75 |  |  |  | Back | Sharp
5 | E5 | 76 |  |  |  | Front | Natural
6 | F5 | 77 | Freq (Hz) | Bar Length (in) | Node Hole (in) | Front | Natural | Bar Width (in)
7 | F#5 | 78 |  |  |  | Back | Sharp
8 | G5 | 79 |  |  |  | Front | Natural
9 | G#5 | 80 | Freq (Hz) | Bar Length (in) | Node Hole (in) | Back | Sharp | Bar Width (in)
10 | A5 | 81 |  |  |  | Front | Natural
11 | A#5 | 82 |  |  |  | Back | Sharp
12 | B5 | 83 | Freq (Hz) | Bar Length (in) | Node Hole (in) | Front | Natural | Bar Width (in)
13 | C6 | 84 |  |  |  | Front | Natural
14 | C#6 | 85 |  |  |  | Back | Sharp
15 | D6 | 86 | Freq (Hz) | Bar Length (in) | Node Hole (in) | Front | Natural | Bar Width (in)
16 | D#6 | 87 |  |  |  | Back | Sharp
17 | E6 | 88 |  |  |  | Front | Natural
18 | F6 | 89 | Freq (Hz) | Bar Length (in) | Node Hole (in) | Front | Natural | Bar Width (in)
19 | F#6 | 90 |  |  |  | Back | Sharp
20 | G6 | 91 |  |  |  | Front | Natural
21 | G#6 | 92 | Freq (Hz) | Bar Length (in) | Node Hole (in) | Back | Sharp | Bar Width (in)
22 | A6 | 93 |  |  |  | Front | Natural
23 | A#6 | 94 |  |  |  | Back | Sharp
24 | B6 | 95 | Freq (Hz) | Bar Length (in) | Node Hole (in) | Front | Natural | Bar Width (in)
25 | C7 | 96 |  |  |  | Front | Natural
BILL OF MATERIALS
# | Item | Qty | Spec / Dimensions | Supplier / Notes | Est. Cost
1 | Aluminum bar stock | ~8 ft | 6061-T6, 1/4 x 1 inch flat bar | Online Metals, McMaster-Carr, local metal supplier | $25-40
2 | Frame wood (walnut/maple) | ~6 bf | 3/4 thick, for CNC-routed frame + pin rails | Hardwood dealer | $30-60
3 | Mounting cord (nylon/paracord) | ~10 ft | 550 paracord or braided nylon cord | Thread through node holes | $5-10
4 | Rubber grommets | 50 | 3/16 ID to isolate bars from pins | Prevent metal-on-metal buzz | $5-10
5 | Steel support pins/rods | 2 | 1/8 in stainless rod, length of frame | Bars rest on pins through node holes | $5-10
6 | Mallets (pair) | 1 | Brass or hard rubber head, 8-10 in handle | Purchase or CNC-turn handles | $10-25
7 | Chromatic tuner / strobe | 1 | Peterson StroboClip or app | Must handle high frequencies (2 kHz+) | $30-100
8 | Wood finish (oil/lacquer) | 1 | Tung oil, shellac, or spray lacquer | For frame; bars can be left raw or clear-coated | $10-20
9 | Rubber feet | 4 | Self-adhesive, 1/2 in | Prevent frame from sliding | $3-5
 | ESTIMATED TOTAL |  |  |  | $123-280
BUILD METHOD
# | Phase | Operation | Tools | Key Parameters
1 | Bar Prep | Cut 25 bars from stock, +1/4 in overlong | Chop saw with non-ferrous blade | Use stop block for repeatability; cut longest first
2 | Bar Prep | Deburr all cut ends; file smooth | Metal file, sandpaper (220 grit) | Clean edges reduce unwanted overtones
3 | Drill | Drill node holes at 22.4% from each end | Drill press, 3/16 in bit | Use calculator column F for exact distance; clamp bar securely
4 | Rough Tune | Check each bar with tuner; file end to raise pitch | Chromatic tuner, metal file | Cut long intentionally; can only shorten (raise pitch), never lengthen
5 | Fine Tune | File in tiny increments until within +/-2 cents of target | Fine file, strobe tuner | Rest bar on fingers at node points while tuning
6 | Frame | CNC-route frame from walnut: 2 rails + 2 side pieces | ShopBot CNC, 1/4 in downcut | Route pin channels, bar rest notches, optional CNC inlay on sides
7 | Frame | Drill pin holes through frame sides at each end | Drill press | Two rows: front (naturals), back raised 3/4 in (sharps)
8 | Frame | Sand and finish frame | Drum sander, finish of choice | Apply finish BEFORE mounting bars
9 | Assembly | Thread support pins through frame; add grommets | Stainless rod, rubber grommets | Grommets isolate bars acoustically from frame
10 | Assembly | Mount bars on pins through node holes | Hand assembly | Low C5 at left, high C7 at right; sharps behind naturals
11 | Final | Final tuning check with bars mounted | Strobe tuner | Mounting can shift pitch slightly; verify all 25 bars
12 | Final | Add rubber feet; make mallets if desired | Lathe (optional), rubber feet | Brass-headed mallets for bright tone; rubber for softer
DESIGN NOTES
1. Same free-free beam physics as your Marimba sheet, but metal K constants (~200k) are ~8x higher than wood (~25k). Metal bars are shorter and brighter.
2. Width does NOT affect pitch (just like wood tongue drums). Width controls volume and sustain. Wider = louder, more sustain.
3. Node holes at 22.42% from each end are CRITICAL. Drilling elsewhere will kill sustain. This is where vibration amplitude is zero.
4. Always cut bars LONGER than calculated. You can file down to raise pitch, but you cannot add material back. Target +1/4 in overlong.
5. Aluminum is ideal for first build: cheap, easy to cut, bright tone. Brass gives a warmer, more traditional glockenspiel sound but costs 5-10x more.
6. CNC opportunity: Route decorative inlay into the wooden frame side panels. Broinwood-style walnut+maple contrast. The flat rectangular frame is perfect for it.
7. Art fair potential: A pentatonic subset (C-D-E-G-A, 10 bars over 2 octaves) is simpler to build and play. Everyone can make music on pentatonic — no wrong notes.
8. For a metallophone (deeper, marimba-like), use thicker bars (3/8-1/2 in) and add resonator tubes underneath (quarter-wave: L = 13552/(4*freq) inches).
9. Comparison to Marimba: Aluminum glock = 25 bars in ~8 ft of stock. Padauk marimba = 49 bars requiring individual arch undercuts. Glock is 10x easier.
10. The frame can also serve as a xylophone stand for your existing wood Marimba/Xylophone bars — design the pin spacing to be compatible.
ART FAIR PENTATONIC — 10-Bar "No Wrong Notes" Glockenspiel
C Major Pentatonic: C-D-E-G-A over 2 octaves. Every combination sounds good — perfect for kids, art fairs, and sound gardens.
# | Note | MIDI | Freq (Hz) | Bar Length (in) | Node Hole (in) | Bar Width (in) | Row | Stock Needed
1 | C5 | 72 |  |  |  |  | Front
2 | D5 | 74 |  |  |  |  | Front
3 | E5 | 76 |  |  |  |  | Front
4 | G5 | 79 |  |  |  |  | Front |  | Bar Width (in) | Row | Stock Needed
5 | A5 | 81 |  |  |  |  | Front |  |  | Front
6 | C6 | 84 |  |  |  |  | Front
7 | D6 | 86 |  |  |  |  | Front
8 | E6 | 88 |  |  |  |  | Front
9 | G6 | 91 |  |  |  |  | Front
10 | A6 | 93 |  |  |  |  | Front
 |  |  | 7 | D6 | 86
PENTATONIC SUMMARY |  |  | 8 | E6 | 88
Total bars | 10 |  | 9 | G6 | 91
Total stock needed (in) |  |  | 10 | A6 | 93
Longest bar (C5)
Shortest bar (A6)
Frame length needed |  | ← bars + 1/4" gap between + 1" margin each end
ART FAIR PRODUCT NOTES
1. NO WRONG NOTES — every pair of bars in C pentatonic sounds consonant. Kids, adults, and non-musicians all make beautiful music instantly.
2. PRICING: A 10-bar pentatonic with CNC walnut frame + rubber mallet pair sells for $85-$150 at art/craft fairs. Material cost ~$40-60.
3. FRAME ARTWORK: Use Broinwood-style CNC inlay on the frame sides. Walnut frame + maple inlay logo/pattern. Laser-engrave your maker's mark.
4. SCALE VARIANTS: Offer C Major Pentatonic (bright), D Minor Pentatonic (warm/bluesy), and A Minor Pentatonic (mellow). Same 10-bar count, different note selection.
5. MALLETS: Include a pair of rubber-tipped mallets. Wooden dowel + rubber ball end. CNC-turn the handles for a premium feel. Costs <$5/pair.
6. DISPLAY: Build a tiered display stand that holds 3-4 glockenspiels at playing height. Customers play them = instant attraction = sales.
7. UPSELL: Pentatonic → Full Chromatic. Customer buys the 10-bar at the fair, orders the 25-bar from your website. The bars are the same stock.
8. SOUND GARDEN: A large outdoor version with thicker aluminum bars (3/8") on a weatherproof CNC cedar frame. Permanent installation at schools/parks.
9. ALTERNATIVE PENTATONIC SCALES:
C Major Pent: C-D-E-G-A (bright, happy) — MIDI: 72,74,76,79,81 / 84,86,88,91,93
D Minor Pent: D-F-G-A-C (warm, bluesy) — MIDI: 74,77,79,81,84 / 86,89,91,93,96
A Minor Pent: A-C-D-E-G (mellow, meditative) — MIDI: 69,72,74,76,79 / 81,84,86,88,91
G Major Pent: G-A-B-D-E (folk, Celtic feel) — MIDI: 79,81,83,86,88 / 91,93,95,98,100
10. To switch scales: just change the MIDI numbers in C94:C103. All lengths, node holes, and stock estimates update automatically.
WOLFRAM CLOUD NOTEBOOK SPEC — GLOCKENSPIEL
Free-free metal bars, no arch, hard mallets — bright, bell-like, 2 octaves higher than xylophone.
§1 — Origin & Etymology
Origin: derived from sets of small bells (Glocken=bells in German); modern bar form from 18th–19th c. military bands. Steel bars replaced bell sets for portability.
Glockenspiel' German 'bell play'. UK/orchestral term: 'bells' (in some scores); marching: 'bell lyre' or 'orchestra bells'.
Wolfram items: TimelinePlot[{18th c. bell sets, 1819 Berlioz uses orchestra bells, modern}].
§2 — Physics
Free-free beam, NO arch (like xylophone but metal). Steel/aluminum bars.
Mode 1: f = K·t/L², K_steel ~6× K_wood → bars much shorter than xylophone for same pitch.
Resonators rare on glockenspiel (small bars, dry tone is desired).
Wolfram functions: NDEigensystem free-free metal beam; Periodogram for partial verification.
§3 — Geometry & Materials
Sheet has 5 metal K constants: steel, aluminum, brass, possibly bronze. Bars 4–12" long × 0.5–1" wide × 0.2–0.4" thick.
25 bars chromatic C5–C7 (this sheet's spec). Walnut frame (CNC). Hard rubber/lexan/brass mallets.
Wolfram items: Manipulate metal + dims → frequency; visualize bar layout in walnut frame.
§4 — Animations
Mode-1 free-free Animate; mallet impact + decay envelope.
Material comparison: steel vs aluminum vs brass for same dims → different f.
§5 — Executable Cells
kMetal[E_,ρ_]:=(4.730^2/(2 π)) Sqrt[E/(12 ρ)] / 0.0254
kSteel = kMetal[200 10^9, 7850]
kAlum = kMetal[70 10^9, 2700]
lBar[f_,t_,K_]:=Sqrt[K t / f]
§6 — Wolfram Functions
NDEigensystem, Manipulate, Periodogram, CloudDeploy, FormFunction, APIFunction.
WOLFRAM EXPLORATIONS — GLOCKENSPIEL
Roadmap-inspired notebook ideas mapped to this instrument.
Material comparison
→ Material Science Scatter Plot (roadmap: filed as #37)
Steel vs aluminum vs brass vs bronze on E vs ρ axes; sized by K. Identify the bar material that gives best brightness-to-weight ratio for a marching glockenspiel.
Engineering
→ Tolerance Stack-Up (roadmap)
CNC-cut bar length tolerance ±σ → cents error per note. With ~10% K_metal variability, ±5-cents requires what mfg tolerance?
Wood Grain effect doesn't apply to metal — swap for grain structure / heat-treat consistency analysis.
Sound
Synthesize chromatic C5–C7 with hard-mallet attack; pentatonic art-fair playground variant.

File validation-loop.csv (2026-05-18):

check_id | packet_artifact | readiness_before | prediction_source | target | tolerance | method | measured_result | status | next_action | evidence | source_status
VL-001 | family-spec.csv | L1_packet | free-free beam formula with K=204431 | C5 A5 C7 predicted length and node rows | measurement_required | Cut long strike on soft node supports and compute K_eff | TBD | measurement_required | Cut only pilot bars first then update K if deviation exceeds 5 percent | validation.csv | formula_derived
VL-002 | drawings/mounting-detail.svg | L1_packet | node ratio 0.2242 and 0.7758 plus grommet support plan | Sustain without buzz or rod contact | measurement_required | Compare Shore 30A 50A 70A grommets using the pilot mounting rig | TBD | measurement_required | Record sustain seconds and damping notes before full mount | jig-decision.md | not_measured
VL-003 | cad/sw-global-variables.csv | L1_packet | 6061-T6 literature/workbook constants | Actual stock lot supports packet K within acceptable deviation | 5 percent K_eff threshold | Inspect supplier certificate and compare measured K_eff | TBD | measurement_required | Update material constants if actual lot differs materially | sourcing.csv | supplier_unverified
VL-004 | validation.csv | L1_packet | tuner and cents-error workflow | Final framed bars within plus/minus 5 cents at soft dynamics | plus/minus 5 cents | Record measured_hz cents_error sustain_s timbre and environment | TBD | measurement_required | Populate flat post-trim mounted and framed rows for pilot bars | validation.csv | no_measured_data
VL-005 | cnc/setup-sheet.md | L1_packet | frame layout and CNC setup sheet | Frame pockets and rod holes fit support hardware without bar contact | review_required | Full-size taped layout plus scrap rail pocket test | TBD | blocked | Do mockup before cutting walnut frame | cnc/setup-sheet.md | review_only
VL-006 | visual-output-register.csv | L1_packet | visual register authority chain | Generated/review visuals remain downstream of design-table/CAD authority | validator_pass | Run validate_visual_authority.py | TBD | open | Rerun after adding DXF CAD image or print outputs | visual-output-register.csv | registered

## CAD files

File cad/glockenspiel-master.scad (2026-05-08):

// Glockenspiel OpenSCAD starter.
// Build-critical dimensions live in family-spec.csv and CAD CSV files.
// This starter is for visual/spacing review and CAM mock-ups, not final tuning.
//
// No arch undercut, no resonator tubes (per design.md). Bars are flat metal stock.

$fn = 48;

function inch(x) = x * 25.4;

// Default parameters (6061-T6 Aluminum, workbook defaults)
default_thickness_in = 0.25;
default_width_in = 1.0;
default_node_hole_in = 0.1875;

module bar(length_in, width_in, thickness_in, node_1_in, node_2_in, node_hole_in = default_node_hole_in) {
    length = inch(length_in);
    width = inch(width_in);
    thickness = inch(thickness_in);
    n1 = inch(node_1_in);
    n2 = inch(node_2_in);
    node_hole = inch(node_hole_in);

    difference() {
        cube([length, width, thickness], center=false);

        // Node hole 1
        translate([n1, width / 2, -1])
            cylinder(h = thickness + 2, d = node_hole, center=false);

        // Node hole 2
        translate([n2, width / 2, -1])
            cylinder(h = thickness + 2, d = node_hole, center=false);
    }
}

module frame_rail(length_in, depth_in, thickness_in, num_bars) {
    // Walnut rail with grommet pockets and stainless rod hole
    length = inch(length_in);
    depth = inch(depth_in);
    thickness = inch(thickness_in);
    rod_dia = inch(0.140); // 1/8" rod plus clearance

    difference() {
        cube([length, depth, thickness], center=false);

        // Stainless rod through-hole, ~1/3 from rail bottom
        translate([-1, depth / 2, thickness / 3])
            rotate([0, 90, 0])
                cylinder(h = length + 2, d = rod_dia, center=false);

        // Grommet pockets (one per bar) on rail top
        for (i = [0 : num_bars - 1]) {
            x = inch(1.0) + i * inch(1.25);
            translate([x, depth / 2, thickness - inch(0.15)])
                cylinder(h = inch(0.30), d = inch(0.45), center=false);
        }
    }
}

// Representative configurations: pilot bars C5, A5, C7
// Use cad/design-table-inputs.csv for the full chromatic configuration set.
translate([0, 0, 0])
    bar(9.883, 1.000, 0.250, 2.216, 7.667); // GLK-C5

translate([0, inch(2.0), 0])
    bar(7.621, 1.000, 0.250, 1.709, 5.912); // GLK-A5

translate([0, inch(4.0), 0])
    bar(4.941, 1.000, 0.250, 1.108, 3.834); // GLK-C7

// Front rail (naturals row, 15 bars)
translate([0, inch(8.0), 0])
    frame_rail(33.25, 2.5, 0.75, 15);

// Back rail (sharps/flats, 10 bars, raised on spacer)
translate([0, inch(11.5), inch(0.5)])
    frame_rail(33.25, 2.0, 0.75, 10);

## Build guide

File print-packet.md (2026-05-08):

# Glockenspiel — Tuned Metal-Bar Idiophone Build Packet Print Packet

Generated: 2026-05-08

Packet folder: `/mnt/c/Users/Tony/Documents/GitHub/glockenspiel`

## File Map

| File | Purpose |
| --- | --- |
| `design.md` | Project intent, governing model, material decision matrix, mounting strategy, validation plan. |
| `bom.csv` | Bar set + frame + hardware + mallets + tooling + measurement gear. |
| `sourcing.csv` | Supplier candidates with all prices marked not verified. |
| `cut-list.csv` | Bar stock, walnut frame stock, and jig material cuts. |
| `drawing-brief.md` | Drawing classes, tolerances, and source files. |
| `assembly-manual.md` | Pilot-first build philosophy and full bench workflow. |
| `validation.csv` | Target/measured values per bar; pilot stages for C5/A5/C7. |
| `supplier-rfq.md` | RFQ template covering aluminum + alternates + walnut + hardware. |
| `visual-bom-brief.md` | Image-forward visual BOM plate spec. |
| `jig-decision.md` | Pilot fixture decisions and release gates. |
| `risks.md` | Acoustic / structural / ergonomic / supply / fit-finish risks. |
| `photo-shotlist.md` | Build-log photo plan. |
| `resources.md` | Provenance, family context, public-safety inventory. |
| `README.md` | Project artifact. |
| `family-spec.csv` | 25 chromatic + 10 pentatonic bar dimensions. |

## design.md

Project intent, governing model, material decision matrix, mounting strategy, validation plan.

# Glockenspiel Design Packet

## Project Intent

Build a 25-bar chromatic C5-C7 glockenspiel from the existing workbook design table, with a parallel 10-bar C-major-pentatonic art-fair variant that shares the same aluminum stock, frame jig, and validation discipline. The first build target is a CNC-routed walnut frame carrying 6061-T6 aluminum bars, suspended at the free-free nodes by rubber-grommeted cord through drilled node holes, with stainless support pins and no resonators.

The useful boundary for this packet is "build-ready documentation, not finished CAD or measured tuning data." Native SolidWorks files do not exist yet; the `cad/` folder defines the global-variable and design-table contract Tony can use to build the real model. All published bar lengths are first-pass cut-long targets — actual K varies with heat-treat and stock lot, so every bar should be cut at predicted length plus 0.25 in trim allowance and tuned down to pitch.

## Design Intake

| Field | Value |
| --- | --- |
| Instrument | Glockenspiel / Metallophone |
| Instrument family | Free-free beam idiophone (metal), no arch, no resonator |
| Active build range | C5-C7 chromatic, 25 bars (primary); C-major pentatonic, 10 bars (art-fair variant) |
| Source workbook | `glockenspiel-design-table.xlsx`, sheet `Glockenspiel`, range `A1:L174` |
| Primary material | 6061-T6 Aluminum, workbook K constant `204431` |
| Bar stock | `0.25 in` thick x `1.00 in` wide flat bar |
| Frame | CNC-routed Black Walnut, piano-keyboard layout (naturals front, sharps back) |
| Mounting | Cord through node holes at 22.4% and 77.6% of bar length, rubber grommets, 1/8 in stainless support rod |
| Done-bar reference | `tonykoop/marimba` for free-free node math and validation discipline; tongue-drum README for documentation shape |

## Governing Model

### Bar Pitch (Free-Free Beam, Metal)

Glockenspiel bars are treated as free-free beams in their first flexural mode:

```text
lambda_1 = 4.730
f_1 = (lambda_1^2 / (2*pi*L^2)) * sqrt(E*I/(rho*A))
```

The workbook uses the practical shop form:

```text
f ~= K * t / L^2
L ~= sqrt(K * t / f)
```

where:

- `f` is target frequency in Hz.
- `K` is the metal-specific free-free bar constant in imperial units.
- `t` is bar thickness in inches.
- `L` is bar length in inches.

For the active packet:

```text
material = 6061-T6 Aluminum
K = 204431
t = 0.250 in
w = 1.000 in
```

The K formula derived from the lambda_1 = 4.730 mode shape is:

```text
K_metal = (lambda_1^2 / (2 * pi)) * sqrt(E / (12 * rho)) / 0.0254
```

with `E` in Pa and `rho` in kg/m^3. This is the same formula family used by the marimba for wooden bars; only the material constants change.

Width does NOT affect frequency for a free-free beam in this mode. Width controls volume, sustain envelope, stiffness distribution, and the visual dimension of the bar — not pitch. The workbook's bar-width column is a sourcing convenience, not a tuning lever.

### No Arch, No Resonator

Per workbook row 140 and `references/acoustic-models.md`:

- **No arch undercut.** Glockenspiel bars are short and high-pitched; the dry, bright tone is desired. Arching would lower fundamentals and add manufacturing complexity without improving the instrument's musical role. Marimba/xylophone arch logic does not transfer.
- **No resonator tubes.** Small bars produce an immediate, bell-like attack. Resonator coupling at C5-C7 frequencies would require very short tubes (a few inches at C5, less than 1.5 in at C7) that are mechanically awkward and acoustically marginal.

### Empirical-Correction Discipline

NAF K2 corrections, vessel-flute Helmholtz corrections, and cantilever wood K-constant tables do **not** apply to free-free metal beams. See the "Empirical-correction guard rules" section of `references/acoustic-models.md`. The only honest correction loop here is:

1. Cut each pilot bar (C5, A5, C7) cut-long by 0.25 in.
2. Mount on soft node supports and measure flat-bar Hz.
3. Compute effective K from `K_eff = f * L^2 / t`.
4. If pilot K_eff differs from workbook K by more than 5%, update the K constant in `family-spec.csv` (and the workbook B21 cell) before cutting the remaining bars.
5. Trim to pitch in 0.05 in increments.

This is what makes the workflow honest: predicted lengths are the starting point, measured Hz is the ground truth, and each shop-purchased lot of aluminum re-calibrates K.

### Nodes And Mounting

Free-free node positions are fixed by the mode shape:

```text
node_1 = 0.2242 * L
node_2 = 0.7758 * L
```

Mounting strategy:

- Drill 0.1875 in (3/16 in) holes through the bar at the node positions, perpendicular to the long face.
- Thread 550 paracord (or low-stretch nylon) through the four node holes (two per bar, one cord per row).
- Rest each bar on rubber grommets seated in the walnut frame; the cord captures the bar without compressing the grommets.
- 1/8 in stainless steel rod runs the length of each row through the frame as a backup and travel restraint.

Critical: the rubber grommet durometer dominates sustain. Soft (~Shore 30A) grommets give long sustain; hard (~Shore 70A) grommets damp quickly. Pilot the C5/A5/C7 bars on three durometers before standardizing.

## Material Decision Matrix

The workbook's K library carries five candidate metals. Aluminum is the workbook default and packet primary. Surface the alternatives explicitly so the user can rerun the family-spec for any of them.

| Material | E (GPa) | rho (kg/m^3) | K | Tone Character | Cut Method | Notes |
| --- | ---: | ---: | ---: | --- | --- | --- |
| 6061-T6 Aluminum | 68.9 | 2700 | 204431 | Bright, bell-like, long sustain | Band saw, chop saw | Lightest, easiest to cut, lowest cost. Packet default. |
| Brass C260 | 110 | 8530 | 145325 | Warm, mellow, classic glock tone | Band saw, hacksaw | Heavier, traditional orchestra-bell tone, higher material cost. |
| Steel 1018 | 200 | 7850 | 204267 | Harsh, metallic, very loud | Chop saw, angle grinder | Loud and bright; can be perceived as harsh. K is similar to aluminum because E/rho ratio is similar. |
| 304 Stainless Steel | 193 | 8000 | 198770 | Clean, modern, corrosion-resistant | Chop saw, angle grinder | Outdoor / weather-resistant variant. |
| Phosphor Bronze | 110 | 8860 | 142593 | Rich, warm, excellent sustain | Band saw | Premium tone, highest material cost. |

To rebuild the family-spec for a different metal: replace the K column in `family-spec.csv` and recompute `predicted_length_in = sqrt(K * t / f)`. Width and node positions stay the same.

## Bar Schedule

The full 25-bar chromatic schedule is in `family-spec.csv`. Representative rows for 6061-T6 aluminum at t=0.250, w=1.000:

| Note | MIDI | Target Hz | Length in | Node 1 in | Node 2 in |
| --- | ---: | ---: | ---: | ---: | ---: |
| C5 | 72 | 523.251 | 9.883 | 2.216 | 7.667 |
| A5 | 81 | 880.000 | 7.621 | 1.709 | 5.912 |
| C6 | 84 | 1046.502 | 6.988 | 1.567 | 5.422 |
| A6 | 93 | 1760.000 | 5.389 | 1.208 | 4.181 |
| C7 | 96 | 2093.005 | 4.941 | 1.108 | 3.834 |

The 10-bar pentatonic art-fair variant (C5, D5, E5, G5, A5, C6, D6, E6, G6, A6) is also in `family-spec.csv` under `scale_label = C major pentatonic art-fair`. It shares the same K, t, w defaults and reuses the same frame jig with different drill positions.

## Frame Layout

Piano-keyboard layout. Naturals (C, D, E, F, G, A, B) live in the front row; sharps/flats live in the back row, raised about 0.5 in. From the workbook (cells B107-B110):

```text
total_bar_stock_chromatic = 191.02 in (~16 ft) for 25 bars cut long by 0.5 in each
longest_bar = 9.883 in (C5)
shortest_bar = 4.941 in (C7)
chromatic_frame_length = 25 * (w + 0.25) + 2 = 33.25 in
pentatonic_frame_length = 10 * (w + 0.25) + 2 = 14.50 in
```

Frame depth follows the longest bar plus 1 in margin on each end (about 12 in). Final frame ergonomics (height, mallet reach, accidental row offset, transport handles) are TBD until a full-size mock-up is taped on a bench.

## Striker Hardness

Striker hardness controls the timbre as much as the bar material does. Workbook row 145 lists three options:

| Striker Head | Tone | Use |
| --- | --- | --- |
| Brass | Sharpest attack, bright, percussive | Orchestral / soloist; loud rooms |
| Hard rubber | Balanced bright/warm | Studio / classroom; default for art-fair pentatonic |
| Lexan / Delrin | Bright but less metallic than brass | Solo work; chimes |

Include at least two pairs in the BOM; let the player choose by context.

## Hardware Alignment

| Operation | Tool / Fixture | Datum | Release Check |
| --- | --- | --- | --- |
| Bar receiving | Calipers, scale, scratch awl | Edge of stock | Verify thickness 0.25 +/- 0.005 in, width 1.00 +/- 0.010 in, no surface damage |
| Mark length and nodes | Stop-block sled, square, fine marker | Left end B, centerline C | Length within +/- 0.020 in of `predicted_length_in + 0.25` (cut long); nodes within +/- 0.020 in |
| Cut to length | Band saw or chop saw with stop block | Left end B | Squareness within 0.5 deg; deburr both ends |
| Drill node holes | Drill press with V-block fence and backer | Centerline C, node line | Hole diameter 0.1875 +/- 0.005 in; perpendicular within 1 deg; no edge tear-out |
| Deburr / file | Bench file, deburring tool, sandpaper | Top face A | Edges chamfered 0.005-0.010 in; node holes deburred |
| Strike test (flat) | Soft foam supports at nodes, tuner, mic | Acoustic node | Record measured Hz, cents error, sustain s in `validation.csv` |
| Trim to pitch | Belt sander or fine file at the ends | Acoustic-tuning datum | Remove material symmetrically from both ends; sneak up slowly (raising pitch is hard to reverse) |
| Mount | Walnut frame jig, paracord, grommets, 1/8 in stainless rod | Frame centerline | All bars seated; cord captures every bar; no metal-on-metal contact |
| Final tune (framed) | Frame on bench, tuner, mallets | Frame centerline | Every bar within +/- 5 cents at soft/medium dynamics |

`jig-decision.md` is the controlling fixture decision record. Pilot fixtures (cut sled, node-drill V-block jig, mounting test rig) are built only for C5/A5/C7 before the full 25-bar run.

## Open Assumptions

- Active packet uses C5-C7 (workbook default). Lower-pitched bass-glock variants (C4-C6) are out of scope for this build.
- 6061-T6 aluminum is the workbook-selected material. Actual stock lot K may differ by 5-10%. The validation pilot is the K-recalibration step, not a confirmation.
- Mounting cord material, grommet durometer, and stainless rod diameter are first-pass picks — pilot at three durometers before freezing.
- Walnut frame geometry, mallet selection, and accidental row offset are TBD until a full-size taped layout passes ergonomic review.
- Final finish on bars: leave raw or clear-coat. Clear coats add mass; expect a small flat-pitch shift (typically <5 cents). Tune after finish if a finish is applied.
- No measured bar data exists yet, so all frequencies are target predictions.

## Validation Plan

1. Cut three pilot bars first: C5, A5, C7. Cut each to `predicted_length_in + 0.25`.
2. Mass-and-strike test on foam supports before drilling node holes (`flat_bar` row in `validation.csv`). Compute K_eff = f * L^2 / t.
3. If pilot K_eff differs from workbook K = 204431 by more than 5%, update the K column in `family-spec.csv` and the workbook B21 cell before cutting the remaining bars.
4. Drill node holes; mount on cord+grommet rig (`mounted` row). Record measured Hz, cents error, and sustain (time to first 6 dB drop after a moderate strike).
5. Trim each pilot to within +/- 10 cents by removing material symmetrically from both ends. Cents error formula:

```text
cents = 1200 * log2(measured_hz / target_hz)
```

6. Mount in the walnut frame (`framed` row). Strike at soft, medium, and loud dynamics; check for buzz, rubber-on-stainless-rod rattle, and frame resonance.
7. Cut the remaining 22 chromatic bars (and 7 additional pentatonic bars if building both) using the calibrated K and the pilot trim discipline.
8. Final assembly check: every bar within +/- 5 cents at soft dynamics, no buzz, sustain consistent across the row to within 30%.

## Provenance

- Source workbook: `glockenspiel-design-table.xlsx`, generated before this v4.3 packet run. 94 formulas, 16 blue inputs, single sheet `Glockenspiel`.
- Skill workflow: `instrument-maker-v4` v4.3 root-mode.
- Reference family: `cantilever-idiophone` / `free-free-bar-idiophone`. Done-bar sibling: `tonykoop/marimba`.
- Cultural context: glockenspiel is a modern Western orchestral idiophone (German "bells play") derived from 18th-19th century military-band bell sets and Berlioz-era orchestral bells. No cultural-appropriation review required for the instrument category.

## bom.csv

Bar set + frame + hardware + mallets + tooling + measurement gear.

| item | subassembly | part_name | qty | unit | material_or_spec | make_buy | status | estimated_cost | notes |
| --- | --- | --- | --- | --- | --- | --- | --- | --- | --- |
| 1 | Bar set | C5-C7 chromatic tuned bars | 25 | ea | 6061-T6 Aluminum 0.25 x 1.00 in flat bar | make | workbook-derived | $25-40 | Individual dimensions in family-spec.csv. Cut long by 0.25 in and trim to pitch. |
| 2 | Bar set (alt) | Pentatonic art-fair tuned bars | 10 | ea | 6061-T6 Aluminum 0.25 x 1.00 in flat bar | make | workbook-derived | included | Same stock as chromatic. C major pentatonic block in family-spec.csv. |
| 3 | Bar material (alt) | Brass C260 0.25 x 1.00 flat bar | as needed | ft | Brass C260 K=145325 | buy | alternate | $$$ | Premium tone variant. Regenerate family-spec.csv with K=145325 if used. |
| 4 | Bar material (alt) | Steel 1018 0.25 x 1.00 flat bar | as needed | ft | Steel 1018 K=204267 | buy | alternate | $ | K nearly identical to aluminum but heavier and brighter; same predicted lengths. |
| 5 | Bar material (alt) | 304 Stainless flat bar | as needed | ft | 304 SS K=198770 | buy | alternate | $$ | Outdoor / weather-resistant variant. |
| 6 | Bar material (alt) | Phosphor Bronze flat bar | as needed | ft | Phosphor Bronze K=142593 | buy | alternate | $$$$ | Best sustain; highest cost. |
| 7 | Frame | Black Walnut frame stock | ~6 | bf | 3/4 in thick clear straight-grain walnut | make | workbook-derived | $30-60 | CNC-routed front + back rails plus end caps. Hard maple acceptable substitute. |
| 8 | Frame | Frame fastener kit | 1 | set | Wood screws, threaded inserts, washers | buy | TBD | $5-10 | Prefer removable fasteners for tuning access. |
| 9 | Hardware | 550 Paracord (mounting cord) | ~12 | ft | Low-stretch braided nylon cord 4 mm | buy | TBD | $5-10 | Sized to pass through 3/16 in node holes without buzz. |
| 10 | Hardware | Rubber grommets | ~50 | ea | 3/16 in ID rubber grommets in two-three durometer candidates | buy | TBD | $5-15 | Pilot Shore 30A / 50A / 70A on C5/A5/C7 before standardizing. |
| 11 | Hardware | Stainless steel support rod | 2 | ea | 1/8 in 304 stainless steel rod cut to frame length | buy | TBD | $5-10 | Front and back row backup restraints; not load-bearing. |
| 12 | Hardware | Self-adhesive rubber feet | 4 | ea | 1/2 in rubber feet | buy | TBD | $3-5 | Prevent frame sliding on table. |
| 13 | Mallets | Hard rubber mallets | 1 | pair | Hard rubber head 1 in dia / 8-10 in handle | buy | TBD | $10-20 | Default striker; balanced bright/warm tone. |
| 14 | Mallets | Brass mallets | 1 | pair | Brass head 0.75 in dia / 8-10 in handle | buy | TBD | $15-25 | Bright orchestral attack; ship as upgrade option. |
| 15 | Mallets (alt) | Lexan / Delrin mallets | 1 | pair | Lexan or Delrin head | buy | TBD | $15-20 | Less metallic than brass; alternative for solo work. |
| 16 | CNC tooling | 1/4 in downcut spiral router bit | 1 | ea | Hardwood-capable carbide downcut | buy | TBD | $15-25 | Walnut frame profile and grommet pockets. |
| 17 | CNC tooling | 1/8 in upcut spiral router bit | 1 | ea | Hardwood-capable carbide upcut | buy | TBD | $15-25 | Small reliefs and inlay grooves. |
| 18 | CNC tooling | 1/8 in V-bit (60 deg) | 1 | ea | V-carving bit for inlay/engraving | buy | TBD | $15-25 | Optional: Broinwood-style frame inlay. |
| 19 | Bar tooling | 3/16 in HSS or carbide drill bit | 1 | ea | Brad-point or jobber-length bit | buy | TBD | $5-10 | Node-hole drilling. |
| 20 | Bar tooling | Non-ferrous carbide chop-saw blade | 1 | ea | 80T or 100T carbide blade for aluminum | buy | TBD | $30-60 | Cut bars to length without burr-up. |
| 21 | Finish | Tung oil or shellac for frame | 1 | can | Frame finish only; bars left raw or clear-coated separately | buy | TBD | $10-20 | Avoid heavy finishes that load the playing surface. |
| 22 | Finish | Optional clear coat for bars | 1 | can | Thin spray lacquer if desired | buy | TBD | $5-15 | Test pitch shift on offcut before committing. |
| 23 | Measurement | Chromatic tuner / strobe | 1 | ea | Peterson StroboClip HD or app capable of 2 kHz+ | buy/owned | TBD | $30-100 | Must reliably read C7 = 2093 Hz. |
| 24 | Measurement | Microphone for sustain logging | 1 | ea | Dynamic or condenser mic; phone app acceptable for first build | buy/owned | TBD | $0-100 | Capture sustain to first 6 dB drop. |
| 25 | Measurement | Calipers + scale + strike support foam | 1 | set | Digital calipers, kitchen scale, foam blocks | buy/owned | TBD | $0-30 | For K_eff calibration and node-support strike tests. |

## sourcing.csv

Supplier candidates with all prices marked not verified.

| item | stable_spec | supplier_candidates | current_price_status | lead_time_status | verification_needed | notes |
| --- | --- | --- | --- | --- | --- | --- |
| 6061-T6 Aluminum flat bar | 0.25 x 1.00 in flat bar; T6 temper preferred for consistent K; minimum 18 ft per build with pilot scrap | Online Metals; McMaster-Carr; Metal Supermarkets; local metal supplier | not verified | not verified | Verify temper and mill lot; request mill cert for K-calibration record | Buy enough for 25 chromatic + 10 pentatonic + at least 3 pilot/scrap bars from one mill lot. |
| Brass C260 flat bar (alt) | 0.25 x 1.00 in C260 yellow brass flat bar | Online Metals; McMaster-Carr; Metal Supermarkets | not verified | not verified | Verify alloy and temper | Premium tone alt; regenerate family-spec.csv with K=145325 before cutting. |
| Steel 1018 flat bar (alt) | 0.25 x 1.00 in 1018 cold-rolled steel flat bar | Online Metals; McMaster-Carr; local metal supplier | not verified | not verified | Verify cold-rolled vs hot-rolled | Loud and bright; same family-spec lengths as aluminum (K nearly identical). |
| 304 Stainless flat bar (alt) | 0.25 x 1.00 in 304 SS flat bar | Online Metals; McMaster-Carr | not verified | not verified | Verify finish (#4 vs polished) | Outdoor variant; regenerate family-spec.csv with K=198770. |
| Phosphor Bronze flat bar (alt) | 0.25 x 1.00 in phosphor bronze flat bar | Online Metals; specialty metal supplier | not verified | not verified | Verify alloy (510 vs 544) | Premium tone; highest cost; regenerate family-spec.csv with K=142593. |
| Walnut frame lumber | Clear straight-grain Black Walnut 4/4 dressed to 3/4 in thick; sufficient for two rails (~36 in long) plus end caps and accidental row | Local hardwood dealer; Woodcraft; Rockler | not verified | not verified | Verify board flatness and absence of checks | Hard maple or cherry acceptable substitutes; frame wood does not affect bar tuning. |
| Paracord (mounting) | 550 paracord or low-stretch braided nylon cord; 4 mm diameter to fit through 3/16 in node holes | Outdoor / climbing supplier; Amazon; local hardware | not verified | not verified | Verify diameter and stretch under tension | Must not buzz against bar holes. |
| Rubber grommets | 3/16 in ID rubber grommets in Shore 30A / 50A / 70A durometers | McMaster-Carr; marimba parts supplier; Amazon | not verified | not verified | Verify durometer accuracy and sample three options | Two grommets per bar minimum; durometer is the dominant sustain control. |
| Stainless steel support rod | 1/8 in 304 stainless steel rod in 36 in lengths | McMaster-Carr; OnlineMetals; local hardware | not verified | not verified | Verify diameter +/- 0.005 in | Two rods per instrument (front + back row). |
| Self-adhesive rubber feet | 1/2 in rubber feet with 3M adhesive backing | McMaster-Carr; hardware store | not verified | not verified | Verify adhesion strength | Four per frame. |
| Hard rubber mallets | Pair of hard-rubber-headed mallets with 8-10 in wood handles | Music supplier; Amazon; Steve Weiss Music | not verified | not verified | Verify head durometer | Default striker for the assembled instrument. |
| Brass mallets | Pair of brass-headed mallets with 8-10 in wood handles | Music supplier; Steve Weiss Music | not verified | not verified | Verify head finish (polished vs natural) | Optional bright-attack upgrade. |
| Lexan / Delrin mallets | Pair of synthetic-headed mallets | Music supplier; specialty supplier | not verified | not verified | Verify head material | Optional alternative striker; less metallic than brass. |
| CNC router bits | 1/4 in downcut + 1/8 in upcut + 1/8 in V-bit (carbide) | Amana; Whiteside; Onsrud; local CNC supplier | not verified | not verified | Verify shank diameter for collet | Walnut frame profile and inlay. |
| Aluminum drill bit | 3/16 in HSS or carbide bit; brad-point or jobber-length | McMaster-Carr; local hardware | not verified | not verified | Verify bit type | Node-hole drilling. |
| Non-ferrous saw blade | 80T or 100T carbide blade for aluminum chop saw | Local tooling supplier; Amazon | not verified | not verified | Verify arbor size | Avoid burr-up on bar ends. |
| Frame finish | Tung oil or shellac for walnut frame | Wood finishing supplier; hardware store | not verified | not verified | Verify finish compatibility with walnut | Avoid heavy lacquer on the playing surface. |
| Chromatic tuner | Strobe or chromatic tuner with 2 kHz+ range; Peterson StroboClip HD recommended | Music store; Sweetwater; Amazon | not verified | not verified | Verify upper frequency range | Must read C7 = 2093 Hz reliably. |

## cut-list.csv

Bar stock, walnut frame stock, and jig material cuts.

| cut_id | subassembly | qty | material | rough_dimension_in | finished_dimension_or_reference | operation | notes |
| --- | --- | --- | --- | --- | --- | --- | --- |
| CUT-BAR-CHROM-LOW | Chromatic bars C5-G5 | 8 | 6061-T6 Aluminum 0.25 x 1.00 | Cut 0.25 in oversize from family-spec.csv lengths | See GLK-C5 through GLK-G5 in family-spec.csv | Mark/cut/drill/deburr/trim | Longest bars are the stock-yield driver; cut long and trim to pitch. |
| CUT-BAR-CHROM-MID | Chromatic bars Gsharp5-G6 | 12 | 6061-T6 Aluminum 0.25 x 1.00 | Cut 0.25 in oversize from family-spec.csv lengths | See GLK-Gsharp5 through GLK-G6 in family-spec.csv | Mark/cut/drill/deburr/trim | Mid-range bars; standard trim discipline. |
| CUT-BAR-CHROM-HIGH | Chromatic bars Gsharp6-C7 | 5 | 6061-T6 Aluminum 0.25 x 1.00 | Cut 0.25 in oversize from family-spec.csv lengths | See GLK-Gsharp6 through GLK-C7 in family-spec.csv | Mark/cut/drill/deburr/trim | Short bars are pitch-sensitive; trim in 0.05 in increments. |
| CUT-BAR-PENT | Pentatonic art-fair bars (10) | 10 | 6061-T6 Aluminum 0.25 x 1.00 | Cut 0.25 in oversize from family-spec.csv lengths | See GLK-PENT-* in family-spec.csv | Mark/cut/drill/deburr/trim | Optional second instrument; same stock as chromatic. |
| CUT-FRAME-FRONT | Walnut front rail (naturals row) | 1 | Black Walnut 3/4 in thick | ~34 in x ~3 in x 3/4 in rough blank | 33.25 in finished length per design.md | CNC profile/pocket/drill | Holds 15 natural bars (chromatic) or 7 naturals (pentatonic). |
| CUT-FRAME-BACK | Walnut back rail (sharps/flats row) | 1 | Black Walnut 3/4 in thick | ~34 in x ~3 in x 3/4 in rough blank | 33.25 in finished length per design.md (raised 0.5 in) | CNC profile/pocket/drill | Holds 10 sharps/flats (chromatic) or 3 (pentatonic). |
| CUT-FRAME-ENDS | Walnut end caps | 2 | Black Walnut 3/4 in thick | ~5 in x ~3 in x 3/4 in rough blank | Width set by frame depth (~4 in) plus 1 in margin | Cut/drill/joint | End caps tie front and back rails; carry stainless rod holes. |
| CUT-FRAME-CROSS | Walnut cross members (optional) | 2 | Black Walnut 3/4 in thick or hardwood plywood | ~14 in x ~2 in x 3/4 in rough blank | Width set by frame ergonomics | Cut/drill | Optional cross members for stiffness; not required for first build. |
| CUT-JIG-MARK | Marking sled (jig) | 1 | MDF or scrap hardwood | Sized to longest bar plus 6 in | Per JD-020 in jig-decision.md | Cut/clamp/scribe | Stop-block sled for length and node marking. |
| CUT-JIG-DRILL | Node-hole V-block jig (jig) | 1 | MDF or hardwood | ~12 in x 4 in x 1.5 in | Per JD-040 in jig-decision.md | Cut/route/V-groove/drill | V-block fence with hardwood backer for drill press. |
| CUT-JIG-MOUNT | Mounting prototype rig (jig) | 1 | Walnut offcut or scrap hardwood | Three short blocks ~3 in x 1 in x 0.75 in | Per JD-060 in jig-decision.md | Cut/drill/grommet test | Three-block rig for grommet durometer pilot. |
| CUT-JIG-FRAME | Full-size paper or MDF frame template | 1 | Paper or thin MDF | Sized to chromatic frame footprint (~34 in x ~12 in) | Per JD-070 in jig-decision.md | Print or scribe | Validate ergonomics before cutting walnut. |

## drawing-brief.md

Drawing classes, tolerances, and source files.

# Drawing Brief

## Drawing Set

The current packet requires five build-critical drawing classes:

1. **Per-bar dimensioned SVGs** for the three pilot bars (`drawings/GLK-C5-body.svg`, `drawings/GLK-A5-body.svg`, `drawings/GLK-C7-body.svg`). These show the long flat bar, node-hole positions, length dimension, thickness, and a title block. Additional per-bar SVGs can be generated from `family-spec.csv` if the full chromatic set is required.
2. **Family overview** (`drawings/family-overview.svg`) — scaled side-by-side outline of all 25 chromatic bars from C5 (longest) to C7 (shortest), labeled with note + Hz + length, to show the visual tuning gradient.
3. **Frame layout** (`drawings/frame-layout.svg`) — top-down piano-keyboard layout with naturals in the front row, sharps/flats in the back row raised 0.5 in. Shows bar spacing, accidental row offset, frame envelope, and player-side datum.
4. **Mounting detail** (`drawings/mounting-detail.svg`) — section view through one bar at a node showing: bar profile, 3/16 in node hole, paracord, rubber grommet, walnut frame pocket, and 1/8 in stainless support rod position. Critical for explaining why the bar is acoustically isolated from the frame.
5. **Visual BOM plate** (`drawings/visual-bom-plate.svg`) — exploded callout of bar set, frame rails, hardware, and tooling with numbered references to `bom.csv`.

## Drawing Standards

- Units: inches.
- Primary datum for each bar: left end (B) and centerline (C). Top face (A) is implicit.
- Node holes shown at `0.2242 * L` and `0.7758 * L` from the left end.
- Bar dimensions to call out: length, width, thickness, node positions, hole diameter (3/16 in).
- Frame dimensions: rail length, rail thickness, accidental row offset, grommet pocket diameter and depth, support rod hole diameter.
- Tolerances:
  - Bar length cut: `+0.250 in / -0.000 in` before tuning (cut long).
  - Final length: tune-to-pitch, not dimension-only.
  - Thickness: `+/- 0.005 in` (verified at receiving).
  - Node hole placement: `+/- 0.020 in`.
  - Frame pocket: `+/- 0.010 in`.
- CNC notes: bit diameter, stepover, Z-zero surface, tabs, workholding, and release checks per `cnc/setup-sheet.md`.
- Jig notes: which fixture carries datum A/B/C and which validation row releases the operation.

## Open Drawing Questions

- Whether to generate per-bar SVGs for all 25 chromatic notes or only the three pilots.
- Final accidental row offset (currently 0.5 in raised; ergonomic test may reduce).
- Final grommet pocket depth (depends on selected grommet supplier).
- Whether the optional Broinwood-style inlay on rail sides gets a dedicated detail drawing.
- Whether to draw the brass/steel/stainless/phosphor-bronze alternate-metal variants.

## Source Files

- `family-spec.csv` (canonical bar dimensions)
- `design.md` (governing model, mounting strategy)
- `glockenspiel-design-table.xlsx` (parametric workbook)
- `cad/glockenspiel-master.scad` (3D starter)
- `cad/SolidWorks-MasterLayout-Plan.md` (SolidWorks contract)
- `cnc/setup-sheet.md` (operation order, datums)
- `jig-decision.md` (fixture release gates)

## assembly-manual.md

Pilot-first build philosophy and full bench workflow.

# Glockenspiel Assembly Manual

## Build Philosophy

Cut three pilot bars before committing the whole set: C5, A5, and C7. They bound the longest/lowest bar, the mid-scale 880 Hz reference, and the shortest/highest bar. Use their measured pitch and mounting response to decide whether the workbook K constant, selected aluminum stock, and node-hole geometry are ready for the full 25-bar run.

## Preflight

- [ ] Confirm active range: chromatic C5-C7 (25 bars) and / or pentatonic C-major art-fair variant (10 bars).
- [ ] Confirm selected metal (default 6061-T6 Aluminum, K=204431) and verify stock thickness (0.250 in) and width (1.000 in) with calipers.
- [ ] Confirm grommet durometer candidates (suggested: Shore 30A, 50A, 70A).
- [ ] Confirm 1/8 in stainless support rod is on hand and cut to frame length plus 0.5 in margin per end.
- [ ] Review `jig-decision.md` and build only the pilot jigs (JD-010 to JD-050).
- [ ] Print or open `drawings/GLK-C5-body.svg`, `GLK-A5-body.svg`, `GLK-C7-body.svg`, `mounting-detail.svg`, and `cnc/setup-sheet.md`.

## Jig Decision Gate

Use `jig-decision.md` as the shop stop/go sheet. Do not cut the full 25-bar set, drill the final walnut frame, or commit to a permanent grommet system until the pilot rows in `validation.csv` have measured values for `flat_bar`, `post_trim`, `mounted`, and `framed` for C5, A5, and C7.

## Bar Workflow

1. Receive aluminum flat bar. Verify thickness 0.250 +/- 0.005 in and width 1.000 +/- 0.010 in. Reject stock with deep scratches in the playing area or evident bow.
2. Mark each bar with member_id, target note, target Hz, and top face per `family-spec.csv`.
3. Mark each bar at length = `predicted_length_in + 0.25` (cut long, trim to pitch).
4. Mark node positions at `0.2242 * L` and `0.7758 * L` from the left end. Use a centerline gauge for the node-hole position across the bar width.
5. Cut to marked length using the chop saw with non-ferrous carbide blade or band saw with miter gauge. Deburr both ends.
6. Drill 0.1875 in (3/16 in) node holes through the bar at marked positions. Use a V-block fence on the drill press, hardwood backer, depth stop. Peck-drill, lubricate, deburr both faces.
7. Light file/sand on bar edges and corners. Do not round the top face contact zone unnecessarily.
8. Strike-test on foam supports placed at the node positions. Record measured Hz, sustain, timbre, tuner model, and shop temperature in `validation.csv` (`flat_bar` row).

## Tuning Direction

- To lower pitch: remove material from the underside center of the bar (small file or sander). Do this only as a last resort; metal bars are usually tuned by trimming length.
- To raise pitch: shorten the bar by trimming both ends symmetrically. Sneak up in 0.05 in increments — raising pitch is hard to reverse.
- Symmetrical trimming preserves the node-position ratio. Asymmetric trimming shifts the node line and damps mounting.
- Tune flat bars before drilling node holes if the K_eff is off by more than 5%; the calibrated K updates the predicted lengths for all remaining bars.

## Mounting Workflow

1. Cut paracord (or low-stretch braided nylon) to frame length plus 12 in margin.
2. Thread paracord through the front-row node holes (one cord through `node_1` of every front-row bar, a second cord through `node_2`).
3. Thread the back-row sharp/flat bars on a separate pair of cords.
4. Seat each bar on rubber grommets in the frame. Grommets seat in pre-drilled frame pockets; cord captures the bar without compressing the grommets.
5. Run the 1/8 in stainless support rod through the frame as a backup restraint (do not load-bearing the rod).
6. Tension cords just enough to keep bars from sliding; cords should not damp the bar at the nodes.
7. Strike-test each bar after mounting. Record `mounted` row in `validation.csv`.

## Frame Workflow

1. Validate ergonomics first: tape a full-size bar layout on the bench (see `drawings/frame-layout.svg`). The intended player reaches every bar without shoulder strain.
2. CNC-route the walnut frame: front rail (naturals), back rail (sharps/flats raised 0.5 in), end caps, grommet pockets, support rod holes, fastener holes.
3. Optionally laser- or CNC-engrave a Broinwood-style decorative inlay on the rail sides (workbook row 115).
4. Sand to 220 grit. Apply tung oil or shellac. Avoid heavy lacquer; not for tone reasons (the bars are isolated from the frame), but for finish-rub-off on the playing surface.
5. Add four self-adhesive 1/2 in rubber feet to the frame underside.
6. Mount all bars per the Mounting Workflow.
7. Strike-test the assembled instrument at soft, medium, and loud dynamics. Listen for buzz, rattle, or rod-on-bar contact. Record `framed` row in `validation.csv`.

## Final Checks

- [ ] All bars are labeled and match `family-spec.csv`.
- [ ] Cord captures every bar at both node holes; no cord rides between nodes.
- [ ] No metal-on-metal contact (bar-to-rod, bar-to-frame fastener).
- [ ] Every measured pitch has a `validation.csv` row, including pilot K-calibration.
- [ ] Every framed bar within +/- 5 cents at soft dynamics.
- [ ] No persistent buzz at any dynamic on any bar.
- [ ] At least two striker pairs included (suggested: hard rubber and brass).
- [ ] Sustain consistent across the row to within 30%.

## Maintenance

- Wipe aluminum bars with a microfiber cloth to remove fingerprints. Avoid abrasive polish; it changes mass.
- Inspect cords annually for fraying; replace before they fail.
- Replace rubber grommets every 5-10 years or when sustain drops noticeably.
- Re-tune any bar that drifts more than 10 cents (rare for aluminum unless the bar was bent or damaged).

## validation.csv

Target/measured values per bar; pilot stages for C5/A5/C7.

| member_id | target_note | target_hz | predicted_length_in | stage | measured_hz | cents_error | sustain_s | timbre | tuner | environment | notes |
| --- | --- | --- | --- | --- | --- | --- | --- | --- | --- | --- | --- |
| GLK-C5 | C5 | 523.251 | 9.883 | prebuild |  |  |  |  |  |  | Pilot low/longest bar; bounds K-constant + cut-long discipline. |
| GLK-Csharp5 | C#5 | 554.365 | 9.602 | prebuild |  |  |  |  |  |  |  |
| GLK-D5 | D5 | 587.330 | 9.328 | prebuild |  |  |  |  |  |  |  |
| GLK-Dsharp5 | D#5 | 622.254 | 9.063 | prebuild |  |  |  |  |  |  |  |
| GLK-E5 | E5 | 659.255 | 8.805 | prebuild |  |  |  |  |  |  |  |
| GLK-F5 | F5 | 698.456 | 8.554 | prebuild |  |  |  |  |  |  |  |
| GLK-Fsharp5 | F#5 | 739.989 | 8.311 | prebuild |  |  |  |  |  |  |  |
| GLK-G5 | G5 | 783.991 | 8.074 | prebuild |  |  |  |  |  |  |  |
| GLK-Gsharp5 | G#5 | 830.609 | 7.844 | prebuild |  |  |  |  |  |  |  |
| GLK-A5 | A5 | 880.000 | 7.621 | prebuild |  |  |  |  |  |  | A5 = 440·2 reference; mid-scale K check. |
| GLK-Asharp5 | A#5 | 932.328 | 7.404 | prebuild |  |  |  |  |  |  |  |
| GLK-B5 | B5 | 987.767 | 7.193 | prebuild |  |  |  |  |  |  |  |
| GLK-C6 | C6 | 1046.502 | 6.988 | prebuild |  |  |  |  |  |  |  |
| GLK-Csharp6 | C#6 | 1108.731 | 6.789 | prebuild |  |  |  |  |  |  |  |
| GLK-D6 | D6 | 1174.659 | 6.596 | prebuild |  |  |  |  |  |  |  |
| GLK-Dsharp6 | D#6 | 1244.508 | 6.408 | prebuild |  |  |  |  |  |  |  |
| GLK-E6 | E6 | 1318.510 | 6.226 | prebuild |  |  |  |  |  |  |  |
| GLK-F6 | F6 | 1396.913 | 6.049 | prebuild |  |  |  |  |  |  |  |
| GLK-Fsharp6 | F#6 | 1479.978 | 5.876 | prebuild |  |  |  |  |  |  |  |
| GLK-G6 | G6 | 1567.982 | 5.709 | prebuild |  |  |  |  |  |  |  |
| GLK-Gsharp6 | G#6 | 1661.219 | 5.547 | prebuild |  |  |  |  |  |  |  |
| GLK-A6 | A6 | 1760.000 | 5.389 | prebuild |  |  |  |  |  |  |  |
| GLK-Asharp6 | A#6 | 1864.655 | 5.235 | prebuild |  |  |  |  |  |  |  |
| GLK-B6 | B6 | 1975.533 | 5.086 | prebuild |  |  |  |  |  |  |  |
| GLK-C7 | C7 | 2093.005 | 4.941 | prebuild |  |  |  |  |  |  | Pilot high/shortest bar; validates short-bar dimensional sensitivity (~1% cent shift per ~0.025 in). |
| GLK-PENT-C5 | C5 | 523.251 | 9.883 | prebuild |  |  |  |  |  |  | Art-fair pentatonic; share aluminum stock with chromatic. |
| GLK-PENT-D5 | D5 | 587.330 | 9.328 | prebuild |  |  |  |  |  |  |  |
| GLK-PENT-E5 | E5 | 659.255 | 8.805 | prebuild |  |  |  |  |  |  |  |
| GLK-PENT-G5 | G5 | 783.991 | 8.074 | prebuild |  |  |  |  |  |  |  |
| GLK-PENT-A5 | A5 | 880.000 | 7.621 | prebuild |  |  |  |  |  |  |  |
| GLK-PENT-C6 | C6 | 1046.502 | 6.988 | prebuild |  |  |  |  |  |  |  |
| GLK-PENT-D6 | D6 | 1174.659 | 6.596 | prebuild |  |  |  |  |  |  |  |
| GLK-PENT-E6 | E6 | 1318.510 | 6.226 | prebuild |  |  |  |  |  |  |  |
| GLK-PENT-G6 | G6 | 1567.982 | 5.709 | prebuild |  |  |  |  |  |  |  |
| GLK-PENT-A6 | A6 | 1760.000 | 5.389 | prebuild |  |  |  |  |  |  |  |
| GLK-C5 | C5 | 523.251 | 9.883 | flat_bar |  |  |  |  |  |  | Cut-long aluminum blank; mass-and-strike test on foam supports before drilling node holes. |
| GLK-C5 | C5 | 523.251 | 9.883 | post_trim |  |  |  |  |  |  | After trim-to-length and deburr; supports at node positions; record measured Hz. |
| GLK-C5 | C5 | 523.251 | 9.883 | mounted |  |  |  |  |  |  | Cord through node holes with rubber grommets; supported on 1/8" stainless rod. |
| GLK-C5 | C5 | 523.251 | 9.883 | framed |  |  |  |  |  |  | Final walnut frame; check buzz at soft/medium/loud strikes; record sustain after first 6 dB drop. |
| GLK-A5 | A5 | 880.000 | 7.621 | flat_bar |  |  |  |  |  |  | Cut-long aluminum blank; mass-and-strike test on foam supports before drilling node holes. |
| GLK-A5 | A5 | 880.000 | 7.621 | post_trim |  |  |  |  |  |  | After trim-to-length and deburr; supports at node positions; record measured Hz. |
| GLK-A5 | A5 | 880.000 | 7.621 | mounted |  |  |  |  |  |  | Cord through node holes with rubber grommets; supported on 1/8" stainless rod. |
| GLK-A5 | A5 | 880.000 | 7.621 | framed |  |  |  |  |  |  | Final walnut frame; check buzz at soft/medium/loud strikes; record sustain after first 6 dB drop. |
| GLK-C7 | C7 | 2093.005 | 4.941 | flat_bar |  |  |  |  |  |  | Cut-long aluminum blank; mass-and-strike test on foam supports before drilling node holes. |
| GLK-C7 | C7 | 2093.005 | 4.941 | post_trim |  |  |  |  |  |  | After trim-to-length and deburr; supports at node positions; record measured Hz. |
| GLK-C7 | C7 | 2093.005 | 4.941 | mounted |  |  |  |  |  |  | Cord through node holes with rubber grommets; supported on 1/8" stainless rod. |
| GLK-C7 | C7 | 2093.005 | 4.941 | framed |  |  |  |  |  |  | Final walnut frame; check buzz at soft/medium/loud strikes; record sustain after first 6 dB drop. |

## supplier-rfq.md

RFQ template covering aluminum + alternates + walnut + hardware.

# Supplier RFQ - Glockenspiel C5-C7 Build

## Scope

Request quotes for one 25-bar C5-C7 chromatic glockenspiel prototype build, with optional materials for a 10-bar pentatonic art-fair variant. Prices, stock, and lead times are intentionally not assumed in this repo; verify current facts before purchasing.

## Bar Stock - Aluminum (Primary)

Please quote 6061-T6 aluminum flat bar suitable for tuned percussion bars.

Required:

- Dimensions: `0.250 in x 1.000 in` flat bar.
- Length: minimum 18 ft total per build (chromatic + pentatonic + pilot scrap).
- Temper: `T6` strongly preferred for consistent K constant.
- Surface: free of deep scratches in playing area.

Please return:

- Mill / mill lot identifier (so the K-calibration record stays traceable across rebuilds).
- Available temper variants and their K-constant impact, if known.
- Cutting service availability (longest single bar needed is 11 in cut from 12-ft stock).
- Mill cert availability for E and rho (used to recompute K_metal independently).

## Bar Stock - Alternate Metals (Optional)

Please quote alternate flat-bar options at the same `0.250 in x 1.000 in` cross-section, in lengths sufficient for one 25-bar build per metal:

| Metal | Spec | Use Case |
| --- | --- | --- |
| Brass C260 | Yellow brass C260 flat bar | Premium warm tone variant |
| Steel 1018 | Cold-rolled 1018 flat bar | Loud / sharp tone variant |
| 304 Stainless | 304 stainless steel flat bar | Outdoor / weather-resistant variant |
| Phosphor Bronze | C510 or C544 phosphor bronze flat bar | Best-sustain premium variant |

Each metal alters the K constant materially; the user will regenerate `family-spec.csv` from the workbook before cutting.

## Frame Hardwood

Please quote Black Walnut frame stock suitable for CNC-routed glockenspiel frames.

Required:

- Black Walnut, 4/4 dressed to `0.750 in` thick.
- Clear straight-grain stock; no checks in finished area.
- Minimum dimensions: enough for two rails (about `36 in x 3 in` finished) plus end caps and an optional accidental row.
- Quantity: enough for one frame plus 1 spare rail.

Acceptable substitutes (functionally equivalent for tuning purposes; aesthetics differ):

- Hard maple
- Cherry

## Hardware

Please quote:

- 550 paracord or low-stretch braided nylon cord, 4 mm diameter.
- Rubber grommets, `0.1875 in` ID, available in Shore 30A / 50A / 70A durometers (sample of three durometers required for pilot).
- 1/8 in 304 stainless steel rod in 36 in lengths (qty 2 minimum per build).
- Self-adhesive 1/2 in rubber feet (qty 4 per frame).
- Frame fastener kit: wood screws, threaded inserts, washers; prefer removable.

## Mallets

Please quote at least two pairs from the following:

- Hard rubber head (default), 1.0 in head dia, 8-10 in handle.
- Brass head (orchestral upgrade), 0.75 in head dia, 8-10 in handle.
- Lexan or Delrin head (alternate), 0.75-1.0 in head dia, 8-10 in handle.

## CNC and Bar Tooling

Please quote:

- 1/4 in carbide downcut spiral router bit, hardwood-capable.
- 1/8 in carbide upcut spiral router bit, hardwood-capable.
- 1/8 in V-bit (60 deg) for optional inlay.
- 3/16 in HSS or carbide drill bit for aluminum (brad-point or jobber).
- 80T or 100T carbide chop-saw blade for non-ferrous metals.

Include shank diameter, cut length, recommended feed/speed range, and replacement availability.

## Measurement

Please quote:

- Chromatic tuner or strobe with reliable readout up to 2.5 kHz (must read C7 = 2093 Hz). Peterson StroboClip HD or equivalent.

## Response Format

Please return:

```text
item
supplier part number
material/spec
actual dimensions / temper / lot id
quantity available
unit price
lead time
shipping estimate
notes/substitution risks
```

## visual-bom-brief.md

Image-forward visual BOM plate spec.

# Visual BOM Brief

## Goal

Create a visual BOM plate that lets another maker understand the glockenspiel build at a glance: bar set, walnut frame, mounting hardware, mallets, CNC and bar tooling, and measurement gear.

## Required Views

1. Hero view of the assembled C5-C7 chromatic glockenspiel on a finished walnut frame, mallets to one side.
2. Exploded view showing bars above the front and back walnut rails, with cord, grommets, and stainless support rods called out.
3. Detail inset for one bar: 3/16 in node holes, top/bottom faces, dimensional callouts (L, w, t).
4. Detail inset for the mounting cross-section: bar, grommet, cord, walnut pocket, stainless support rod.
5. Detail inset for one mallet pair (hard rubber default + brass upgrade).
6. Material swatches: 6061-T6 aluminum bar stock, Black Walnut frame stock, paracord, rubber grommets, stainless support rod, MDF/plywood jig stock.

## BOM Rows To Show

| Item | Visual Needed | Source |
| --- | --- | --- |
| Tuned aluminum bars | Actual shop photo once cut; concept placeholder acceptable before build | `family-spec.csv` |
| Alternate metals (Brass, Steel, SS, Phosphor Bronze) | Supplier image; small swatch row | `sourcing.csv` |
| Walnut frame stock | CAD render or shop photo | `cad/` |
| Paracord (mounting cord) | Supplier image or shop photo | `bom.csv` |
| Rubber grommets (3 durometers) | Supplier image with durometer label | `bom.csv` |
| 1/8 in stainless support rod | Supplier image or shop photo | `bom.csv` |
| Hard rubber + brass mallets | Shop photo | `bom.csv` |
| CNC bits (1/4 downcut, 1/8 upcut, 1/8 V-bit) | Supplier image | `bom.csv` |
| 3/16 in drill bit for aluminum | Supplier image | `bom.csv` |
| Chromatic tuner | Supplier image or shop photo | `validation.csv` workflow |

## Labeling Rules

- Label generated images as concept placeholders.
- Do not use generated images for exact dimensions.
- Every dimension callout must match `family-spec.csv` or be marked `TBD`.
- Keep supplier prices out of the visual until current quotes are verified.
- The five-metal K-comparison is a useful side panel (E vs rho scatter sized by K) — see workbook §6 row 165.

## First Plate Layout

Top: title (Glockenspiel C5-C7), date, range (C5-C7 chromatic + C-pentatonic art-fair), primary material (6061-T6 aluminum).

Middle left: exploded assembly with numbered callouts.

Middle right: BOM table grouped by bar set, frame, hardware, mallets, tooling, measurement.

Side panel: metal K-constant scatter (E vs rho axes, points sized by K). Shows aluminum/steel cluster vs brass/phosphor-bronze cluster.

Bottom: assumptions (workbook K is first-pass; pilot K-calibration required; durometer pilot required) and missing purchase-verification items.

## jig-decision.md

Pilot fixture decisions and release gates.

# Glockenspiel Jig Decision Record

Generated: 2026-05-08

## Purpose

This file is the manufacturing decision layer for the glockenspiel packet. The design table gives bar dimensions; the CNC setup sheet gives operations on the walnut frame. This record decides which jigs earn their way into the first build, what each jig controls, and which validation row proves the decision worked.

The active recommendation is a staged jig system, not one universal fixture. The pilot build should make only the jigs needed to cut, drill, and mount C5, A5, and C7. The remaining 22 chromatic bars wait until those three pilot bars validate K-constant, node-hole geometry, and mounting damping.

## Source Inputs

| Source | Used for |
| --- | --- |
| `family-spec.csv` | Bar length, width, thickness, node positions per note. |
| `design.md` | Free-free metal beam model, mounting strategy, K-calibration discipline. |
| `cnc/setup-sheet.md` | Operation sequence, datum scheme, tool list, pilot gate. |
| `drawings/GLK-C5-body.svg`, `GLK-A5-body.svg`, `GLK-C7-body.svg` | Per-pilot dimensioned drawings. |
| `drawings/mounting-detail.svg` | Node-hole + grommet + cord + stainless-rod section. |
| `drawings/frame-layout.svg` | Piano-keyboard layout, naturals-front / sharps-back rows. |
| `validation.csv` | Measurement rows that decide whether to scale from pilot to full set. |

## Datum Rules

| Datum | Meaning | Must survive |
| --- | --- | --- |
| A | Top face of the bar | Cut to length, drill, deburr, strike test, mounting. |
| B | Left end of the bar | Length mark, node mark 1, drill hole 1. |
| C | Bar centerline | Node hole drilling, mounting, frame layout. |

If a jig loses A/B/C, the bar is no longer traceable to `family-spec.csv`; stop and remark before cutting.

## Pilot Decision

| Pilot bar | Why it is in the pilot | Pass gate before full set |
| --- | --- | --- |
| C5 | Longest bar (9.883 in), lowest pitch (523 Hz). Validates the workbook K constant against the actual stock. | Cut-long blank Hz produces K_eff within 5% of workbook K. Measured Hz after trim within +/- 10 cents of target. Sustain >= 3 s. |
| A5 | A5 = 880 Hz reference (one octave above orchestral A4). Mid-scale K check. | Measured Hz within +/- 5 cents of 880 Hz after trim. Mounting does not damp below 1.5 s sustain. |
| C7 | Shortest bar (4.941 in), highest pitch (2093 Hz). Validates dimensional sensitivity (a 0.025 in length change shifts pitch ~1%). | Trim discipline can land C7 within +/- 10 cents in 0.05 in length increments. Striker hardness is musical, not harsh. |

Full production is blocked until these rows in `validation.csv` have measured values: `flat_bar`, `post_trim`, `mounted`, `framed` for C5, A5, and C7.

## Decision Matrix

| Decision ID | Operation | Chosen jig | Why this choice | Go/no-go test |
| --- | --- | --- | --- | --- |
| JD-010 | Receive and verify aluminum stock | Calipers, scratch-awl marking station | Stock dimension and surface quality must be confirmed before cut planning. | Thickness 0.250 +/- 0.005 in, width 1.000 +/- 0.010 in, no deep scratches in playing area. |
| JD-020 | Mark bar length and node positions | Stop-block sled with scribe and centerline gauge | Repeatability matters more than speed; a misplaced node hole damps the bar. | Length within +/- 0.020 in of `predicted_length_in + 0.25`; node 1/2 within +/- 0.020 in of `0.2242·L` and `0.7758·L`. |
| JD-030 | Cut to length | Chop saw with carbide non-ferrous blade and stop block, OR band saw with miter gauge | Chop saw is faster and squarer; band saw is safer for short pilot bars. Pick one and document. | Cut squareness <= 0.5 deg from perpendicular; deburred to no-snag. |
| JD-040 | Drill node holes | Drill press with V-block jig referenced to centerline, hardwood backer, depth stop | Holes off-axis or off-node will damp the bar; the V-block + backer is the standard pattern. | Holes 0.1875 +/- 0.005 in, perpendicular within 1 deg, no edge tear-out, deburred both faces. |
| JD-050 | Strike-test on pilot supports | Foam-block node-support cradle, dynamic mic, tuner | A consistent acoustic datum is required to compare flat vs mounted vs framed. | Same support spacing every test; measured Hz repeatable within 2 cents across three strikes. |
| JD-060 | Mounting prototype rig | Three short walnut blocks (drilled for grommets, slotted for cord, drilled for stainless rod), test cord | Sustain depends on grommet durometer and cord tension; need to test before frame routing. | Pilot bars retain >= 75% of flat-bar sustain when mounted. |
| JD-070 | Walnut frame layout template | Full-size paper or MDF template marked with chromatic bar positions, sharps/naturals rows, hand zones | Player reach must be validated before cutting walnut. | Player reaches all bars without shoulder strain; mallet trajectory clear of frame. |

## Rejected Fixture Options

| Rejected option | Reason |
| --- | --- |
| Single 25-bar CNC nest for all node-hole drilling | Too much aluminum in one fixture before pilot K is confirmed; one wrong K kills the lot. |
| Permanent press-fit grommets in finished walnut frame | Locks in durometer choice before pilot sustain test; rework requires destroying the frame. |
| Final furniture-grade walnut frame on first build | The frame should validate ergonomics, mallet reach, and grommet durometer before final joinery. |
| Resonator tubes under each bar | Out of scope per workbook §3 row 140; small bars at C5-C7 do not benefit from quarter-wave coupling at usable tube lengths. |
| Arch undercut (marimba-style) | Out of scope per workbook §3; metal bars want a dry, bright tone, not lowered fundamental. |

## Jig Build Order

1. Build only JD-010 through JD-050 for the pilot set.
2. Cut and measure C5, A5, C7 through `flat_bar` and `post_trim` validation rows.
3. Confirm K_eff and trim discipline before drilling node holes on remaining bars.
4. Build JD-060 (mounting prototype) with three durometer candidates; measure sustain.
5. Build JD-070 (frame template) and validate reach.
6. Cut the remaining 22 chromatic bars (and 7 additional pentatonic bars if both scales are being built) using the calibrated K and trim discipline.
7. Route the walnut frame; mount all bars; run final `framed` validation row.

## Validation Rows To Preserve

| Row pattern | Purpose | Release threshold |
| --- | --- | --- |
| `flat_bar` | Cut-long blank Hz; K-calibration. | K_eff within 5% of workbook K, or workbook K updated. |
| `post_trim` | After trim-to-length and deburr; supports at nodes. | Within +/- 10 cents of target Hz for pilot bars. |
| `mounted` | After cord + grommet + stainless rod mounting on test rig. | Sustain >= 75% of flat-bar sustain; pitch shift <= 5 cents. |
| `framed` | After installation in final walnut frame. | Within +/- 5 cents at soft dynamics; no buzz at any dynamic. |

## Open Decisions

- Final grommet durometer (Shore 30A vs 50A vs 70A) remains TBD until pilot sustain measurements.
- Striker hardness selection (brass vs hard rubber vs lexan/Delrin) — at minimum two pairs ship with the instrument; let the player pick.
- Whether the first build uses a temporary MDF validation frame or jumps directly to walnut.
- Whether the chromatic and pentatonic builds share one frame jig with two drilling templates, or use independent jigs.
- Whether to run a parallel brass / phosphor-bronze pilot (one C5 bar in each metal) to validate the K library beyond aluminum.

## risks.md

Acoustic / structural / ergonomic / supply / fit-finish risks.

# Glockenspiel Risk Register

## Acoustic Risks

### Bar pitch misses workbook prediction (K-constant variance)

- Risk: Selected 6061-T6 aluminum stock has a different effective K than the workbook value of 204431. Heat-treat condition (T6 vs T4 vs annealed), extrusion vs sawn flat-bar, cold-work history, and dimensional tolerance all shift effective K by 5-10%.
- Impact: Every bar cut to `predicted_length_in` lands sharp or flat by a consistent amount; without trim allowance the entire batch is scrap.
- Test: Cut C5, A5, C7 pilot bars cut-long by 0.25 in. Mount on foam at nodes. Compute `K_eff = f * L^2 / t` from measured Hz.
- Pass criterion: Pilot K_eff differs from workbook K by less than 5%, or the workbook K is updated to match before the remaining 22 bars are cut.
- Mitigation: Always cut bars at predicted length + 0.25 in. Tune by removing material from both ends. Update `family-spec.csv` and workbook B21 with the calibrated K.

### Mounting damps fundamental or kills sustain

- Risk: Rubber grommet durometer, cord tension, or stainless support rod contact damps the free-free first mode. Free-free bars require contact only at the nodes; any contact away from the node line shortens sustain.
- Impact: Bars sound dead, sustain drops below 1 second, or pitch shifts flat under load.
- Test: Pilot each grommet candidate (Shore 30A, 50A, 70A) on C5/A5/C7. Measure sustain to first 6 dB drop after a moderate strike.
- Pass criterion: Sustain >= 3 s for C5 fundamental, >= 1.5 s for A5, >= 0.8 s for C7. Pitch shift under mounting <= 5 cents from flat-bar measurement.
- Mitigation: Soften grommets, increase node-hole diameter, or relocate the support rod so it does not contact the bar between nodes.

### Striker hardness produces unwanted timbre

- Risk: Brass strikers on aluminum bars produce a harsh, ear-piercing attack at C7 frequencies (above 2 kHz).
- Impact: Player or audience experiences listening fatigue; instrument is unpleasant in small rooms.
- Test: Strike each pilot bar with brass, hard rubber, and lexan strikers. Record perceived timbre and decay.
- Pass criterion: At least one striker option produces a tone judged "musical" rather than "harsh" by two listeners in the build space.
- Mitigation: Ship the instrument with hard-rubber strikers as the default and brass as an optional upgrade; document the trade-off in the assembly manual.

## Structural Risks

### Drilling node holes splits or burrs the aluminum

- Risk: Drilling 3/16 in holes through 1/4 in flat bar without proper backing causes burr-up, edge tear-out, or work-hardening.
- Impact: Cracked bar, rough hole, asymmetric mounting, audible buzz at the node.
- Test: Drill sample holes in offcut aluminum with the intended bit and backing board. Inspect for clean entry/exit and freedom from burrs.
- Pass criterion: Clean holes, no visible burrs after deburring, no cracks visible under magnification.
- Mitigation: Use a sharp HSS or carbide bit, peck-drill through hardwood backer, deburr both faces, lubricate with cutting fluid.

### Bar-to-stainless-rod metal contact buzz

- Risk: 1/8 in stainless support rod contacts the underside of a bar between the cord supports, causing audible buzz at moderate-to-loud strike intensity.
- Impact: Metallic rattle on every strike; instrument is unusable for performance.
- Test: Strike each bar at three dynamic levels (soft, medium, loud) on the assembled frame.
- Pass criterion: No audible rattle or buzz at any dynamic.
- Mitigation: Lower the stainless rod relative to the bar, add a continuous foam strip on top of the rod, or remove the rod and rely on cord-only mounting.

## Ergonomic Risks

### Frame too wide for player reach

- Risk: 25-bar chromatic frame is about 33 in wide. With sharps in a back row offset 0.5 in higher, the playing surface depth approaches 4 in.
- Impact: Player cannot reach center bars without leaning; mallet strikes lose accuracy at the edges.
- Test: Tape a full-size bar layout on a bench and have the intended player reach every bar from a normal stance.
- Pass criterion: All 25 bars reachable without shoulder strain in less than 1 second per note.
- Mitigation: Reduce range to two octaves (C5-C6, 13 bars), use the pentatonic 10-bar variant, or split the chromatic into a stacked / curved frame.

### Mallet handle length wrong for table-height frame

- Risk: Stock 8-10 in mallet handles assume the frame sits at standing-shop-bench height (~36 in). A seated player at a 30 in table will overshoot strikes.
- Impact: Inconsistent attack; player cannot control dynamics.
- Test: Strike each bar at the intended playing surface height; measure mallet head trajectory.
- Pass criterion: Mallet head can land flat on the bar center without forearm strain.
- Mitigation: Provide both handle lengths, or specify the intended playing surface height in the BOM.

## Supply Risks

### Aluminum stock lot variation

- Risk: Different mill lots of 6061-T6 1/4 in x 1 in flat bar carry slightly different temper and effective K. A second build using a new lot can produce systematically different pitches.
- Impact: Second-batch instrument plays out of tune relative to first.
- Test: Each new aluminum lot triggers a fresh K-calibration pilot (C5/A5/C7 only).
- Pass criterion: Each lot's K_eff is documented in `validation.csv` and `family-spec.csv` is updated before the run.
- Mitigation: Treat K as a per-lot parameter. Buy enough stock for a complete instrument from one mill lot.

### Walnut frame stock availability

- Risk: Clear straight-grain Black Walnut for the CNC-routed frame may be expensive or out of stock locally.
- Impact: Build delay or fall-back to a less attractive frame wood.
- Test: Quote walnut, hard maple, cherry from local hardwood dealers before committing.
- Pass criterion: Selected wood available within the build's lead-time budget at acceptable cost.
- Mitigation: Hard maple is an acceptable substitute for the frame; cherry works if walnut is unavailable. None of these affect bar tuning.

### Metal supplier substitution risk (alternative metals)

- Risk: If the user switches from aluminum to brass / steel / stainless / phosphor bronze, the K constant changes by up to 30%. Reusing a packet computed for aluminum produces wildly wrong lengths.
- Impact: Whole-batch scrap.
- Test: Verify `material` and `k_constant` columns in `family-spec.csv` match the actual metal before any cutting.
- Pass criterion: Metal name and K constant match.
- Mitigation: Regenerate `family-spec.csv` from the workbook with the new K value before cutting. Document the swap in `validation.csv` notes.

## Fit And Finish Risks

### Clear-coat finish detunes bars

- Risk: Lacquer or clear coat on aluminum adds mass and damping; pitch can drop 3-10 cents and sustain can shorten.
- Impact: Bars finished after tuning play flat.
- Test: Apply finish to one offcut and one tuned sacrificial bar. Measure Hz before and after.
- Pass criterion: Pitch shift predictable within +/- 5 cents and within final tuning allowance.
- Mitigation: Use a thin finish, tune after finish, or leave bars raw with periodic light polish.

### Frame buzz from loose hardware

- Risk: Wood screws, threaded inserts, washers, or rubber feet rattle against the frame at moderate-to-loud strikes.
- Impact: Buzz on every strike; instrument fails final validation.
- Test: Strike every bar at soft / medium / loud dynamics on the fully assembled frame; listen for any non-bar sound source.
- Pass criterion: No audible buzz at any dynamic.
- Mitigation: Add thread-locker, soft washers, or felt pads under hardware. Replace rubber feet if they shed grip on the playing surface.

## photo-shotlist.md

Build-log photo plan.

# Photo Shotlist

This shotlist follows the repo-level photo pipeline expectations from `instrument-maker/docs/photo-pipeline.md`: capture real process images first, use generated or supplier images only as labeled placeholders, and keep build-log image names stable enough for `site/index.html`.

## Intake And Materials

- `images/01-workbook-table.png`: screenshot of `glockenspiel-design-table.xlsx` showing the Glockenspiel sheet with K library and bar calculator.
- `images/02-aluminum-stock.jpg`: rough 6061-T6 flat bar with ruler and mill-cert label visible.
- `images/03-walnut-frame-stock.jpg`: walnut boards selected for the frame, with a grain-direction arrow.
- `images/04-hardware-options.jpg`: three durometer rubber grommets, paracord, 1/8 in stainless rod laid out for the durometer pilot.
- `images/05-mallets-options.jpg`: hard rubber, brass, and lexan/Delrin mallet pairs side-by-side.

## Bar Fabrication

- `images/10-bar-marking.jpg`: stop-block sled with C5 blank marked for length and node positions.
- `images/11-bar-cutting.jpg`: chop saw or band saw cutting C5 to length.
- `images/12-bar-deburr.jpg`: deburred bar end close-up.
- `images/13-node-drilling.jpg`: drill press with V-block jig and hardwood backer drilling node hole.
- `images/14-node-hole-detail.jpg`: clean 3/16 in hole through the bar.

## Tuning And Mounting

- `images/20-flat-bar-strike.jpg`: pilot bar on foam supports at nodes with tuner reading Hz.
- `images/21-trim-to-pitch.jpg`: belt sander or fine file removing material symmetrically from both ends.
- `images/22-mounting-rig.jpg`: three-block prototype rig with three durometer grommets ready for sustain comparison.
- `images/23-cord-thread.jpg`: paracord threaded through node holes of one row.

## Frame And Final Assembly

- `images/30-frame-routing.jpg`: walnut rail on CNC router with grommet pockets cut.
- `images/31-frame-layout-test.jpg`: full-size paper template on bench for ergonomic check.
- `images/32-mounted-row.jpg`: full natural row mounted in walnut rail.
- `images/33-finished-front.jpg`: full instrument front view.
- `images/34-finished-side.jpg`: side view showing accidental row offset.
- `images/35-detail-grommet.jpg`: close-up of one bar in its grommet, showing isolation from frame.

## Validation

- `images/40-pilot-c5-tuning.jpg`: C5 framed and measured.
- `images/41-pilot-a5-tuning.jpg`: A5 framed and measured.
- `images/42-pilot-c7-tuning.jpg`: C7 framed and measured.
- `images/43-validation-log.jpg`: tuner, mic, and `validation.csv` workflow on bench.
- `images/44-buzz-test.jpg`: buzz check at three dynamics on the assembled instrument.

## resources.md

Provenance, family context, public-safety inventory.

# Resources & Provenance

## Workbook Lineage

- Source workbook: `glockenspiel-design-table.xlsx` (committed to this repo).
  - Single sheet `Glockenspiel`, range `A1:L174`.
  - 94 formula cells, 16 blue input cells.
  - Five-metal K library (rows 14-20): 6061-T6 Aluminum, Brass C260, Steel 1018, 304 Stainless, Phosphor Bronze.
  - Two scale blocks: 25-bar chromatic C5-C7 (rows 23-49) and 10-bar C-major pentatonic (rows 92-110).
  - Wolfram notebook spec (rows 129-159) and Wolfram exploration ideas (rows 161-174).

## Instrument Family Context

- Cultural origin: glockenspiel is a modern Western orchestral and military-band idiophone. The German name means "bells play"; the form derives from sets of small bells used in 18th-19th century military bands and was standardized as a bar instrument by Berlioz-era orchestras (1819+).
- Synonyms: orchestra bells, bell lyre (marching), orchestral bells (some scores).
- Distinguished from xylophone (wood bars, no arch) and marimba (wood bars, arch + resonators) by being metal bars without arch or resonator.

## Reference Repos

- `tonykoop/marimba` — closest sibling: free-free beam idiophone, same node math, same imperial K formulation, same validation discipline. The glockenspiel diverges by using metal instead of wood, omitting arch and resonator, and replacing wood K-table with metal K-table.
- `tonykoop/tongue-drum` — README convention and documentation standard reference.
- `tonykoop/instrument-maker` — catalog this repo is part of.

## Skill / Documentation Lineage

- Skill: `instrument-maker-v4` v4.3 root-mode.
- Reference docs consulted: `references/acoustic-models.md` (Free-Free Beams + empirical-correction guard rules), `references/new-instruments-v4.md` (Glockenspiel section), `references/repo-relationships.yaml` (cantilever-idiophone family).

## Empirical-Correction Guard Rules (Honest Inventory)

The following corrections do NOT apply to this packet:

- **NAF K2 corrections** (open-pipe flute bore-diameter table) — open-pipe flute model only.
- **Vessel Helmholtz corrections** — applies to ocarina/udu/gemshorn, not free-free beams.
- **Cantilever wood K-table** — applies to fixed-free wood beams (tongue drums), not free-free metal bars.
- **Marimba arch undercut math** — out of scope for metal bars (no arch).
- **Quarter-wave resonator math** — out of scope for this packet (no resonators).

The only correction loop that DOES apply: per-lot K calibration from pilot measurements, recorded in `validation.csv` and propagated to `family-spec.csv` and the workbook B21 cell.

## Public-Safety Inventory

- No private repo links.
- No local absolute paths in user-facing artifacts.
- No supplier prices frozen as facts (`current_price_status = not verified` throughout).
- No unlicensed images (no images currently committed; placeholders documented in `photo-shotlist.md`).
- No cultural-appropriation flags for the instrument category (modern Western orchestral instrument).
- License: CC BY 4.0 per existing `LICENSE` file.

## Open Provenance Questions

- Whether the K constants in the workbook material library should be regenerated from a single E/rho source (e.g., MatWeb) for traceability vs the current literature-pulled values.
- Whether to commit a small `data/k-library-source.csv` documenting where each K came from.
- Whether to add a "what would change for an outdoor sound-garden glockenspiel" appendix once the indoor build is validated.

## README.md

Project artifact.

# Glockenspiel

Engineering documentation and parametric design table for the glockenspiel — metal bar idiophone tuned via cantilever-beam scaling.

Part of the [tonykoop/instrument-maker](https://github.com/tonykoop/instrument-maker) catalogue.

> CAD renders, Wolfram notebook recordings, and a finalized build method are forthcoming.

## License

[CC BY 4.0](LICENSE) — see LICENSE for details.

## family-spec.csv

25 chromatic + 10 pentatonic bar dimensions.

| member_id | target_note | midi | target_hz | predicted_length_in | predicted_width_in | predicted_thick_in | node_1_in | node_2_in | material | k_constant | scale_label | notes |
| --- | --- | --- | --- | --- | --- | --- | --- | --- | --- | --- | --- | --- |
| GLK-C5 | C5 | 72 | 523.251 | 9.883 | 1.000 | 0.250 | 2.216 | 7.667 | 6061-T6 Aluminum | 204431 | C5-C7 chromatic | Workbook-derived from Glockenspiel sheet (rows 25-49); free-free metal beam, 6061-T6 K=204431; nodes at 0.224·L and 0.776·L; metal bars carry NO arch undercut and NO resonator (workbook §3 row 140). |
| GLK-Csharp5 | C#5 | 73 | 554.365 | 9.602 | 1.000 | 0.250 | 2.153 | 7.449 | 6061-T6 Aluminum | 204431 | C5-C7 chromatic | Workbook-derived from Glockenspiel sheet (rows 25-49); free-free metal beam, 6061-T6 K=204431; nodes at 0.224·L and 0.776·L; metal bars carry NO arch undercut and NO resonator (workbook §3 row 140). |
| GLK-D5 | D5 | 74 | 587.330 | 9.328 | 1.000 | 0.250 | 2.091 | 7.237 | 6061-T6 Aluminum | 204431 | C5-C7 chromatic | Workbook-derived from Glockenspiel sheet (rows 25-49); free-free metal beam, 6061-T6 K=204431; nodes at 0.224·L and 0.776·L; metal bars carry NO arch undercut and NO resonator (workbook §3 row 140). |
| GLK-Dsharp5 | D#5 | 75 | 622.254 | 9.063 | 1.000 | 0.250 | 2.032 | 7.031 | 6061-T6 Aluminum | 204431 | C5-C7 chromatic | Workbook-derived from Glockenspiel sheet (rows 25-49); free-free metal beam, 6061-T6 K=204431; nodes at 0.224·L and 0.776·L; metal bars carry NO arch undercut and NO resonator (workbook §3 row 140). |
| GLK-E5 | E5 | 76 | 659.255 | 8.805 | 1.000 | 0.250 | 1.974 | 6.831 | 6061-T6 Aluminum | 204431 | C5-C7 chromatic | Workbook-derived from Glockenspiel sheet (rows 25-49); free-free metal beam, 6061-T6 K=204431; nodes at 0.224·L and 0.776·L; metal bars carry NO arch undercut and NO resonator (workbook §3 row 140). |
| GLK-F5 | F5 | 77 | 698.456 | 8.554 | 1.000 | 0.250 | 1.918 | 6.636 | 6061-T6 Aluminum | 204431 | C5-C7 chromatic | Workbook-derived from Glockenspiel sheet (rows 25-49); free-free metal beam, 6061-T6 K=204431; nodes at 0.224·L and 0.776·L; metal bars carry NO arch undercut and NO resonator (workbook §3 row 140). |
| GLK-Fsharp5 | F#5 | 78 | 739.989 | 8.311 | 1.000 | 0.250 | 1.863 | 6.447 | 6061-T6 Aluminum | 204431 | C5-C7 chromatic | Workbook-derived from Glockenspiel sheet (rows 25-49); free-free metal beam, 6061-T6 K=204431; nodes at 0.224·L and 0.776·L; metal bars carry NO arch undercut and NO resonator (workbook §3 row 140). |
| GLK-G5 | G5 | 79 | 783.991 | 8.074 | 1.000 | 0.250 | 1.810 | 6.264 | 6061-T6 Aluminum | 204431 | C5-C7 chromatic | Workbook-derived from Glockenspiel sheet (rows 25-49); free-free metal beam, 6061-T6 K=204431; nodes at 0.224·L and 0.776·L; metal bars carry NO arch undercut and NO resonator (workbook §3 row 140). |
| GLK-Gsharp5 | G#5 | 80 | 830.609 | 7.844 | 1.000 | 0.250 | 1.759 | 6.085 | 6061-T6 Aluminum | 204431 | C5-C7 chromatic | Workbook-derived from Glockenspiel sheet (rows 25-49); free-free metal beam, 6061-T6 K=204431; nodes at 0.224·L and 0.776·L; metal bars carry NO arch undercut and NO resonator (workbook §3 row 140). |
| GLK-A5 | A5 | 81 | 880.000 | 7.621 | 1.000 | 0.250 | 1.709 | 5.912 | 6061-T6 Aluminum | 204431 | C5-C7 chromatic | Workbook-derived from Glockenspiel sheet (rows 25-49); free-free metal beam, 6061-T6 K=204431; nodes at 0.224·L and 0.776·L; metal bars carry NO arch undercut and NO resonator (workbook §3 row 140). |
| GLK-Asharp5 | A#5 | 82 | 932.328 | 7.404 | 1.000 | 0.250 | 1.660 | 5.744 | 6061-T6 Aluminum | 204431 | C5-C7 chromatic | Workbook-derived from Glockenspiel sheet (rows 25-49); free-free metal beam, 6061-T6 K=204431; nodes at 0.224·L and 0.776·L; metal bars carry NO arch undercut and NO resonator (workbook §3 row 140). |
| GLK-B5 | B5 | 83 | 987.767 | 7.193 | 1.000 | 0.250 | 1.613 | 5.580 | 6061-T6 Aluminum | 204431 | C5-C7 chromatic | Workbook-derived from Glockenspiel sheet (rows 25-49); free-free metal beam, 6061-T6 K=204431; nodes at 0.224·L and 0.776·L; metal bars carry NO arch undercut and NO resonator (workbook §3 row 140). |
| GLK-C6 | C6 | 84 | 1046.502 | 6.988 | 1.000 | 0.250 | 1.567 | 5.422 | 6061-T6 Aluminum | 204431 | C5-C7 chromatic | Workbook-derived from Glockenspiel sheet (rows 25-49); free-free metal beam, 6061-T6 K=204431; nodes at 0.224·L and 0.776·L; metal bars carry NO arch undercut and NO resonator (workbook §3 row 140). |
| GLK-Csharp6 | C#6 | 85 | 1108.731 | 6.789 | 1.000 | 0.250 | 1.522 | 5.267 | 6061-T6 Aluminum | 204431 | C5-C7 chromatic | Workbook-derived from Glockenspiel sheet (rows 25-49); free-free metal beam, 6061-T6 K=204431; nodes at 0.224·L and 0.776·L; metal bars carry NO arch undercut and NO resonator (workbook §3 row 140). |
| GLK-D6 | D6 | 86 | 1174.659 | 6.596 | 1.000 | 0.250 | 1.479 | 5.117 | 6061-T6 Aluminum | 204431 | C5-C7 chromatic | Workbook-derived from Glockenspiel sheet (rows 25-49); free-free metal beam, 6061-T6 K=204431; nodes at 0.224·L and 0.776·L; metal bars carry NO arch undercut and NO resonator (workbook §3 row 140). |
| GLK-Dsharp6 | D#6 | 87 | 1244.508 | 6.408 | 1.000 | 0.250 | 1.437 | 4.972 | 6061-T6 Aluminum | 204431 | C5-C7 chromatic | Workbook-derived from Glockenspiel sheet (rows 25-49); free-free metal beam, 6061-T6 K=204431; nodes at 0.224·L and 0.776·L; metal bars carry NO arch undercut and NO resonator (workbook §3 row 140). |
| GLK-E6 | E6 | 88 | 1318.510 | 6.226 | 1.000 | 0.250 | 1.396 | 4.830 | 6061-T6 Aluminum | 204431 | C5-C7 chromatic | Workbook-derived from Glockenspiel sheet (rows 25-49); free-free metal beam, 6061-T6 K=204431; nodes at 0.224·L and 0.776·L; metal bars carry NO arch undercut and NO resonator (workbook §3 row 140). |
| GLK-F6 | F6 | 89 | 1396.913 | 6.049 | 1.000 | 0.250 | 1.356 | 4.693 | 6061-T6 Aluminum | 204431 | C5-C7 chromatic | Workbook-derived from Glockenspiel sheet (rows 25-49); free-free metal beam, 6061-T6 K=204431; nodes at 0.224·L and 0.776·L; metal bars carry NO arch undercut and NO resonator (workbook §3 row 140). |
| GLK-Fsharp6 | F#6 | 90 | 1479.978 | 5.876 | 1.000 | 0.250 | 1.318 | 4.559 | 6061-T6 Aluminum | 204431 | C5-C7 chromatic | Workbook-derived from Glockenspiel sheet (rows 25-49); free-free metal beam, 6061-T6 K=204431; nodes at 0.224·L and 0.776·L; metal bars carry NO arch undercut and NO resonator (workbook §3 row 140). |
| GLK-G6 | G6 | 91 | 1567.982 | 5.709 | 1.000 | 0.250 | 1.280 | 4.429 | 6061-T6 Aluminum | 204431 | C5-C7 chromatic | Workbook-derived from Glockenspiel sheet (rows 25-49); free-free metal beam, 6061-T6 K=204431; nodes at 0.224·L and 0.776·L; metal bars carry NO arch undercut and NO resonator (workbook §3 row 140). |
| GLK-Gsharp6 | G#6 | 92 | 1661.219 | 5.547 | 1.000 | 0.250 | 1.244 | 4.303 | 6061-T6 Aluminum | 204431 | C5-C7 chromatic | Workbook-derived from Glockenspiel sheet (rows 25-49); free-free metal beam, 6061-T6 K=204431; nodes at 0.224·L and 0.776·L; metal bars carry NO arch undercut and NO resonator (workbook §3 row 140). |
| GLK-A6 | A6 | 93 | 1760.000 | 5.389 | 1.000 | 0.250 | 1.208 | 4.181 | 6061-T6 Aluminum | 204431 | C5-C7 chromatic | Workbook-derived from Glockenspiel sheet (rows 25-49); free-free metal beam, 6061-T6 K=204431; nodes at 0.224·L and 0.776·L; metal bars carry NO arch undercut and NO resonator (workbook §3 row 140). |
| GLK-Asharp6 | A#6 | 94 | 1864.655 | 5.235 | 1.000 | 0.250 | 1.174 | 4.062 | 6061-T6 Aluminum | 204431 | C5-C7 chromatic | Workbook-derived from Glockenspiel sheet (rows 25-49); free-free metal beam, 6061-T6 K=204431; nodes at 0.224·L and 0.776·L; metal bars carry NO arch undercut and NO resonator (workbook §3 row 140). |
| GLK-B6 | B6 | 95 | 1975.533 | 5.086 | 1.000 | 0.250 | 1.140 | 3.946 | 6061-T6 Aluminum | 204431 | C5-C7 chromatic | Workbook-derived from Glockenspiel sheet (rows 25-49); free-free metal beam, 6061-T6 K=204431; nodes at 0.224·L and 0.776·L; metal bars carry NO arch undercut and NO resonator (workbook §3 row 140). |
| GLK-C7 | C7 | 96 | 2093.005 | 4.941 | 1.000 | 0.250 | 1.108 | 3.834 | 6061-T6 Aluminum | 204431 | C5-C7 chromatic | Workbook-derived from Glockenspiel sheet (rows 25-49); free-free metal beam, 6061-T6 K=204431; nodes at 0.224·L and 0.776·L; metal bars carry NO arch undercut and NO resonator (workbook §3 row 140). |
| GLK-PENT-C5 | C5 | 72 | 523.251 | 9.883 | 1.000 | 0.250 | 2.216 | 7.667 | 6061-T6 Aluminum | 204431 | C major pentatonic art-fair | Art-fair C major pentatonic (workbook rows 94-103, alt scale row 122); same bar stock and K as chromatic block; 10-bar set. |
| GLK-PENT-D5 | D5 | 74 | 587.330 | 9.328 | 1.000 | 0.250 | 2.091 | 7.237 | 6061-T6 Aluminum | 204431 | C major pentatonic art-fair | Art-fair C major pentatonic (workbook rows 94-103, alt scale row 122); same bar stock and K as chromatic block; 10-bar set. |
| GLK-PENT-E5 | E5 | 76 | 659.255 | 8.805 | 1.000 | 0.250 | 1.974 | 6.831 | 6061-T6 Aluminum | 204431 | C major pentatonic art-fair | Art-fair C major pentatonic (workbook rows 94-103, alt scale row 122); same bar stock and K as chromatic block; 10-bar set. |
| GLK-PENT-G5 | G5 | 79 | 783.991 | 8.074 | 1.000 | 0.250 | 1.810 | 6.264 | 6061-T6 Aluminum | 204431 | C major pentatonic art-fair | Art-fair C major pentatonic (workbook rows 94-103, alt scale row 122); same bar stock and K as chromatic block; 10-bar set. |
| GLK-PENT-A5 | A5 | 81 | 880.000 | 7.621 | 1.000 | 0.250 | 1.709 | 5.912 | 6061-T6 Aluminum | 204431 | C major pentatonic art-fair | Art-fair C major pentatonic (workbook rows 94-103, alt scale row 122); same bar stock and K as chromatic block; 10-bar set. |
| GLK-PENT-C6 | C6 | 84 | 1046.502 | 6.988 | 1.000 | 0.250 | 1.567 | 5.422 | 6061-T6 Aluminum | 204431 | C major pentatonic art-fair | Art-fair C major pentatonic (workbook rows 94-103, alt scale row 122); same bar stock and K as chromatic block; 10-bar set. |
| GLK-PENT-D6 | D6 | 86 | 1174.659 | 6.596 | 1.000 | 0.250 | 1.479 | 5.117 | 6061-T6 Aluminum | 204431 | C major pentatonic art-fair | Art-fair C major pentatonic (workbook rows 94-103, alt scale row 122); same bar stock and K as chromatic block; 10-bar set. |
| GLK-PENT-E6 | E6 | 88 | 1318.510 | 6.226 | 1.000 | 0.250 | 1.396 | 4.830 | 6061-T6 Aluminum | 204431 | C major pentatonic art-fair | Art-fair C major pentatonic (workbook rows 94-103, alt scale row 122); same bar stock and K as chromatic block; 10-bar set. |
| GLK-PENT-G6 | G6 | 91 | 1567.982 | 5.709 | 1.000 | 0.250 | 1.280 | 4.429 | 6061-T6 Aluminum | 204431 | C major pentatonic art-fair | Art-fair C major pentatonic (workbook rows 94-103, alt scale row 122); same bar stock and K as chromatic block; 10-bar set. |
| GLK-PENT-A6 | A6 | 93 | 1760.000 | 5.389 | 1.000 | 0.250 | 1.208 | 4.181 | 6061-T6 Aluminum | 204431 | C major pentatonic art-fair | Art-fair C major pentatonic (workbook rows 94-103, alt scale row 122); same bar stock and K as chromatic block; 10-bar set. |

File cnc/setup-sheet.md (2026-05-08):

# CNC / Manufacturing Setup Sheet — Glockenspiel

- Packet: `/mnt/c/Users/Tony/Documents/GitHub/glockenspiel`
- Family: `free-free-bar-idiophone-metal`
- Generated: 2026-05-08
- Machine note: Maker Nexus / home shop CNC router for the **walnut frame only**. Bar work is bench-top: chop saw or band saw + drill press + bench file + tuner. Verify exact CNC machine, spindle, collet, bed size, and hold-down before CAM.

## Assumptions

- This is a pre-CAM operation graph, not verified G-code.
- Active build range: C5-C7 chromatic, 25 bars (with optional 10-bar C-major-pentatonic art-fair variant sharing the same stock and frame jig).
- Source dimensions come from `family-spec.csv` and `glockenspiel-design-table.xlsx`.
- Bars are 6061-T6 aluminum flat stock at 0.250 in × 1.000 in. NO arch undercut, NO resonator tubes (per `design.md`).
- Walnut frame is the only true CNC operation. Pilot fixtures (cut sled, V-block drill jig, mounting rig) are MDF/scrap and built per `jig-decision.md`.
- Effective K constant is calibrated from C5/A5/C7 pilot measurements; workbook K = 204431 is a first-pass estimate.

## Pilot Gate

Cut C5, A5, C7 bars cut-long, drill node holes, strike-test, trim to pitch, and run the mounting prototype before any walnut is loaded on the CNC.

Release to full production only if:

- C5 cut-long Hz produces K_eff within 5% of workbook K, OR `family-spec.csv` is updated with the calibrated K and the workbook B21 cell is also updated.
- A5 trims to within +/- 5 cents of 880 Hz; mounting on the prototype rig does not damp below 1.5 s sustain.
- C7 trim discipline lands within +/- 10 cents in 0.05 in length increments.
- Mounting rig (OP-300) confirms a durometer choice (typically Shore 50A is the starting expectation).
- Frame layout template confirms ergonomic reach for the intended player.

## Operation Graph

### OP-010 — Review design package and pilot gate

- Machine: Bench
- Tool: `design.md`, `family-spec.csv`, `jig-decision.md`, calipers, tuner
- Workholding: Flat bench, drawing packet
- Datum: Top face A, left end B, bar centerline C
- Inputs: `design.md`, `family-spec.csv`, `drawings/family-overview.svg`, `validation.csv`
- Outputs: pilot-build checklist
- Checks:
  - C5/A5/C7 pilot bars identified.
  - Actual metal stock (mill lot) verified.
  - Full-set cutting held until pilot data is reviewed.

### OP-100 — Receive and verify aluminum stock

- Machine: Bench
- Tool: Calipers, scratch awl, scale
- Workholding: Flat bench
- Datum: Stock edge
- Inputs: `bom.csv`, `sourcing.csv`
- Outputs: Verified aluminum bar stock
- Checks:
  - Thickness `0.250 +/- 0.005 in`.
  - Width `1.000 +/- 0.010 in`.
  - No deep scratches in playing area.
  - Mill lot recorded for K-calibration traceability.

### OP-110 — Mark bar length and node positions

- Machine: Bench
- Tool: Stop-block sled (JD-020), square, fine marker, centerline gauge
- Workholding: Sled
- Datum: Left end B against fence; centerline C
- Inputs: `family-spec.csv`, `drawings/GLK-*-body.svg`
- Outputs: Marked blanks ready for cutting
- Checks:
  - Length within `+/- 0.020 in` of `predicted_length_in + 0.250 in` (cut-long discipline).
  - node_1 and node_2 within `+/- 0.020 in`.

### OP-120 — Cut bars to length

- Machine: Chop saw (preferred) or band saw with miter gauge
- Tool: 80T or 100T carbide blade for non-ferrous metals
- Workholding: Stop block, hold-down clamp
- Datum: Left end B against fence
- Inputs: `family-spec.csv`, `cut-list.csv`
- Outputs: Cut-long bar blanks
- Checks:
  - Cut squareness <= 0.5 deg from perpendicular.
  - Both ends deburred (light file or chamfer).
  - Each bar labeled with `member_id` and target Hz.

### OP-130 — Drill node holes

- Machine: Drill press
- Tool: 3/16 in HSS or carbide drill bit, hardwood backer, depth stop, optional cutting fluid
- Workholding: V-block jig (JD-040) clamped to drill-press table
- Datum: Left end B against jig fence; centerline C
- Inputs: `family-spec.csv`, `drawings/GLK-*-body.svg`
- Outputs: Bars with two clean node holes
- Checks:
  - Hole diameter `0.1875 +/- 0.005 in`.
  - Perpendicular within 1 deg.
  - No edge tear-out.
  - Both faces deburred.

### OP-140 — Strike-test on foam supports (flat_bar row)

- Machine: Bench
- Tool: Foam blocks at node positions, chromatic tuner (>= 2 kHz range), microphone
- Workholding: Foam node-support cradle (JD-050)
- Datum: Acoustic node datum
- Inputs: `validation.csv`, `family-spec.csv`
- Outputs: Measured Hz, sustain, timbre per pilot bar
- Checks:
  - K_eff = f * L^2 / t computed for each pilot.
  - Sustain to first 6 dB drop logged.
  - If K_eff differs from workbook K by more than 5%, update `family-spec.csv` and workbook B21 before cutting remaining bars.

### OP-150 — Trim to pitch (post_trim row)

- Machine: Bench / belt sander or fine bench file
- Tool: Belt sander or bench file, calipers, tuner
- Workholding: Hand-held; both ends accessible
- Datum: Acoustic-tuning datum (preserve symmetry)
- Inputs: `validation.csv`
- Outputs: Bars trimmed to within tuning tolerance
- Checks:
  - Material removed symmetrically from both ends (preserves node ratio).
  - Cents error logged in `validation.csv`.
  - Length recorded post-trim.

### OP-200 — Walnut frame: receive and inspect

- Machine: Bench
- Tool: Calipers, square, moisture meter (optional)
- Workholding: Flat bench
- Datum: Board edge
- Inputs: `bom.csv`, `sourcing.csv`
- Outputs: Verified walnut stock
- Checks:
  - Thickness `0.75 in` (or planed to it).
  - Straight grain through the finished rail area.
  - No checks running through the rail.

### OP-210 — Walnut frame: CNC fixture and datum verification

- Machine: CNC router
- Tool: Spoilboard surfacing bit, edge finder/probe, clamps/tape
- Workholding: Replaceable spoilboard, datum fence, optional vacuum + clamps
- Datum: Machine X0 at left rail end, Y0 at rail centerline, Z0 top face
- Inputs: `cnc/setup-sheet.md`, `drawings/frame-layout.svg`
- Outputs: Verified fixture, air-cut report
- Checks:
  - Spoilboard surfaced.
  - Clamps clear toolpath.
  - Sample air-cut passes before walnut is loaded.

### OP-220 — Walnut frame: rough rail profile and grommet pockets

- Machine: CNC router
- Tool: 1/4 in carbide downcut spiral (profile), 1/8 in carbide upcut spiral (pocket detail)
- Workholding: Spoilboard tape/clamps; tabs at non-stress regions
- Datum: Top face, left end, centerline
- Inputs: `family-spec.csv`, `cad/design-table-inputs.csv`, `drawings/frame-layout.svg`
- Outputs: Profiled walnut rails with grommet pockets
- Checks:
  - Pocket diameter and depth match `cad/sw-global-variables.csv` (`grommet_pocket_dia = 0.45 in`, `grommet_pocket_depth = 0.30 in`).
  - Rail length 33.25 in (chromatic) or 14.50 in (pentatonic).
  - Bar-to-bar spacing 1.25 in.
  - Front rail (15 naturals chromatic / 7 pentatonic) and back rail (10 sharps chromatic / 3 pentatonic) cut separately.

### OP-230 — Walnut frame: optional inlay engraving

- Machine: CNC router or diode laser
- Tool: 1/8 in V-bit (60 deg) for V-carve, OR diode laser for surface engraving
- Workholding: Same fixture as OP-220
- Datum: Same as OP-220
- Inputs: `drawing-brief.md`
- Outputs: Decorated rails (optional)
- Checks:
  - Engraving depth consistent across rail run.
  - No splintering or burn marks.
- Notes: Per workbook row 115, optional Broinwood-style decorative inlay or laser-engraved logo. Skip for the pilot build.

### OP-240 — Walnut frame: drill stainless rod and fastener holes

- Machine: CNC router or drill press
- Tool: 1/8 in drill bit (rod hole), pilot bits matched to selected fasteners
- Workholding: End-cap fixture or rail-end fixture
- Datum: Rail end face, rail centerline
- Inputs: `drawings/mounting-detail.svg`, `cad/sw-global-variables.csv`
- Outputs: Through-drilled rails and end caps
- Checks:
  - Rod hole diameter `0.140 +/- 0.005 in` (1/8 in nominal plus clearance).
  - Fastener holes match the selected hardware.
  - End-cap holes align with rail holes.
  - Slip-fit verified with the actual stainless rod before assembly.

### OP-300 — Mounting prototype rig (durometer pilot)

- Machine: Bench
- Tool: Three short walnut blocks (drilled and pocketed), three durometer grommets, paracord, 1/8 in stainless rod
- Workholding: Bench-top assembly
- Datum: Block centerline
- Inputs: `bom.csv`, `drawings/mounting-detail.svg`
- Outputs: Sustain and pitch-shift data per durometer
- Checks:
  - Sustain >= 75% of flat-bar sustain.
  - Pitch shift <= 5 cents from flat-bar measurement.
  - No buzz at three dynamic levels (soft / medium / loud).

### OP-400 — Frame assembly and bar mounting

- Machine: Bench
- Tool: Drivers, awl, scissors (paracord), tuner, mallets
- Workholding: Frame on workbench
- Datum: Frame centerline, end-cap reference
- Inputs: `assembly-manual.md`, `drawings/frame-layout.svg`, `drawings/mounting-detail.svg`
- Outputs: Assembled glockenspiel
- Checks:
  - All bars seated in grommet pockets.
  - Cord captures every bar at both node holes.
  - No metal-on-metal contact.
  - Stainless rod clears bars by at least 0.1 in.

### OP-500 — Final validation and release

- Machine: Bench
- Tool: Chromatic tuner, microphone, calipers, mallets (hard rubber default + brass upgrade), camera
- Workholding: Assembled instrument on stable stand
- Datum: Same support and strike datum used for every note
- Inputs: `validation.csv`, `photo-shotlist.md`
- Outputs: Updated `validation.csv`, process photos
- Checks:
  - Every framed bar within `+/- 5 cents` at soft dynamics.
  - No persistent buzz at soft / medium / loud dynamics on any bar.
  - Sustain consistent across the row to within 30%.

## Release Checks

- Every operation has a datum and workholding method.
- Every tool has a real machine available or an escalation note.
- All tuning-critical features include trim allowance.
- C5/A5/C7 pilot data is reviewed before cutting all 25 bars.
- Grommet durometer is selected from pilot data, not assumed.
- `validation.csv` receives measured data after the first prototype.
- K_eff is updated in `family-spec.csv` if it differs from workbook K by more than 5%.

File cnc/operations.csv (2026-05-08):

op_id | name | machine | tool | workholding | datum | primary_inputs | primary_outputs | release_check
OP-010 | Review design package and pilot gate | Bench | design.md, family-spec.csv, jig-decision.md | Flat bench | A/B/C from design.md | design.md;family-spec.csv;validation.csv | pilot-build checklist | Pilot bars identified and stock verified
OP-100 | Receive and verify aluminum stock | Bench | Calipers, scratch awl, scale | Flat bench | Stock edge | bom.csv;sourcing.csv | Verified aluminum bar stock | Thickness 0.250 +/- 0.005 in, width 1.000 +/- 0.010 in, mill lot recorded
OP-110 | Mark bar length and node positions | Bench | Stop-block sled, square, fine marker, centerline gauge | Sled per JD-020 | Left end B / centerline C | family-spec.csv;drawings/GLK-*-body.svg | Marked blanks ready for cutting | Length and node positions within +/- 0.020 in
OP-120 | Cut bars to length | Chop saw or band saw | 80T or 100T non-ferrous carbide blade | Stop block, hold-down clamp | Left end B against fence | family-spec.csv;cut-list.csv | Cut-long bar blanks | Cut squareness <= 0.5 deg; both ends deburred
OP-130 | Drill node holes | Drill press | 3/16 in HSS or carbide bit, hardwood backer, depth stop | V-block jig (JD-040) | Left end B / centerline C | family-spec.csv;drawings/GLK-*-body.svg | Bars with two clean node holes | Hole dia 0.1875 +/- 0.005 in; perpendicular within 1 deg
OP-140 | Strike-test on foam supports | Bench | Foam blocks, chromatic tuner, microphone | Foam node-support cradle (JD-050) | Acoustic node datum | validation.csv;family-spec.csv | Measured Hz / sustain / timbre per pilot | K_eff = f * L^2 / t computed for each pilot
OP-150 | Trim to pitch | Bench | Belt sander or bench file, calipers, tuner | Hand-held | Acoustic-tuning datum | validation.csv | Bars within tuning tolerance | Pilots within +/- 10 cents; production within +/- 5 cents
OP-200 | Walnut frame: receive and inspect | Bench | Calipers, square, moisture meter (optional) | Flat bench | Board edge | bom.csv;sourcing.csv | Verified walnut stock | Straight grain in finished area; thickness 0.75 in
OP-210 | Walnut frame: CNC fixture and datum verification | CNC router | Spoilboard surfacing bit, edge finder/probe, clamps/tape | Replaceable spoilboard | Machine X0/Y0/Z0 | cnc/setup-sheet.md;drawings/frame-layout.svg | Verified fixture / air-cut report | Air-cut passes; clamps clear toolpath
OP-220 | Walnut frame: rough rail profile and grommet pockets | CNC router | 1/4 in downcut spiral; 1/8 in upcut | Spoilboard tape/clamps | Top face / left end / centerline | family-spec.csv;cad/design-table-inputs.csv;drawings/frame-layout.svg | Profiled walnut rails with grommet pockets | Pocket dia/depth correct; bar-to-bar spacing 1.25 in
OP-230 | Walnut frame: optional inlay engraving | CNC router or laser | 1/8 in V-bit (60 deg) or diode laser | Same fixture as OP-220 | Same as OP-220 | drawing-brief.md | Decorated rails (optional) | Engraving consistent; skippable for pilot
OP-240 | Walnut frame: drill stainless rod and fastener holes | CNC router or drill press | 1/8 in bit + fastener pilot bits | End-cap or rail-end fixture | Rail end face / centerline | drawings/mounting-detail.svg;cad/sw-global-variables.csv | Through-drilled rails and end caps | Slip-fit verified with actual rod
OP-300 | Mounting prototype rig (durometer pilot) | Bench | Three walnut blocks, three durometer grommets, paracord, rod | Bench-top assembly | Block centerline | bom.csv;drawings/mounting-detail.svg | Sustain and pitch-shift data per durometer | Sustain >= 75% of flat-bar; pitch shift <= 5 cents; no buzz
OP-400 | Frame assembly and bar mounting | Bench | Drivers, awl, scissors, tuner | Frame on workbench | Frame centerline / end-cap reference | assembly-manual.md;drawings/mounting-detail.svg | Assembled glockenspiel | All bars seated; no metal-on-metal contact
OP-500 | Final validation and release | Bench | Chromatic tuner, microphone, mallets, camera | Assembled instrument on stable stand | Same strike datum every note | validation.csv;photo-shotlist.md | Updated validation.csv / process photos | Within +/- 5 cents at soft dynamic; no buzz at any dynamic

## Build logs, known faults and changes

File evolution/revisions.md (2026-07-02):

# Revision Register — glockenspiel

| Rev | Date | Parent | Delta | Downstream artifacts invalidated |
| --- | --- | --- | --- | --- |
| A | 2026-07-01 | — | Stage 0 intake of current masters (cad/glockenspiel-master.scad + glockenspiel-design-table.xlsx + family-spec.csv). | none (no alpha/beta/production artifacts exist yet) |

Stage 0 only. Gate A has not been run; no Alpha compiles, vendor quotes, or production lock exist for this product. Pilot bar calibration (C5/A5/C7) is still outstanding per design.md.

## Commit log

2026-05-02 Initial scaffold: Glockenspiel
    [glockenspiel-design-table.xlsx]
2026-05-18 feat(learn-to-play): add glockenspiel starter songbook (#3)
    * feat(learn-to-play): add glockenspiel starter songbook (R4 claude-dan)
    Drop learn-to-play/ with 00-INDEX.md, scales/, fingerings/, and
    5 tunes (ABC + LilyPond + songsheet + notes). All tunes are
    public-domain traditional arrangements or original Heifer Zephyr
    compositions (MIT). Notation is at concert pitch; no external
    rendering tools required to read the ABC files.
    * fix: strip trailing whitespace from learn-to-play songsheets
    ---------
2026-05-18 Add glockenspiel V5 explorer gates (#4)
    * Add glockenspiel V5 explorer gates
    * Remove local path references from Round 31 docs
    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
    [authority-ledger.csv, validation-loop.csv, visual-output-register.csv]
2026-05-31 Add image-gen concept prompt; wire explorer images
2026-05-31 Add deployable Wolfram interactive model + wire live explorer embed
    Model returns a bare Manipulate (SaveDefinitions->True); CloudDeploy'd Public.
2026-06-21 Wire 4 rendered concept image(s) into explorer gallery
2026-07-02 V5 packet refresh: status line, provenance, parametric OpenSCAD master, evolution intake
    Added missing Status line (repo had none) and backfilled
    cad/mcp-session-log.md provenance for pre-existing fabrication-authority
    artifacts (design table, family-spec, OpenSCAD/SolidWorks CAD masters).
    Kept cad/glockenspiel-master.scad unchanged per no-rewrite rule for
    existing masters. Validator: 0 failures, 0 warnings (full pass) — up from
    2 failures (no Status line; missing mcp-session-log.md).
    [visual-output-register.csv]
